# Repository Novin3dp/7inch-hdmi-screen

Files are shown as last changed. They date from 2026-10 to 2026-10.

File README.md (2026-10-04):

# برد راه‌انداز LCD هفت اینچ AT070TN92 با ورودی HDMI و تاچ USB

برد دولایه‌ی کوچک (۸۰×۵۰ میلی‌متر) که پشت LCD چسبانده می‌شود:

* **ورودی HDMI** (از رزبری‌پای) ← **LT8619C** ← RGB موازی ۲۴ بیتی (حالت DE) ← کانکتور FPC پنجاه‌پین **AT070TN92**
* **تاچ خازنی GT915** (روی FPC تاچ‌پنل، رابط I2C) ← **STM32F072** ← **USB HID Multi-Touch** (۵ نقطه) به رزبری‌پای
* **تغذیه‌ی کل برد از همان کابل USB-C** (۵ ولت از پورت USB رزبری‌پای)
* تولید ولتاژهای پنل روی برد: AVDD=10.4V، VGH=+16V، VGL=−6.8V، VCOM قابل تنظیم، درایور بک‌لایت جریان‌ثابت ۱۸۰ mA با PWM

> ⚠️ این طراحی کامل است و همه‌ی بررسی‌های نرم‌افزاری (DRC، تطبیق شماتیک با PCB، کامپایل فرم‌ور، اعتبارسنجی EDID) را پاس کرده، اما **هنوز ساخته و روی سخت‌افزار تست نشده است**. قبل از سفارش انبوه، یک نمونه بسازید و بخش «موارد قابل بررسی» را بخوانید.

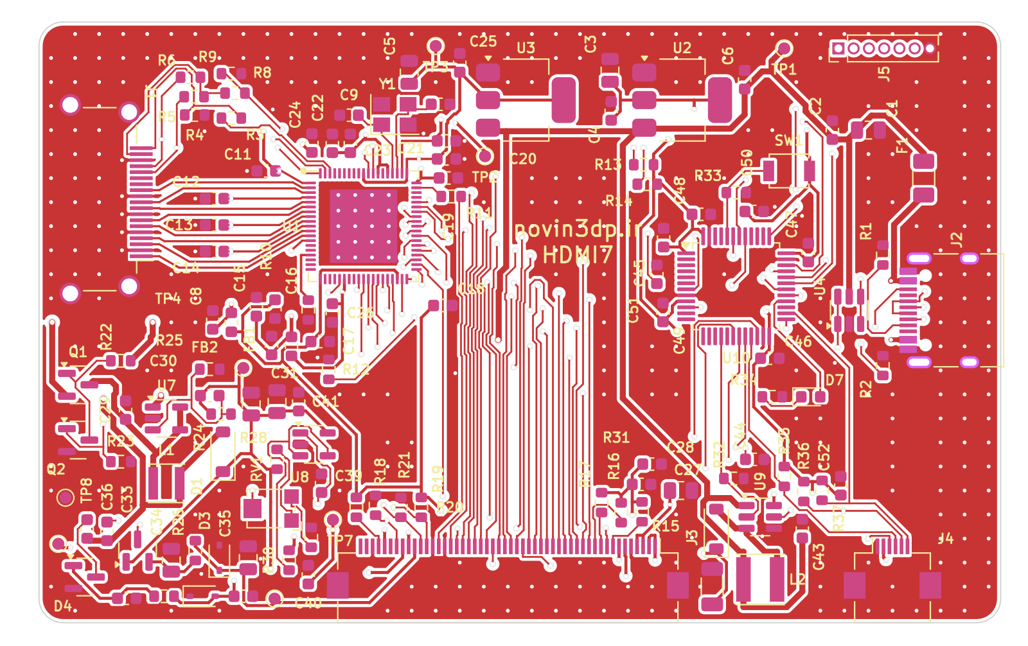
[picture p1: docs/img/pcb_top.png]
top


> **نسخه‌ی DSI:** یک برد جداگانه (۶۸×۴۲ mm) هم هست که همین پنل و تاچ را مستقیم از پورت DSI رزبری‌پای و با پل ICN6211 راه می‌اندازد، بدون HDMI و بدون میکروکنترلر. طراحی در [`hardware_dsi/`](hardware_dsi/README.md) و Overlay و درایور لینوکس در `rpi_dsi/` است.
>
> **نسخه‌ی STM32F042F6P6:** همین برد HDMI با میکروی کوچک‌تر TSSOP-20 در [`hardware_f042/`](hardware_f042/README.md). فرم‌ور با `make BOARD=f042` ساخته می‌شود.

---

## ۱) بلوک دیاگرام

```
 HDMI-A ──TMDS──► LT8619C ──RGB888 + DE + PCLK──► J3 (FPC 50P) ──► AT070TN92
   │ DDC/HPD        ▲ I2C1 (0x32)                       ▲ AVDD/VGH/VGL/VCOM, VLED
   └─(EDID روی تراشه)│                                    │
                    STM32F072 ──── BIAS_EN ──► TPS61040 + پمپ‌های بار + LM321 (VCOM)
 USB-C ◄──USB FS──► │ ──── BL_PWM ───► TPS61165 (بک‌لایت ۱۸۰mA)
   │5V              │ ──── I2C2 ────► J4 (FPC 6P) ──► تاچ‌پنل GT915
   └► PTC ► AMS1117-3.3 / AMS1117-1.8 (+ فیلتر فریت برای تغذیه‌های آنالوگ LT8619C)
```

| بخش | قطعه | توضیح |
|---|---|---|
| گیرنده HDMI | LT8619C (QFN76) | کریستال 25MHz، EDID داخلی 800×480@60 که میکرو بارگذاری می‌کند؛ VTERM/VCCA33 و 1.8V آنالوگ با فریت جدا شده‌اند |
| میکرو | STM32F072CBT6 | USB بدون کریستال (HSI48 + CRS)، بوت‌لودر DFU داخلی |
| بایاس پنل | TPS61040 + 2×BAT54S + زنر | AVDD 10.4V، VGH 16V (دوبرابرکننده)، VGL −6.8V (معکوس‌کننده) |
| VCOM | LM321 + تریمر 10k (RV1) | محدوده 2.55 تا 4.5 ولت، برای کمترین فلیکر تنظیم شود |
| بک‌لایت | TPS61165 | 0.2V / 1.1Ω = 182mA، PWM با فرکانس 20kHz |
| تغذیه | AMS1117-3.3 و AMS1117-1.8 | هر دو از 5V؛ 1.8V با فریت به تغذیه‌های آنالوگ |

---

## ۲) ساختار ریپازیتوری

```
hardware/                 پروژه‌ی KiCad (نسخه 7)
  lcd_board.kicad_pro/.kicad_sch/.kicad_pcb    پروژه، شماتیک سلسله‌مراتبی (۴ صفحه)، PCB
  lcd_board.pretty/       فوت‌پرینت‌های اختصاصی (QFN76 لونتیوم، FPC پنجاه‌پین)
  lcd_board.kicad_sym     سمبل LT8619C
  fab/                    فایل‌های ساخت: gerber.zip، BOM و CPL برای JLCPCB
  gen/                    اسکریپت‌هایی که کل طراحی را می‌سازند (منبع اصلی = design.py)
firmware/                 فرم‌ور STM32F072 (C + TinyUSB)
hardware_f042/            همین برد HDMI با STM32F042F6P6 — پروژه‌ی KiCad جدا با README خودش
hardware_dsi/             نسخه‌ی DSI (ICN6211) — پروژه‌ی KiCad جدا با README خودش
rpi_dsi/                  Device Tree Overlay و اسکریپت ساخت درایور ICN6211 برای نسخه‌ی DSI
docs/                     schematic.pdf، schematic_f042.pdf، schematic_dsi.pdf و تصاویر برد
*.pdf                     دیتاشیت‌ها
```

**منبع اصلی طراحی فایل `hardware/gen/design.py` است** (لیست قطعات و همه‌ی اتصالات). شماتیک، PCB و BOM از روی آن ساخته می‌شوند و `verify_netlist.py` تطابق شماتیک و طراحی را بررسی می‌کند. البته می‌توانید فایل‌های KiCad را مستقیم هم ویرایش کنید.

---

## ۳) مشخصات PCB

| مورد | مقدار |
|---|---|
| ابعاد | 80 × 50 mm، گوشه‌های گرد R2 |
| لایه | ۲ لایه، FR4، ضخامت پیشنهادی 1.0 یا 1.6 mm، مس 1oz |
| حداقل ترک/فاصله | 0.15 / 0.15 mm (تغذیه 0.25 و 0.5 mm) |
| ویا | سوراخ 0.3 / قطر 0.6 mm (ظرفیت استاندارد JLCPCB) |
| قطعات | **فقط روی رو (Top)**؛ پشت برد صاف است برای چسب دوطرفه |
| زمین | GND به‌صورت نت کامل مسیریابی شده + پور GND روی هر دو لایه + ~۳۰۰ ویای دوخت |
| DRC | **۰ خطای الکتریکی/فاصله و ۰ اتصال باز**؛ برچسب‌های سیلک بدون تداخل (هشدار فقط برای خطوط سیلک کانکتورهای لبه‌ی برد که سازنده برش می‌دهد) |
| سیلک‌اسکرین | برچسب‌ها با ارتفاع 0.8mm خودکار کنار هر قطعه گذاشته شده‌اند، روی پد/بدنه‌ی قطعه یا برچسب دیگر نمی‌افتند. ۱۳ برچسب در نواحی خیلی شلوغ جا نشدند و فقط در نقشه‌ی مونتاژ (`docs/img/pcb_assembly.png`) آمده‌اند |

نکات چیدمان:
* زوج‌های TMDS (HDMI) دستی و کوتاه (~۱۲ mm) کشیده شده‌اند و زیرشان لایه‌ی پشت زمین یکپارچه است. سرعت هر کانال برای 800×480 فقط 333Mbps است.
* خازن‌های دکاپلینگ پایه‌های VTERM/VCCA33 بین زوج‌های TMDS قرار گرفته‌اند.
* ترتیب پایه‌های RGB در LT8619C نسبت به FPC پنل وارونه است؛ گذرگاه RGB با ویا روی دو لایه جابه‌جا شده (بدون نیاز به رجیستر نامستند جابه‌جایی بیت).

---

## ۴) نصب مکانیکی و جهت FPC (مهم)

* FPC پنل (۳۰ میلی‌متر) از لبه‌ی پایین LCD به پشت تا می‌شود و از **لبه‌ی پایین برد** وارد J3 می‌شود. کنتاکت‌های FPC در این حالت رو به بالا (دور از برد) هستند، پس J3 باید **کانکتور Top-contact** باشد — همان چیزی که دیتاشیت Innolux پیشنهاد کرده: `Hirose FH12A-50S-0.5SH`.
* شماره‌ی پدهای J3 دقیقاً برابر شماره‌ی پین‌های FPC پنل است؛ **پین ۱ سمت راست** است (برد از رو، FPC از پایین وارد شود). همین جهت برای حالت تا‌نخورده (برد زیر پنل) هم درست است.
* برد را با **چسب دوطرفه‌ی فومی عایق** (۱ میلی‌متر) پشت پنل بچسبانید؛ پشت پنل فلزی است و ویاها با سولدرماسک پوشیده‌اند ولی عایق اضافه لازم است.
* J4 (FPC شش‌پین 0.5mm تاچ) هم روی لبه‌ی پایین است. ترتیب پین‌ها طبق مدار مرجع Goodix: `1 GND, 2 VDD(3.3V), 3 INT, 4 SCL, 5 SDA, 6 RST`. **ترتیب پین FPC تاچ‌پنل خودتان را حتماً چک کنید**؛ اگر فرق دارد، به یک تبدیل FPC یا تغییر ترتیب پین‌های J4 در `design.py` نیاز است.
* HDMI از لبه‌ی چپ و USB-C از لبه‌ی راست خارج می‌شوند.

---

## ۵) تغذیه و مصرف

| مصرف‌کننده | تقریبی |
|---|---|
| بک‌لایت (9.3V × 180mA ÷ راندمان) | ~2.0 W |
| LT8619C (1.8V و 3.3V، از LDO) | ~1.1 W از 5V |
| بایاس پنل + منطق + میکرو + تاچ | ~0.4 W |
| **جمع** | **~3.5 W ≈ 0.7 A از 5V** |

پورت‌های USB رزبری‌پای ۴ و ۵ این جریان را می‌دهند (مجموعاً 1.2A/1.6A). با کم کردن نور بک‌لایت مصرف کم می‌شود. فیوز PTC (1.1A) روی VBUS است.

ترتیب روشن شدن (طبق بخش 3.2 دیتاشیت پنل، توسط فرم‌ور):
`DVDD(3.3V) → آزاد شدن RESET → BIAS_EN (VGL و AVDD، سپس VGH با تأخیر RC) → داده‌ی تصویر → بعد از 200ms بک‌لایت`.
بک‌لایت فقط وقتی تصویر معتبر از HDMI دریافت می‌شود روشن است.

---

## ۶) ساخت برد (JLCPCB)

1. `hardware/fab/lcd_board_gerbers.zip` را برای ساخت PCB آپلود کنید (2 لایه).
2. برای مونتاژ: `hardware/fab/bom_jlcpcb.csv` و `hardware/fab/cpl_jlcpcb.csv`.
   * شماره‌های LCSC فقط برای قطعاتی که مطمئن بودم پر شده‌اند؛ بقیه را با MPN/مقدار جستجو کنید.
   * LT8619C معمولاً در LCSC نیست؛ از فروشنده‌های لونتیوم (مثلاً بازار چین) تهیه و دستی لحیم کنید (QFN76 با پد زیرین: هیتر هوای گرم/استنسیل).
   * چرخش‌ها در CPL را در پیش‌نمایش JLC کنترل کنید.
3. قطعات نصب‌نشده (DNP): J5 (هدر SWD/UART)، نقاط تست TP1..TP8.
4. همه‌ی مقاومت‌ها و خازن‌های کوچک پکیج **0603** هستند (لحیم دستی راحت). فقط چند خازن که به ظرفیت/ولتاژ بالا نیاز دارند 0805/1206 مانده‌اند (22µF، 4.7µF/25V، 1µF/50V، 2.2µF/50V) و مقاومت حسگر جریان بک‌لایت 0805 است.

---

## ۷) فرم‌ور

```sh
cd firmware
./fetch_deps.sh        # TinyUSB 0.17 + هدرهای CMSIS
make                   # نیاز به arm-none-eabi-gcc ؛ خروجی build/lcd_touch.bin
make flash-dfu         # دکمه‌ی BOOT را نگه دارید و USB را وصل کنید (dfu-util لازم است)
```

کارهایی که فرم‌ور انجام می‌دهد:
* ترتیب روشن شدن پنل و کنترل بک‌لایت
* راه‌اندازی LT8619C: ریست، خواندن Chip ID (0x16 0x04)، بارگذاری EDID (800×480@60Hz، 33.26MHz)، HPD، پیکربندی گیرنده و خروجی RGB888 SDR، تبدیل رنگ YCbCr→RGB، کپی تایمینگ ورودی به خروجی
* انتخاب آدرس GT915 (0x5D) با ترتیب INT/RESET دیتاشیت، خواندن رزولوشن تنظیم‌شده‌ی تاچ و مقیاس‌کردن به 800×480
* دستگاه USB HID «Touch Screen» پنج‌نقطه‌ای؛ لینوکس (hid-multitouch) بدون درایور اضافه می‌شناسد
* کنسول UART (پین‌های 5 و 6 هدر J5، 115200): دستورات `status`، `bl 0..100`، `phase 0..9`، `rot 0|1`، `swap`، `invx`، `invy`، `save`
* تنظیمات (نور، چرخش ۱۸۰ درجه، جهت تاچ، فاز PCLK) در فلش ذخیره می‌شوند

---

## ۸) تنظیم رزبری‌پای

با Raspberry Pi OS (KMS) معمولاً هیچ تنظیمی لازم نیست: EDID برد حالت 800×480 را اعلام می‌کند و تاچ به‌صورت خودکار شناخته می‌شود. اگر تصویر نیامد، در `/boot/firmware/cmdline.txt` اضافه کنید:

```
video=HDMI-A-1:800x480M@60
```

و برای Pi های قدیمی (درایور غیر KMS) در `config.txt`:

```
hdmi_group=2
hdmi_mode=87
hdmi_cvt=800 480 60 6 0 0 0
hdmi_drive=1
```

برای چرخاندن ۱۸۰ درجه بهتر است از دستور `rot 1` کنسول برد استفاده کنید (پنل و تاچ هر دو در سخت‌افزار برمی‌گردند).

---

## ۹) موارد قابل بررسی و ریسک‌ها (لطفاً بخوانید)

1. **LT8619C سند رسمی رجیستر ندارد.** توالی رجیسترها از درایورهای متن‌باز (Hardkernel u-boot و درایور V4L2 راک‌چیپ) گرفته شده و برای خروجی RGB888 کار کرده است. اگر رنگ‌ها لرزش/نویز داشتند فاز PCLK را با `phase 0..9` تغییر دهید. برای تولید، از Lontium (support@lontium.com) شماتیک مرجع و Programming Guide بخواهید.
2. در گزارش موجود در ریپازیتوری گفته شده که خطوط TMDS با خازن 100nF کوپل AC شوند؛ **این برای HDMI درست نیست** — TMDS کوپل DC است و ترمینیشن به 3.3V از پایه‌های VTERM می‌آید. در این برد اتصال مستقیم است.
3. جهت FPC پنل و نوع کانکتور Top-contact (بخش ۴) را قبل از لحیم کنترل کنید.
4. ترتیب پین FPC تاچ‌پنل شما ممکن است با ترتیب مرجع Goodix فرق داشته باشد.
5. GT915 برای پنل‌های ۴.۵ تا ۶ اینچ طراحی شده؛ پیکربندی (Config) آن را سازنده‌ی تاچ‌پنل در فلش آی‌سی ذخیره کرده است. اگر محورها برعکس بود با `swap/invx/invy` اصلاح کنید.
6. VCOM هر پنل باید با RV1 برای کمترین فلیکر تنظیم شود (نقطه‌ی تست TP7). مقدار معمول طبق دیتاشیت ~3.6V.
7. محافظ ESD روی خطوط TMDS عمداً حذف شده تا مسیرها کوتاه و تمیز بمانند (سیگنال‌ها مستقیم به LT8619C می‌روند).
8. پین‌اوت آی‌سی‌ها از کتابخانه‌ی رسمی KiCad برداشته شده و پین‌اوت TPS61040 و TPS61165 با دیتاشیت TI چک شد؛ فوت‌پرینت QFN76 از ابعاد صفحه 16 دیتاشیت LT8619C ساخته شده (پد زیرین 5.81×6.31mm).
9. VID/PID USB از `pid.codes` (آزمایشی 1209:0001) است؛ برای محصول تجاری عوض کنید.

---

## ۱۰) ساخت دوباره‌ی طراحی از اسکریپت‌ها

نیازمندی‌ها: KiCad 7 (`kicad-cli` و ماژول پایتون `pcbnew`)، Java و Xvfb برای Freerouting.

```sh
cd hardware/gen
python3 make_libs.py                 # فوت‌پرینت/سمبل اختصاصی
python3 gen_sch.py                   # شماتیک
python3 verify_netlist.py            # تطبیق شماتیک با design.py
python3.12 pcb.py                    # چیدمان + مسیرهای دستی (TMDS، USB، VCOM، I2C و تغذیه آنالوگ LT8619C)
python3.12 route.py export           # فایل DSN برای Freerouting
java -jar freerouting-2.0.1.jar --gui.enabled=false -de ../lcd_board.dsn -do ../lcd_board.ses -mp 100
python3.12 route.py import ../lcd_board.ses   # مسیرها + پورها + ویاهای دوخت
python3.12 check.py --fill           # پر کردن پورها و DRC
python3 fab.py                       # گربر، BOM، CPL، تصاویر و PDF شماتیک
```

فایل `hardware/lcd_board.ses` (خروجی Freerouting که برد فعلی از آن ساخته شده) در ریپازیتوری هست، پس بدون اجرای دوباره‌ی Freerouting هم `route.py import` همین برد را می‌سازد.

## مجوز

سخت‌افزار: CERN-OHL-P v2. فرم‌ور: GPL-2.0-or-later (چون توالی LT8619C از کد GPL گرفته شده).

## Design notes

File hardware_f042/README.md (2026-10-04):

# HDMI7 با میکروکنترلر STM32F042F6P6

این پروژه‌ی جدا همان برد HDMI7 است (HDMI ← LT8619C ← AT070TN92، تاچ GT915 ← USB HID)، فقط میکروی **STM32F072CBT6 (LQFP-48)** با **STM32F042F6P6 (TSSOP-20)** عوض شده. ابعاد (80×50mm)، جای کانکتورها و همه‌ی بخش‌های دیگر مثل نسخه‌ی اصلی در `hardware/` است.

> ⚠️ همه‌ی بررسی‌های نرم‌افزاری پاس شده‌اند (DRC، تطبیق شماتیک با PCB، کامپایل فرم‌ور)، ولی برد **هنوز ساخته و تست نشده است**.

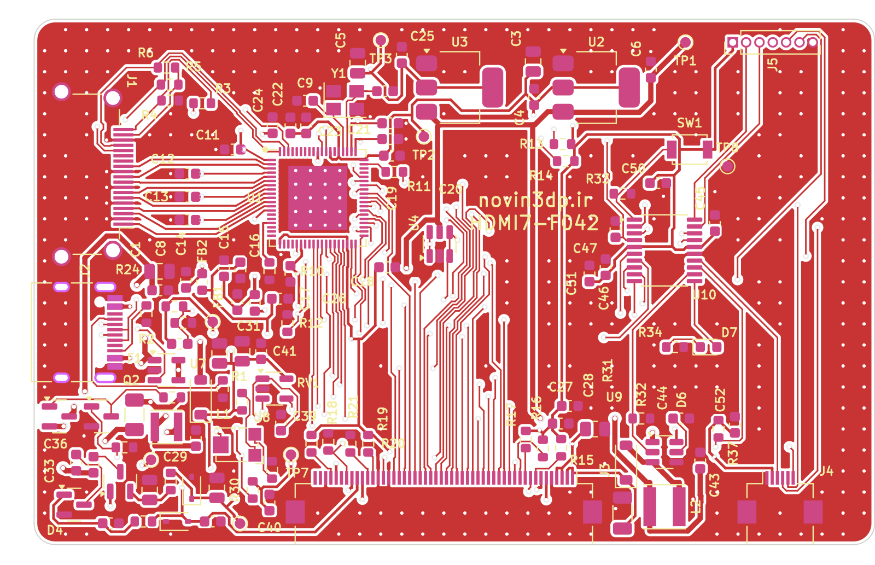
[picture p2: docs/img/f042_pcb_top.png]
top


---

## ۱) چرا F042 جواب می‌دهد

| نیاز | STM32F042F6P6 |
|---|---|
| USB بدون کریستال | دارد (HSI48 + CRS، مثل F072). پایه‌های 17 و 18 با remap می‌شوند PA11/PA12 |
| بوت‌لودر DFU از USB | دارد (دکمه‌ی BOOT روی پایه‌ی ۱ = BOOT0) |
| حافظه | فرم‌ور 20.8KB از 32KB فلش و حدود 3.3KB از 6KB رم (با استک) |
| I2C | فقط **یک** I2C دارد. LT8619C (آدرس 0x32) و GT915 (آدرس 0x5D) روی یک باس با سرعت 400kHz هستند؛ هر دو این سرعت را پشتیبانی می‌کنند |
| PWM بک‌لایت | TIM3_CH1 روی PA6 (مثل قبل) |
| کنسول UART | USART2 روی PA2/PA3 (هدر J5، پایه‌های ۵ و ۶) |

## ۲) فرق با نسخه‌ی F072

**جای USB-C:** در این نسخه کانکتور USB-C در **لبه‌ی چپ، درست زیر سوکت HDMI** است. به این ترتیب هر دو کابل رزبری‌پای (HDMI و USB) از یک طرف برد خارج می‌شوند. آی‌سی محافظ ESD (U4) روی مسیر USB به سمت میکرو قرار گرفته، چون کنار کانکتور جا نبود. بخش سوئیچ تغذیه‌ی بایاس (Q1، Q2 و TPS61040) کمی جابه‌جا شده است.

TSSOP-20 فقط ۱۵ پایه‌ی I/O دارد، پس دو چیز حذف شد:

1. **جهت اسکن پنل (L/R و U/D) با مقاومت تعیین می‌شود، نه با میکرو.** پیش‌فرض: R19 (L/R) به 3.3V و R20 (U/D) به زمین (تصویر عادی). برای چرخش ۱۸۰ درجه، R19 را به زمین و R20 را به 3.3V ببندید و در کنسول `rot 1` را بزنید تا تاچ هم برگردد. راه دیگر چرخاندن تصویر در خود رزبری‌پای است.
2. **ورودی تشخیص 5V کابل HDMI (و مقاومت‌های R8/R9) حذف شد.** فرم‌ور وجود تصویر را مثل قبل از خود LT8619C می‌خواند؛ فقط خط «HDMI +5V» از دستور `status` کنسول حذف شده است.

پایه‌های میکرو:

| پایه | سیگنال | پایه | سیگنال |
|---|---|---|---|
| 1 | BOOT0 (دکمه SW1) | 11 | PA5: LED |
| 2 | PF0: I2C_SDA | 12 | PA6: BL_PWM |
| 3 | PF1: I2C_SCL | 13 | PA7: TP_RST |
| 4 | NRST | 14 | PB1: TP_INT |
| 5 | VDDA | 15 | VSS |
| 6 | PA0: LT_RSTN | 16 | VDD |
| 7 | PA1: BIAS_EN | 17 | PA11: USB D− |
| 8 | PA2: UART TX | 18 | PA12: USB D+ |
| 9 | PA3: UART RX | 19 | PA13: SWDIO |
| 10 | PA4: LCD_RST | 20 | PA14: SWCLK |

مقاومت‌های pull-up باس I2C مشترک: R13/R14 با مقدار 2.2k (R35/R36 حذف شدند).

## ۳) فرم‌ور

فرم‌ور همان کد `firmware/` است با یک هدف ساخت جدا:

```sh
cd firmware
./fetch_deps.sh
make BOARD=f042              # خروجی: build_f042/lcd_touch_f042.bin
make BOARD=f042 flash-dfu    # دکمه‌ی BOOT را نگه دارید و USB را وصل کنید
```

## ۴) مشخصات PCB و ساخت

| مورد | مقدار |
|---|---|
| ابعاد | 80 × 50 mm، ۲ لایه (مثل نسخه‌ی اصلی) |
| قطعات | ۱۲۰ (۶ قطعه کمتر از نسخه‌ی F072) |
| DRC | **۰ خطا و ۰ اتصال باز**. یک هشدار سیلک مربوط به علامت پایه‌ی ۱ فوت‌پرینت استاندارد TSSOP است و ۸ هشدار خطوط سیلک کانکتورها در لبه‌ی برد |
| سیلک | ۹۵ برچسب کنار قطعات است؛ ۲۵ برچسب در ناحیه‌ی شلوغ سمت چپ جا نشدند و فقط در نقشه‌ی مونتاژ `docs/img/f042_pcb_assembly.png` آمده‌اند |
| فایل‌ها | `fab/lcd_f042_gerbers.zip`، `fab/bom_jlcpcb.csv`، `fab/cpl_jlcpcb.csv`؛ شماتیک: `docs/schematic_f042.pdf` |

ساخت دوباره از اسکریپت‌ها مثل نسخه‌ی اصلی است (بخش ۱۰ README اصلی)، فقط در پوشه‌ی `hardware_f042/gen` و با فایل‌های `lcd_f042.*`.

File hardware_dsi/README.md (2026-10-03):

# نسخه‌ی DSI: راه‌اندازی AT070TN92 مستقیم از پورت DSI رزبری‌پای

این برد دولایه (۶۸×۴۲ میلی‌متر) همان پنل ۷ اینچ AT070TN92 و تاچ GT915 را این بار از **پورت DSI رزبری‌پای** راه می‌اندازد. نسخه‌ی HDMI در پوشه‌ی `hardware/` دست‌نخورده باقی مانده است.

* **DSI رزبری‌پای** (۲ لِین) ← **ICN6211** (مبدل MIPI-DSI به RGB888) ← کانکتور FPC پنجاه‌پین پنل
* **تاچ GT915** مستقیم روی **I2C کانکتور DSI**؛ درایور `goodix` لینوکس آن را می‌خواند. میکروکنترلر و USB حذف شده‌اند.
* **۵ ولت و ۴ سیگنال کنترلی** با یک کابل ۸ رشته از هدر ۴۰ پین رزبری‌پای می‌آیند (کابل DSI تغذیه‌ی ۵ ولت ندارد).
* بخش تغذیه‌ی پنل (AVDD، VGH، VGL، VCOM) و درایور بک‌لایت همان مدارهای نسخه‌ی HDMI هستند.

> ⚠️ این طراحی همه‌ی بررسی‌های نرم‌افزاری را پاس کرده: DRC، تطبیق شماتیک با PCB و کامپایل Overlay. ولی **هنوز ساخته و روی سخت‌افزار تست نشده است**. بخش «ریسک‌ها» را حتماً بخوانید.

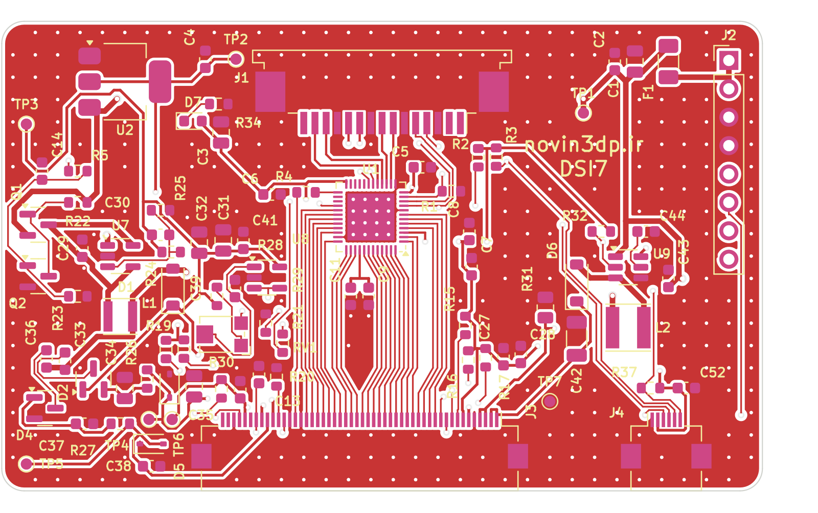
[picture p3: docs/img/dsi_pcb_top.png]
top


---

## ۱) بلوک دیاگرام

```
 Pi DSI (15P 1mm) ──D0,D1,CLK──► ICN6211 ──RGB888 + DE + PCLK──► J3 (FPC 50P) ──► AT070TN92
        │ SDA/SCL (i2c_csi_dsi)                                     ▲ AVDD/VGH/VGL/VCOM, VLED
        └──────────────────────────► J4 (FPC 6P) ──► تاچ GT915      │
 Pi 40-pin ──J2──► 5V ─► PTC ─► AMS1117-3.3 ─► 3.3V (ICN6211، منطق پنل، تاچ)
                  DSI_EN (GPIO22) ─► EN آی‌سی، RESET پنل (۱ms)، BIAS_EN (RC حدود ۵۰ms) ─► TPS61040 + پمپ‌های بار + LM321
                  TP_INT (GPIO27)، TP_RST (GPIO17) ─► تاچ
                  BL_PWM (GPIO18) ─► TPS61165 (بک‌لایت ۱۸۰mA؛ پیش‌فرض روشن)
```

| بخش | قطعه | توضیح |
|---|---|---|
| مبدل DSI | ICN6211 (QFN48 6×6، LCSC C246085) | هر سه تغذیه 3.3V، کلاک مرجع از کلاک DSI (پایه REF_CLK به زمین)، VCORE با 1µF + 10nF |
| بایاس پنل | TPS61040 + 2×BAT54S + زنر | AVDD 10.4V، VGH 16V، VGL −6.8V |
| VCOM | LM321 + تریمر RV1 | 2.55 تا 4.5 ولت |
| بک‌لایت | TPS61165 | 182mA، روشن/خاموش یا PWM از GPIO18 |
| تغذیه | AMS1117-3.3 | از 5V هدر |

**ترتیب روشن شدن کاملاً سخت‌افزاری است.** وقتی لینوکس پایه‌ی EN پل را بالا می‌برد، RESET پنل بعد از حدود ۱ms آزاد می‌شود. بعد از حدود ۵۰ms هم تغذیه‌های AVDD، VGL و VGH روشن می‌شوند. با خاموش شدن نمایشگر (EN پایین) همه‌ی این‌ها با هم خاموش می‌شوند.

---

## ۲) اتصال به رزبری‌پای

### کابل DSI (J1)

* J1 یک کانکتور FPC پانزده‌پین با گام 1mm است، با همان پین‌اوت کانکتور DSI در Pi 3 و Pi 4.
* **Pi 5 و CM4/CM5** کانکتور ۲۲ پین 0.5mm دارند. برای آن‌ها از کابل استاندارد «Raspberry Pi Display Cable 22-pin to 15-pin» استفاده کنید.
* **جهت کابل:** برای J1 یک کانکتور **Dual-contact** (کنتاکت در بالا و پایین) بگذارید. اگر تصویر نیامد، کابل را در سمت برد **برعکس** (رو به پایین) جا بزنید؛ این کار ترتیب پین‌ها را آینه می‌کند.
* پایه‌های ۱، ۱۴ و ۱۵ کانکتور روی برد عمداً **وصل نیستند**: پین ۱ زمین است و ۱۴ و ۱۵ تغذیه‌ی 3.3V رزبری‌پای. برای همین اگر کابل برعکس جا خورد، 3.3V رزبری‌پای به زمین اتصال کوتاه نمی‌شود. زمین از پایه‌های ۴، ۷، ۱۰ و ۱۳ وصل است.

### کابل هدر (J2، هدر ۸ پین 2.54mm)

| J2 | سیگنال | پین هدر رزبری‌پای |
|---|---|---|
| 1 | +5V | 2 |
| 2 | +5V | 4 |
| 3 | GND | 6 |
| 4 | GND | 9 |
| 5 | DSI_EN (EN آی‌سی ICN6211) | 15 (GPIO22) |
| 6 | TP_INT | 13 (GPIO27) |
| 7 | TP_RST | 11 (GPIO17) |
| 8 | BL_PWM (بک‌لایت) | 12 (GPIO18) |

اگر GPIO دیگری لازم دارید، پارامترهای Overlay را عوض کنید (بخش ۳). بدون سیم BL_PWM بک‌لایت همیشه روشن است (مقاومت pull-up 10k).

### تاچ (J4)

ترتیب پین‌ها مثل نسخه‌ی HDMI است: `1 GND, 2 3.3V, 3 INT, 4 SCL, 5 SDA, 6 RST`. خطوط SCL و SDA به I2C کانکتور DSI وصل‌اند. **ترتیب پین FPC تاچ‌پنل خودتان را چک کنید.**

### مصرف

بک‌لایت حدود 2W، پنل و ICN6211 حدود 0.4W: در مجموع **حدود 0.5A از 5V هدر**. منبع تغذیه‌ی رزبری‌پای باید این جریان اضافه را بدهد (منبع رسمی 3A/5A کافی است).

---

## ۳) نرم‌افزار رزبری‌پای

درایور لینوکس ICN6211 (`chipone-icn6211`) در کرنل اصلی لینوکس هست، **ولی در کرنل Raspberry Pi OS فعال نشده**. اسکریپت `rpi_dsi/icn6211/install.sh` سورس همان نسخه‌ی کرنل را از گیت‌هاب Raspberry Pi دانلود می‌کند. بعد ماژول را می‌سازد و نصب می‌کند، Overlay را کامپایل می‌کند و خط لازم را به `config.txt` اضافه می‌کند:

```sh
sudo apt install linux-headers-rpi-v8 device-tree-compiler   # Pi 5: linux-headers-rpi-2712
cd rpi_dsi/icn6211
sudo ./install.sh
sudo reboot
```

بعد از هر به‌روزرسانی کرنل، `install.sh` را دوباره اجرا کنید.

فایل `rpi_dsi/at070tn92-dsi-overlay.dts` این‌ها را تعریف می‌کند:
* پل `chipone,icn6211` روی DSI1 با ۲ لِین و EN روی GPIO22
* پنل `panel-dpi` با تایمینگ دیتاشیت AT070TN92: 33.3MHz، HFP 210، HBP+HS 46، VFP 22، VBP+VS 23. حالت DE فعال است و داده در لبه‌ی بالارونده‌ی کلاک فرستاده می‌شود، چون پنل در لبه‌ی پایین‌رونده نمونه می‌گیرد.
* بک‌لایت `gpio-backlight` روی GPIO18
* تاچ `goodix` با آدرس 0x5D روی `i2c_csi_dsi`، INT روی GPIO27 و RST روی GPIO17

پارامترهای Overlay (در `config.txt`، مثلاً `dtoverlay=at070tn92-dsi,touch_invx,touch_invy`):

| پارامتر | کار |
|---|---|
| `dsi0` | استفاده از پورت DSI0 (روی Pi 5: DISP0؛ روی CM: DSI0) |
| `enable_gpio=N` / `backlight_gpio=N` / `touch_int=N` / `touch_reset=N` | تغییر GPIOها |
| `touch_invx` / `touch_invy` / `touch_swapxy` | اصلاح جهت تاچ |
| `touch_addr=0x14` / `disable_touch` | آدرس دیگر تاچ / غیرفعال کردن تاچ |
| `clock-frequency=N` | فرکانس پیکسل (پیش‌فرض 33300000) |

چرخش ۱۸۰ درجه: در دسکتاپ از Screen Configuration، یا با سخت‌افزار: R19/R20 (پایه‌های L/R و U/D پنل) را برعکس ببندید و تاچ را با `touch_invx,touch_invy` برگردانید.

---

## ۴) مشخصات PCB

| مورد | مقدار |
|---|---|
| ابعاد | 68 × 42 mm، گوشه‌های گرد R2 (نسخه‌ی HDMI: 80×50) |
| لایه | ۲ لایه، FR4، مس 1oz |
| حداقل ترک/فاصله | 0.15 / 0.15 mm؛ ویا 0.3/0.6 mm (ظرفیت استاندارد JLCPCB) |
| قطعات | ۸۵ قطعه، **فقط روی رو (Top)** |
| زوج‌های DSI | دستی کشیده شده‌اند (حدود ۸ میلی‌متر، ترک 0.2mm). ترتیب لِین‌ها در کانکتور رزبری‌پای و ICN6211 یکی نیست، برای همین زوج کلاک برای عبور از زیر لِین ۱ از لایه‌ی پشت می‌رود (۴ ویا). |
| گذرگاه RGB | ۲۶ خط RGB/DE/DCLK دستی و منظم کشیده شده‌اند: هر خط ستون خودش را دارد و با زاویه‌ی ۳۰ درجه به پد FPC می‌رسد. فقط DE از زیر گذرگاه روی لایه‌ی پشت رد می‌شود. بقیه‌ی نت‌ها با Freerouting کشیده شده‌اند. |
| DRC | **۰ خطا و ۰ اتصال باز**؛ ۸۲ برچسب سیلک بدون تداخل، ۳ برچسب (C40، D3، R18) فقط در نقشه‌ی مونتاژ `docs/img/dsi_pcb_assembly.png` آمده‌اند |

---

## ۵) ساخت (JLCPCB)

1. `hardware_dsi/fab/lcd_dsi_gerbers.zip` برای ساخت PCB.
2. `hardware_dsi/fab/bom_jlcpcb.csv` و `cpl_jlcpcb.csv` برای مونتاژ. شماره‌ی LCSC آی‌سی ICN6211: C246085 (موجودی را هنگام سفارش چک کنید).
3. نقاط تست TP1..TP7 نصب نمی‌شوند. J2 (هدر) را خودتان لحیم کنید.

---

## ۶) ریسک‌ها و نکات (لطفاً بخوانید)

1. **ترتیب رنگ‌ها:** درایور لینوکس رجیستر جابه‌جایی RGB را تنظیم نمی‌کند. طبق راهنمای Chipone فرض شده که حالت پیش‌فرض `DATA[7:0]=R`، `DATA[15:8]=G` و `DATA[23:16]=B` است. اگر قرمز و آبی جابه‌جا بودند، ایراد از این فرض است. می‌توان آن را با یک خط در درایور (رجیستر SYS_CTRL) اصلاح کرد.
2. **جهت کابل DSI** (بخش ۲): کانکتور Dual-contact بگذارید و اگر تصویر نیامد کابل را در سمت برد برعکس کنید.
3. امپدانس زوج‌های DSI روی برد ۲ لایه دقیقاً 100Ω نیست. ولی مسیرها کوتاه‌اند (حدود ۸mm) و سرعت هر لِین برای 800×480 فقط حدود 400Mbps است. ضخامت 1.0mm برای برد بهتر است.
4. پل I2C کانکتور DSI به pull-up نیاز دارد؛ R2/R3 (4.7k به 3.3V برد) روی برد هستند. برد را قبل یا هم‌زمان با رزبری‌پای روشن کنید (هر دو از یک 5V تغذیه می‌شوند).
5. درایور goodix شناسه‌ی GT915 را از خود آی‌سی می‌خواند. Config تاچ‌پنل در فلش GT915 است. اگر محورها برعکس بود از پارامترهای `touch_*` استفاده کنید.
6. VCOM هر پنل را با RV1 برای کمترین فلیکر تنظیم کنید (نقطه‌ی تست TP6).
7. جهت FPC پنل و کانکتور Top-contact مثل نسخه‌ی HDMI است (بخش ۴ README اصلی).

---

## ۷) ساخت دوباره از اسکریپت‌ها

اسکریپت‌های عمومی (`sexpr`، `symlib`، `silk`) از `hardware/gen` استفاده می‌شوند؛ بقیه در `hardware_dsi/gen` هستند و منبع اصلی طراحی فایل `design.py` است.

```sh
cd hardware_dsi/gen
python3 make_libs.py && python3 gen_sch.py && python3 verify_netlist.py
python3.12 pcb.py                         # چیدمان + زوج‌های DSI + خروجی‌های کوتاه پایه‌های ICN6211
python3.12 route.py export
java -jar freerouting-2.0.1.jar --gui.enabled=false -de ../lcd_dsi.dsn -do ../lcd_dsi.ses -mp 100 --router.via_costs=30
python3.12 route.py import ../lcd_dsi.ses
python3.12 check.py --fill
python3 fab.py
```

فایل `lcd_dsi.ses` (مسیرهای برد فعلی) در ریپازیتوری هست.

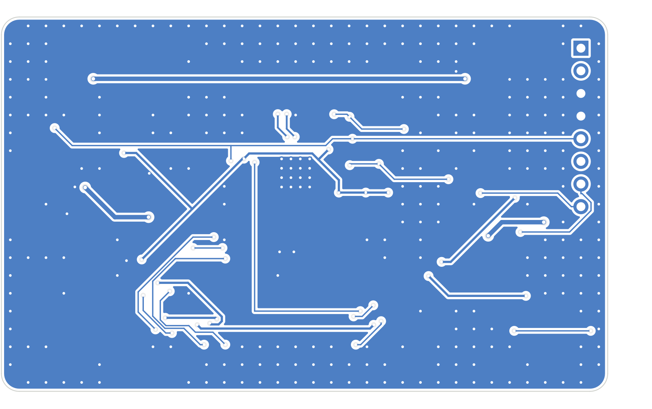
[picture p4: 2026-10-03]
docs/img/dsi_pcb_bottom.png

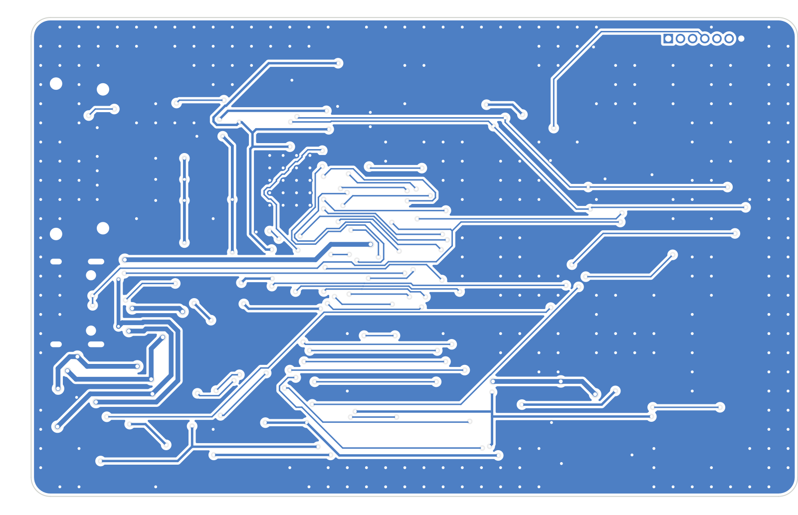
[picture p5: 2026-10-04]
docs/img/f042_pcb_bottom.png

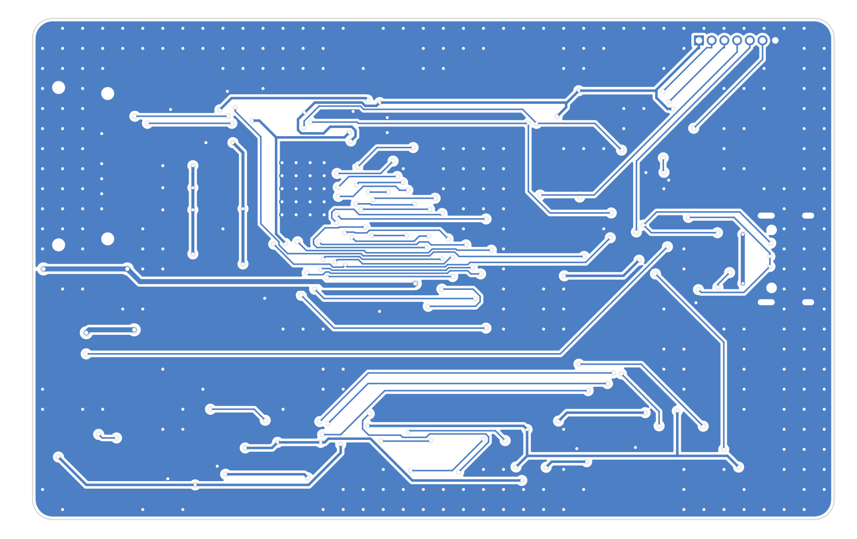
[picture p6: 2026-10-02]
docs/img/pcb_bottom.png

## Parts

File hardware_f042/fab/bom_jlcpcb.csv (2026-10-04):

Comment | Designator | Footprint | MPN | LCSC Part # | Qty
BOOT (DFU) | SW1 | SW_SPST_B3U-1000P | Omron B3U-1000P |  | 1
100nF | C2,C4,C11,C12,C13,C14,C15,C16,C17,C18,C19,C20,C21,C22,C23,C24,C28,C39,C41,C45,C46,C51 | C_0603_1608Metric |  | C14663 | 22
100nF 50V | C33,C36 | C_0603_1608Metric |  | C14663 | 2
10pF | C30 | C_0603_1608Metric |  |  | 1
10uF | C6,C7,C8,C25,C26,C29,C43 | C_0603_1608Metric |  | C19702 | 7
18pF | C9,C10 | C_0603_1608Metric |  |  | 2
1uF | C27,C40,C47,C52 | C_0603_1608Metric |  | C15849 | 4
1uF 25V | C37,C38 | C_0603_1608Metric |  | C15849 | 2
220nF | C44 | C_0603_1608Metric |  |  | 1
4.7uF | C50 | C_0603_1608Metric |  |  | 1
1uF 50V | C34 | C_0805_2012Metric |  |  | 1
22uF | C1,C3,C5 | C_0805_2012Metric |  |  | 3
4.7uF 25V | C31,C32,C35 | C_0805_2012Metric |  |  | 3
2.2uF 50V | C42 | C_1206_3216Metric |  |  | 1
Touch FPC 6P 0.5mm | J4 | Hirose_FH12-6S-0.5SH_1x06-1MP_P0.50mm_Horizontal | Hirose FH12-6S-0.5SH (check contact side of your CTP) |  | 1
HDMI-A receptacle | J1 | HDMI_A_Amphenol_10029449-x01xLF_Horizontal | Amphenol 10029449-001RLF (or equivalent SMT HDMI-A) |  | 1
USB-C (power + touch USB) | J2 | USB_C_Receptacle_HRO_TYPE-C-31-M-12 | HRO TYPE-C-31-M-12 | C165948 | 1
25MHz 12pF | Y1 | Crystal_SMD_3225-4Pin_3.2x2.5mm | X322525MOB4SI (25MHz CL=12pF) |  | 1
MBR0530 | D1 | D_SOD-123 | MBR0530T1G |  | 1
MBR0560 | D6 | D_SOD-123 | MBR0560T1G |  | 1
16V 2% | D3 | D_SOD-323 | BZX384-B16 |  | 1
6.8V 2% | D5 | D_SOD-323 | BZX384-B6V8 |  | 1
PTC 1.1A hold | F1 | Fuse_1206_3216Metric | 1206L110/16 (or BSMD1206-110) |  | 1
600R@100MHz | FB1,FB2 | L_0603_1608Metric | BLM18PG601SN1D |  | 2
10uH 0.6A | L1 | L_Taiyo-Yuden_NR-30xx | NR3015T100M |  | 1
10uH 1.2A | L2 | L_Taiyo-Yuden_NR-40xx | NR4018T100M |  | 1
green | D7 | LED_0603_1608Metric |  |  | 1
STM32F042F6P6 | U10 | TSSOP-20_4.4x6.5mm_P0.65mm | STM32F042F6P6 |  | 1
AMS1117-1.8 | U3 | SOT-223-3_TabPin2 | AMS1117-1.8 |  | 1
AMS1117-3.3 | U2 | SOT-223-3_TabPin2 | AMS1117-3.3 | C6186 | 1
2N7002 | Q2 | SOT-23 | 2N7002 | C8545 | 1
AO3401A | Q1 | SOT-23 | AO3401A | C15127 | 1
BAT54S | D2,D4 | SOT-23 | BAT54S |  | 2
LM321 | U8 | SOT-23-5 | LM321MFX |  | 1
TPS61040 | U7 | SOT-23-5 | TPS61040DBVR |  | 1
TPS61165 | U9 | SOT-23-6 | TPS61165DBVR |  | 1
USBLC6-2SC6 | U4 | SOT-23-6 | USBLC6-2SC6 | C7519 | 1
10k trim (VCOM) | RV1 | Potentiometer_Bourns_TC33X_Vertical | Bourns TC33X-2-103E |  | 1
100k | R4,R22,R23,R32 | R_0603_1608Metric |  | C25803 | 4
100k 1% | R25 | R_0603_1608Metric |  | C25803 | 1
10k | R12,R15,R16,R17,R18,R19,R20,R21,R33,R37 | R_0603_1608Metric |  | C25804 | 10
13k 1% | R29 | R_0603_1608Metric |  |  | 1
1k | R3,R34 | R_0603_1608Metric |  | C21190 | 2
2.2k | R13,R14,R26,R27 | R_0603_1608Metric |  |  | 4
22R | R11 | R_0603_1608Metric |  |  | 1
2k 1% | R10 | R_0603_1608Metric |  |  | 1
30k 1% | R28 | R_0603_1608Metric |  |  | 1
33R | R30 | R_0603_1608Metric |  |  | 1
47k | R5,R6 | R_0603_1608Metric |  |  | 2
5.1k | R1,R2 | R_0603_1608Metric |  | C23186 | 2
750k 1% | R24 | R_0603_1608Metric |  |  | 1
1.1R 1% | R31 | R_0805_2012Metric |  |  | 1
AT070TN92 FPC (0.5mm 50P, top contact) | J3 | FPC_50P_P0.5_TopContact_AT070TN92 | Hirose FH12A-50S-0.5SH(55) (top contact) |  | 1
LT8619C | U1 | Lontium_QFN-76_9x9mm_P0.4mm_EP5.81x6.31mm | LT8619C (Lontium) |  | 1

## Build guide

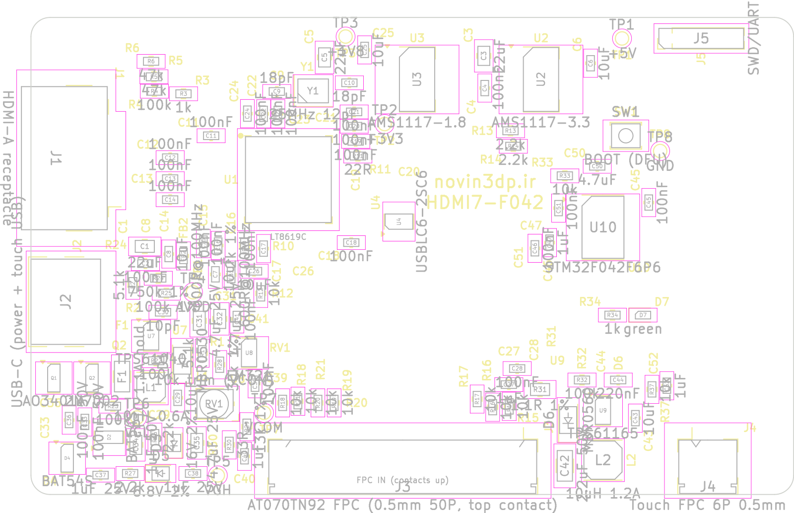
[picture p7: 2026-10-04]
docs/img/f042_pcb_assembly.png

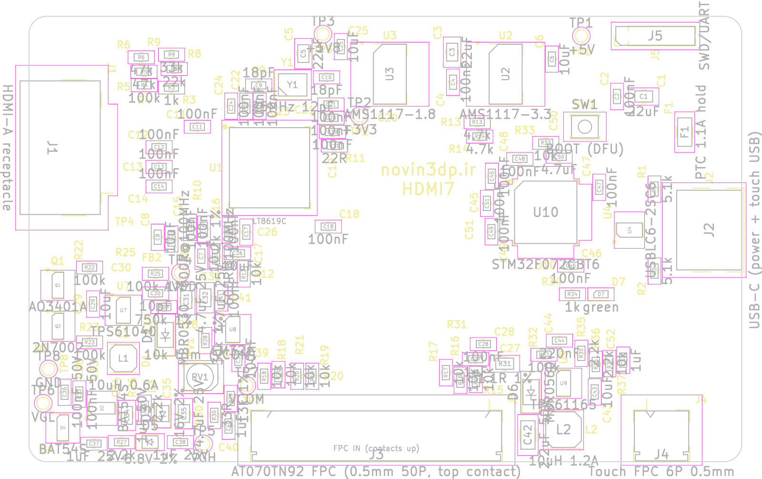
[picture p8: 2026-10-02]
docs/img/pcb_assembly.png

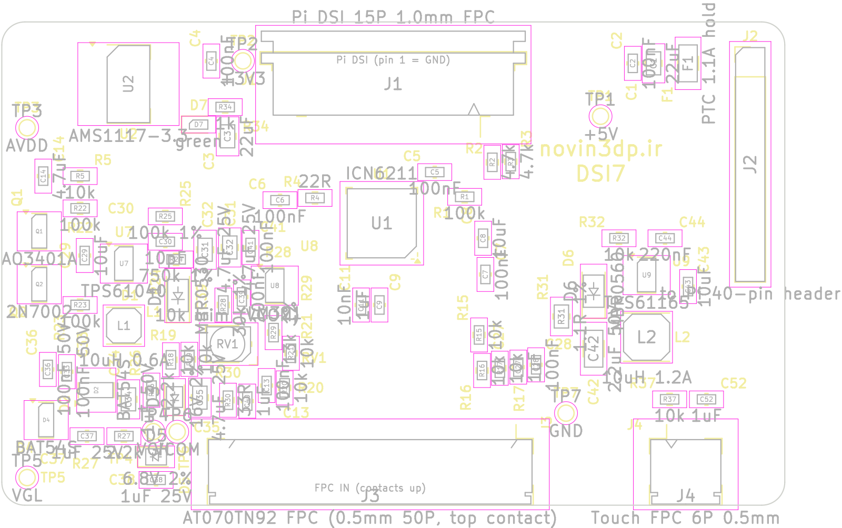
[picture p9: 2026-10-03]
docs/img/dsi_pcb_assembly.png

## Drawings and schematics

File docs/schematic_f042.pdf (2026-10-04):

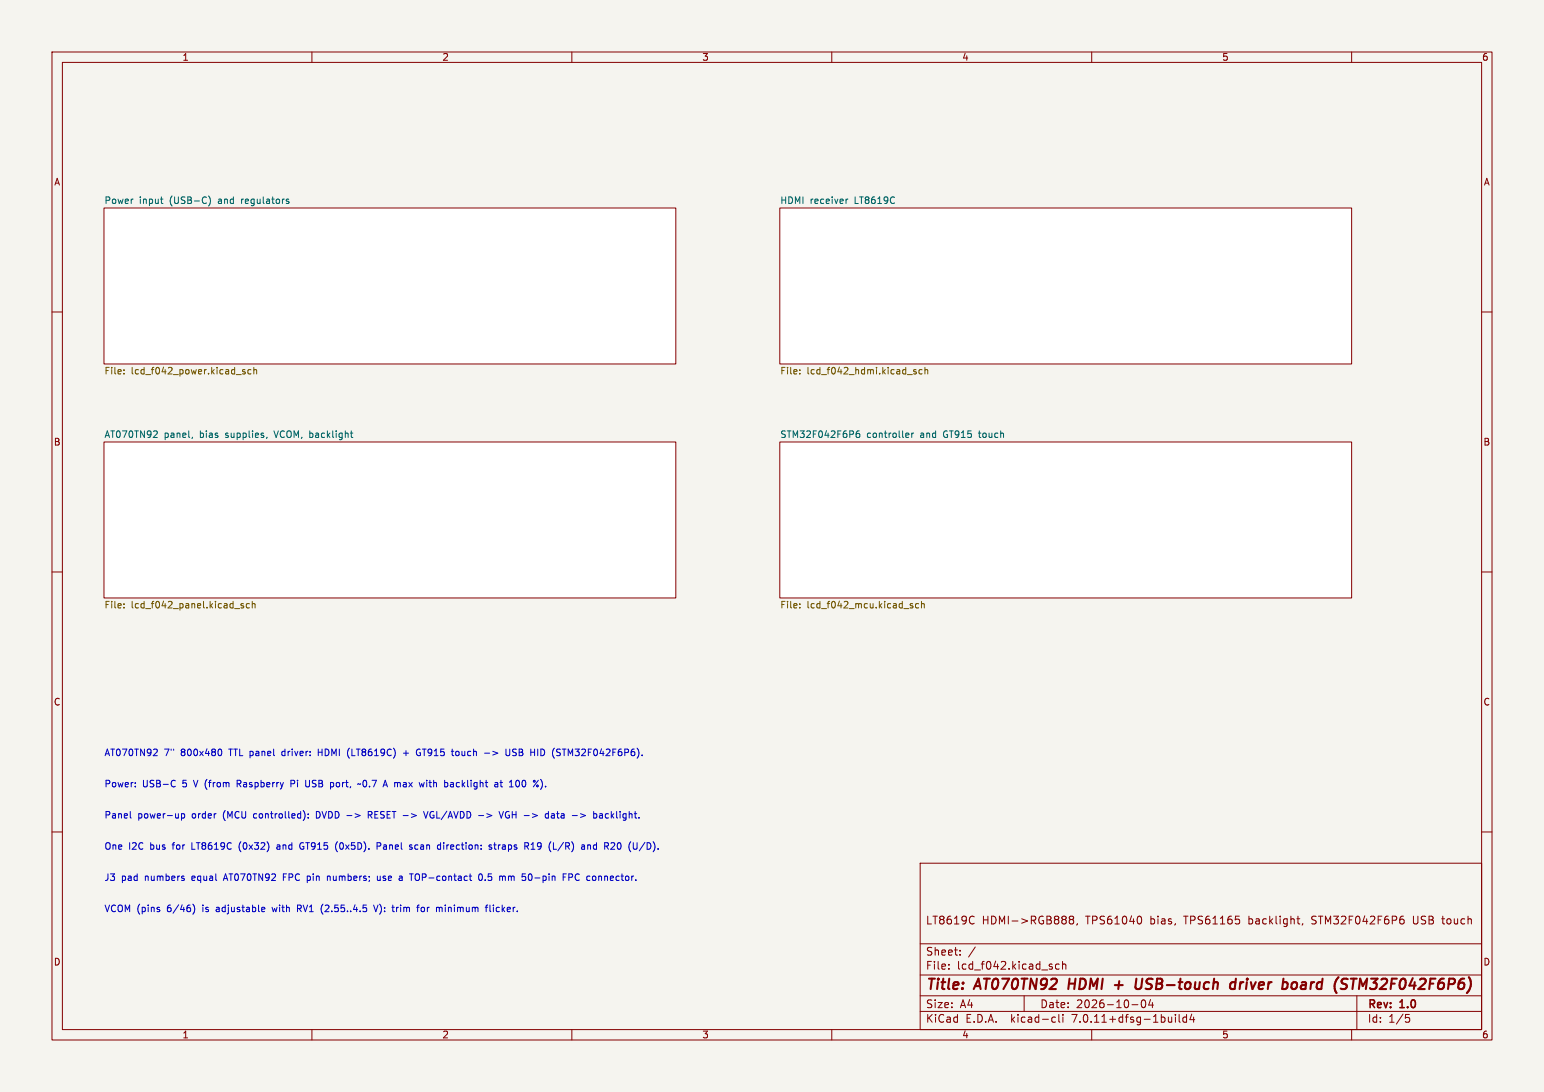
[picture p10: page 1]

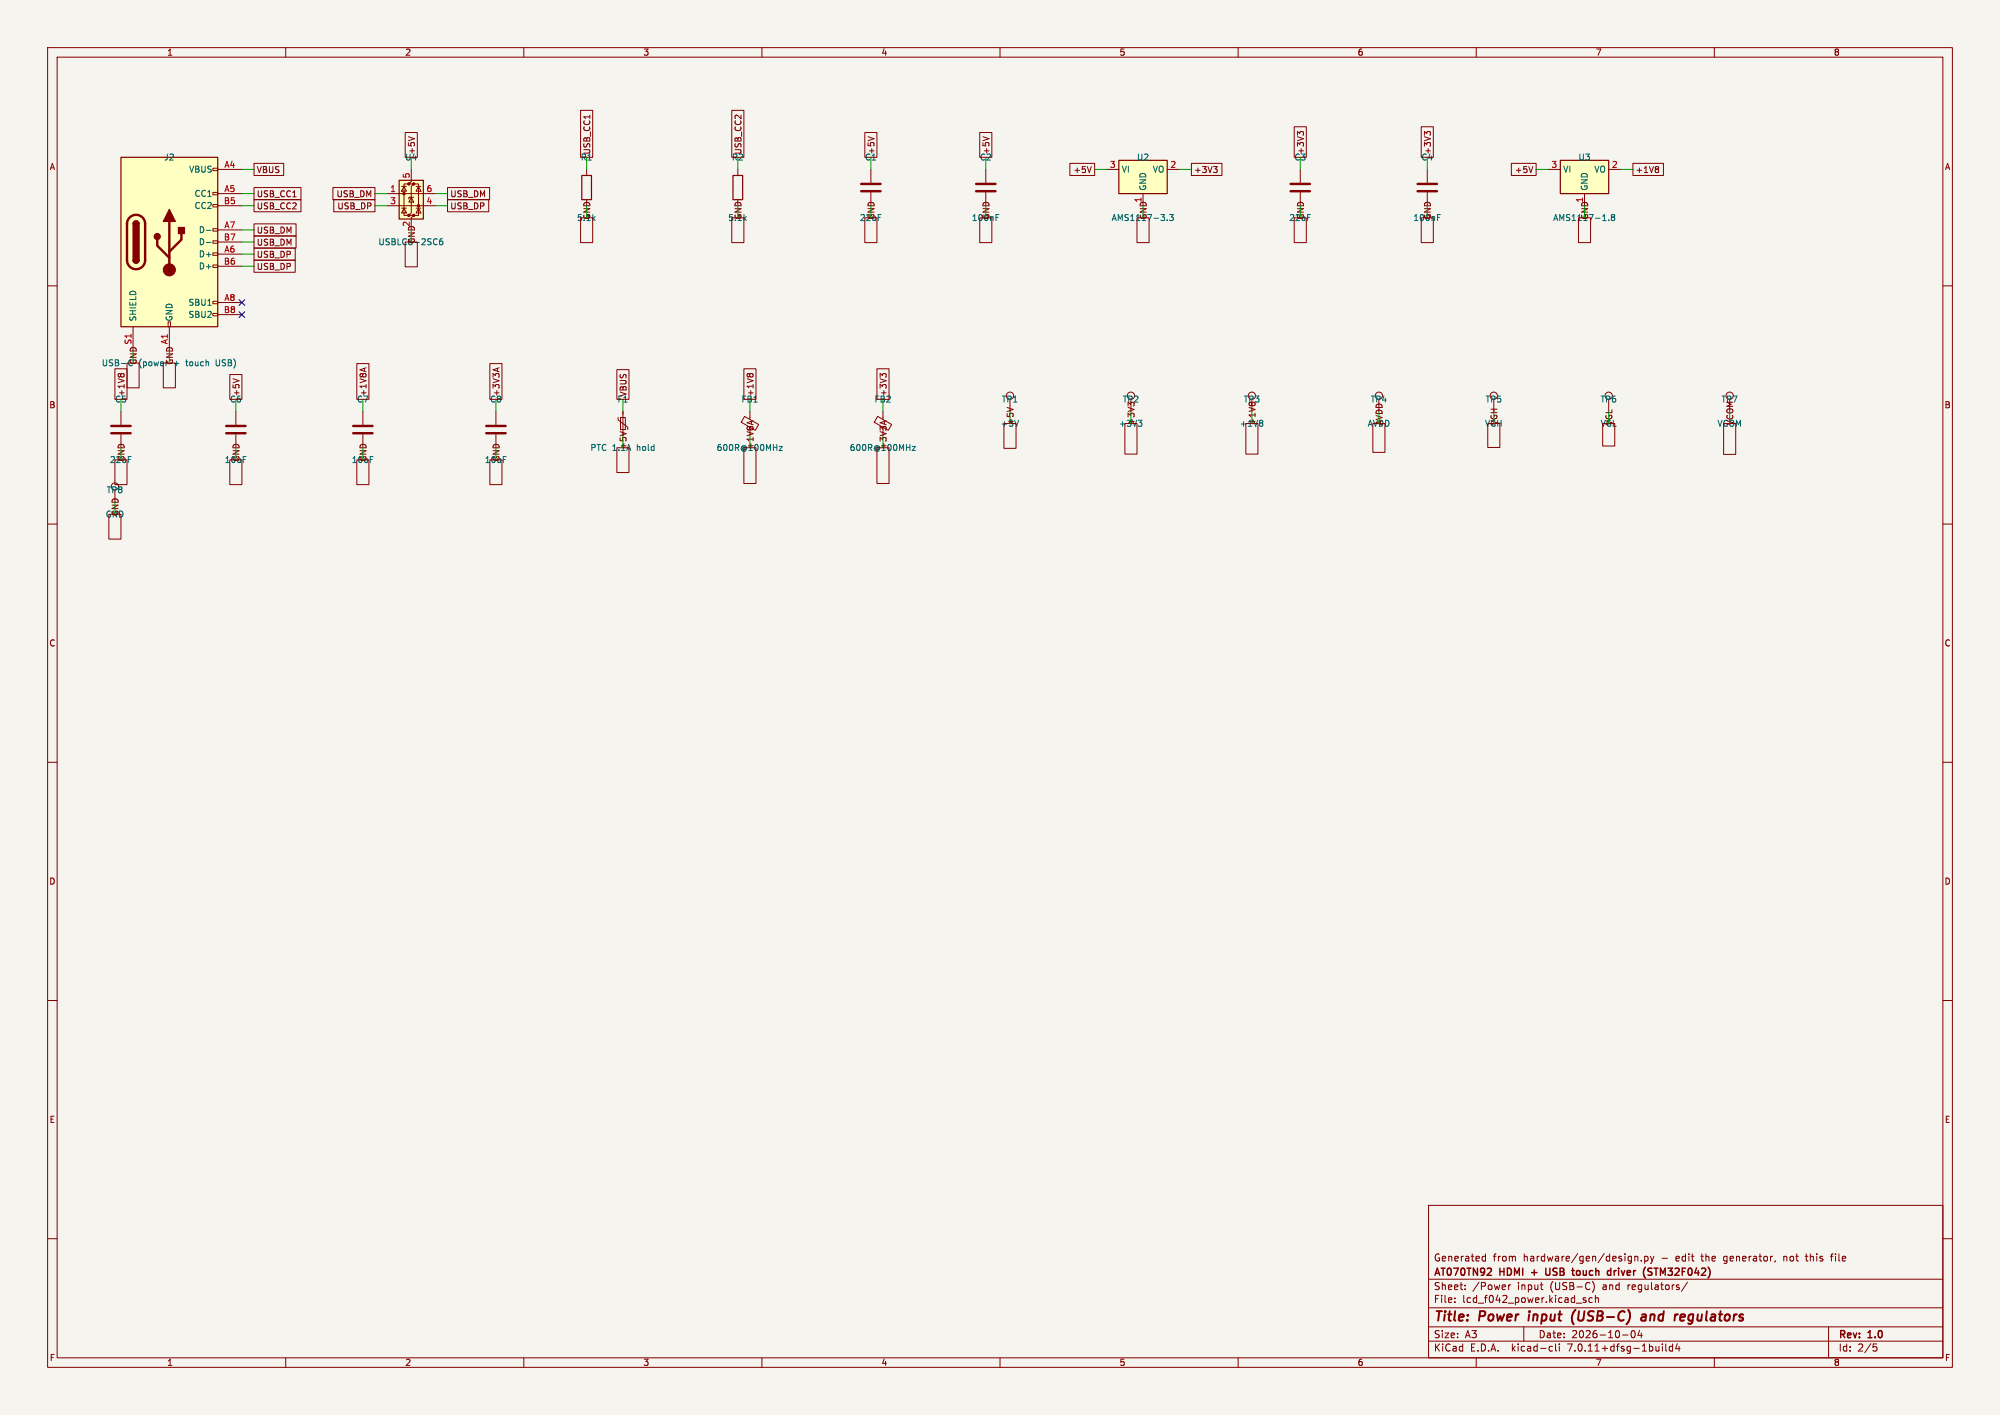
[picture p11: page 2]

1 VO 2 VI 3 U3 GND AMS1117-1.8 +1V8 VCOM GND VGH +3V3 +3V3A +1V8 USB_DM +5V USB_DP VGL +3V3A GND +3V3 +3V3 GND +3V3 +3V3 +5V +1V8 GND +5V +5V +1V8A GND

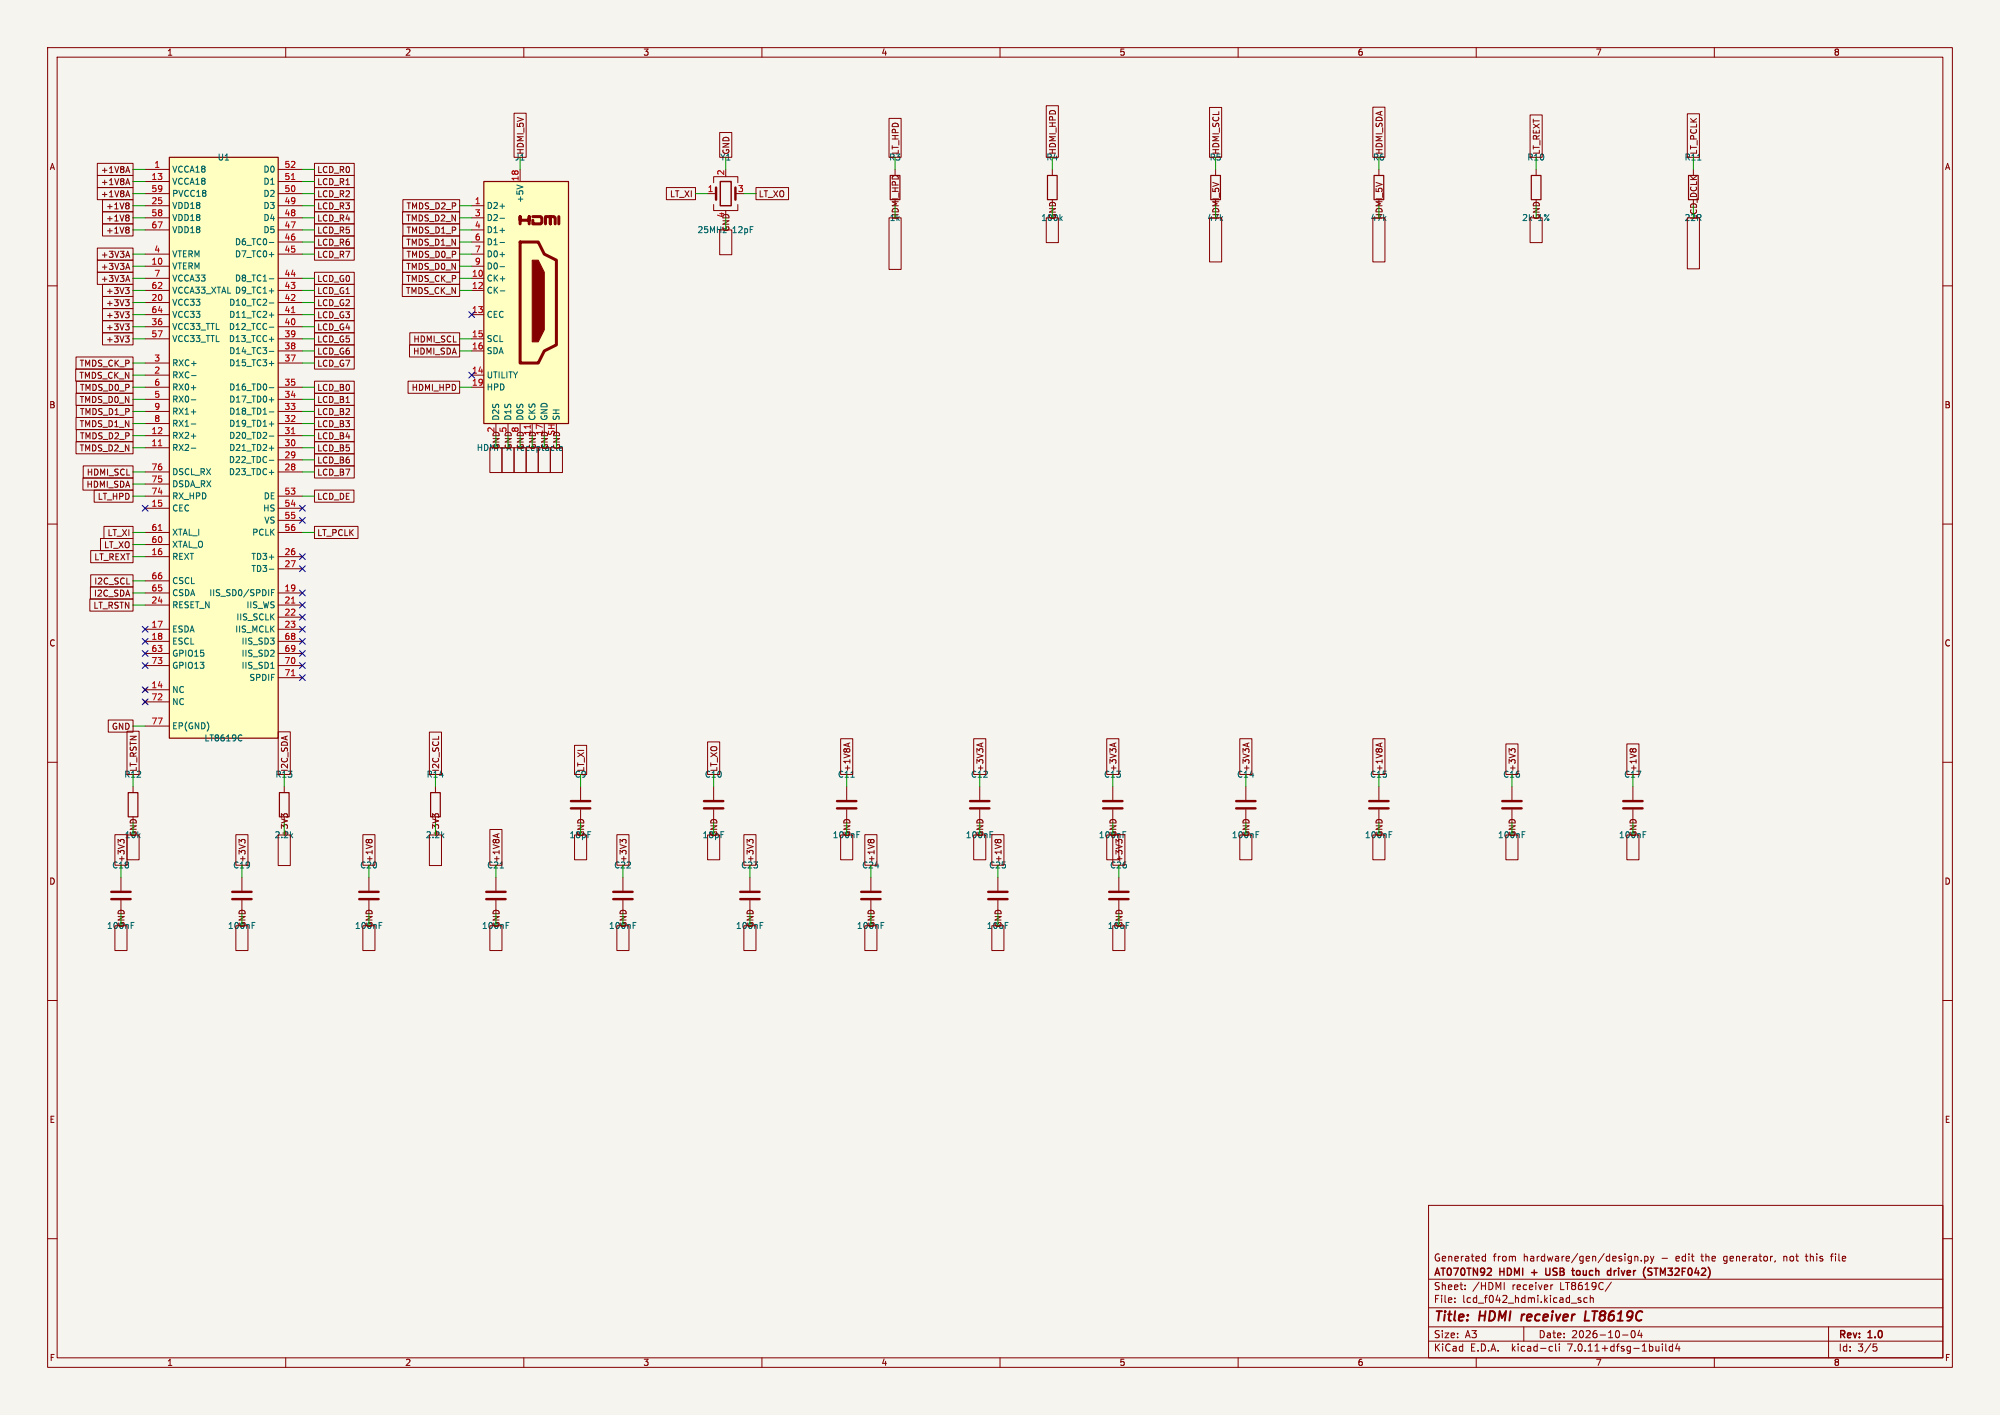
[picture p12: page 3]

Id: 3/5 Title: HDMI receiver LT8619C

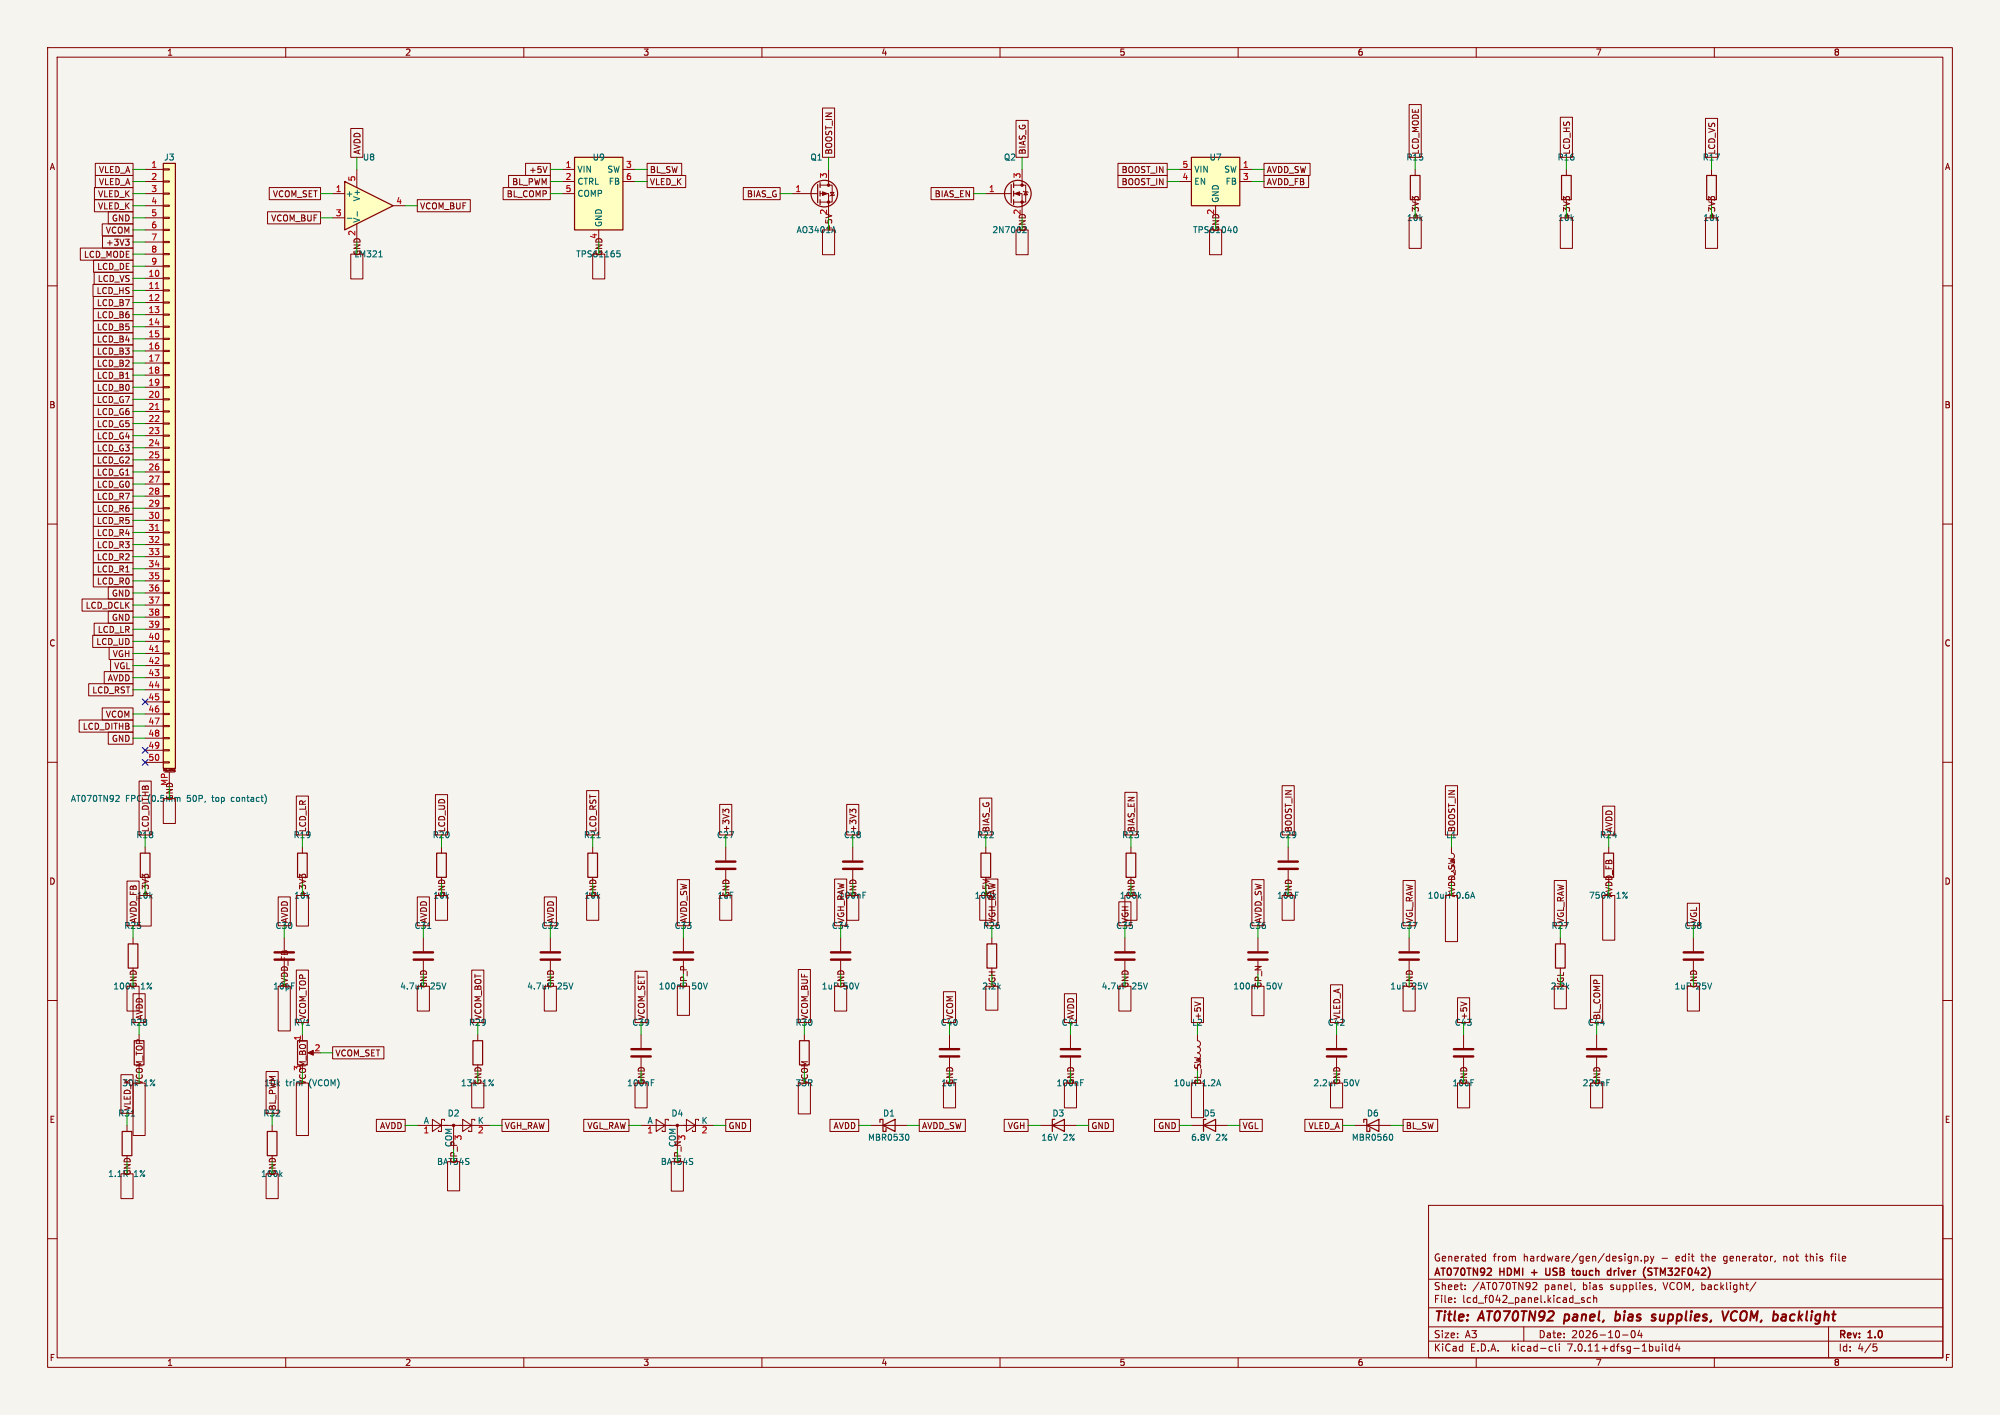
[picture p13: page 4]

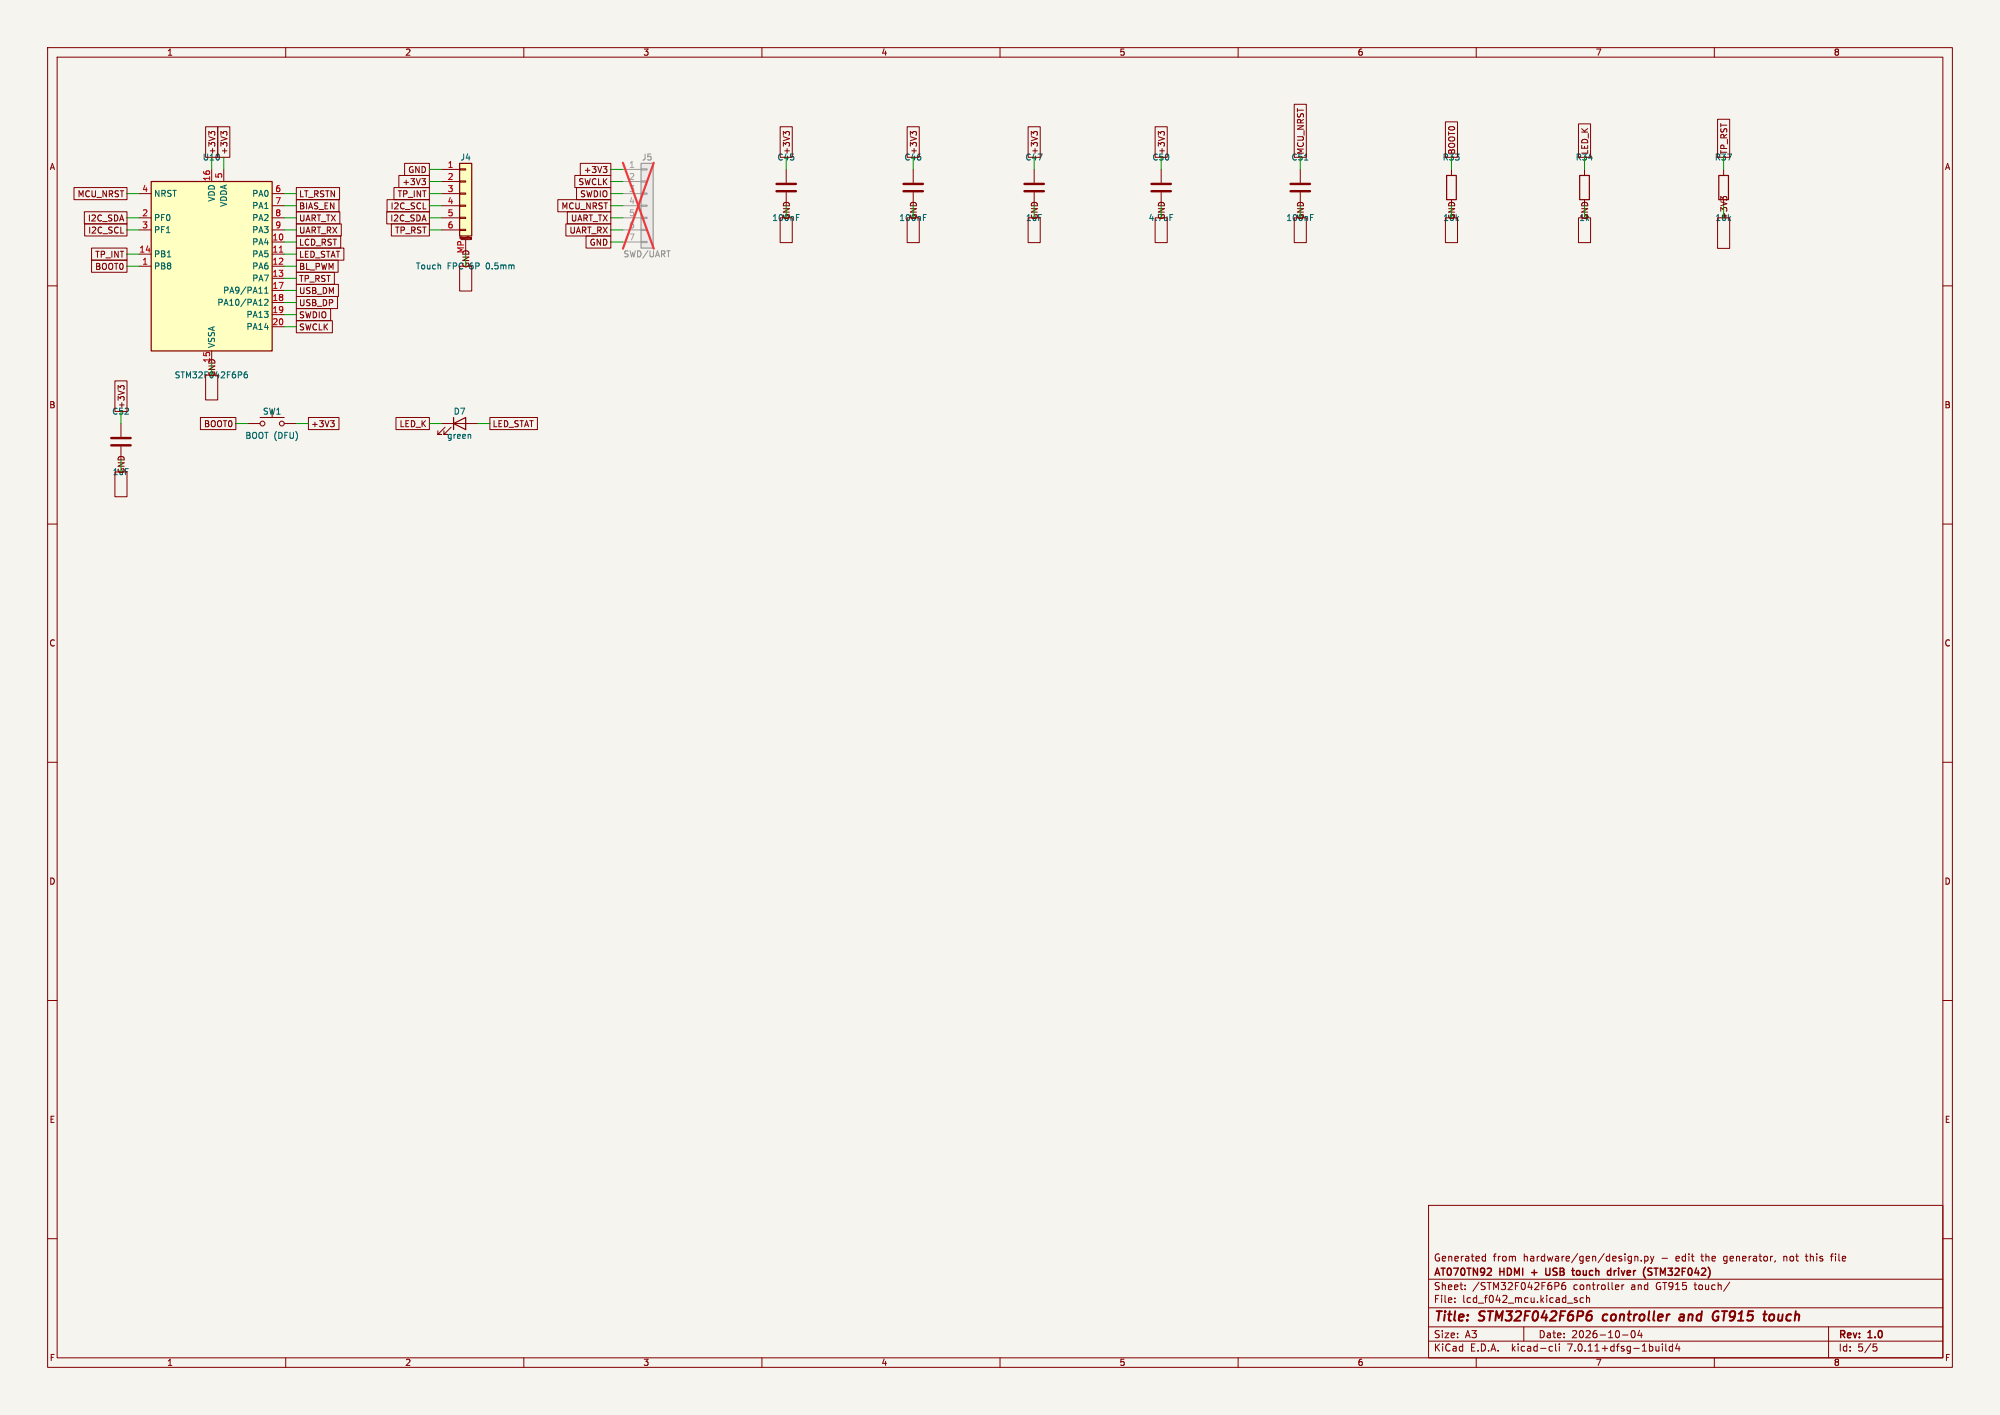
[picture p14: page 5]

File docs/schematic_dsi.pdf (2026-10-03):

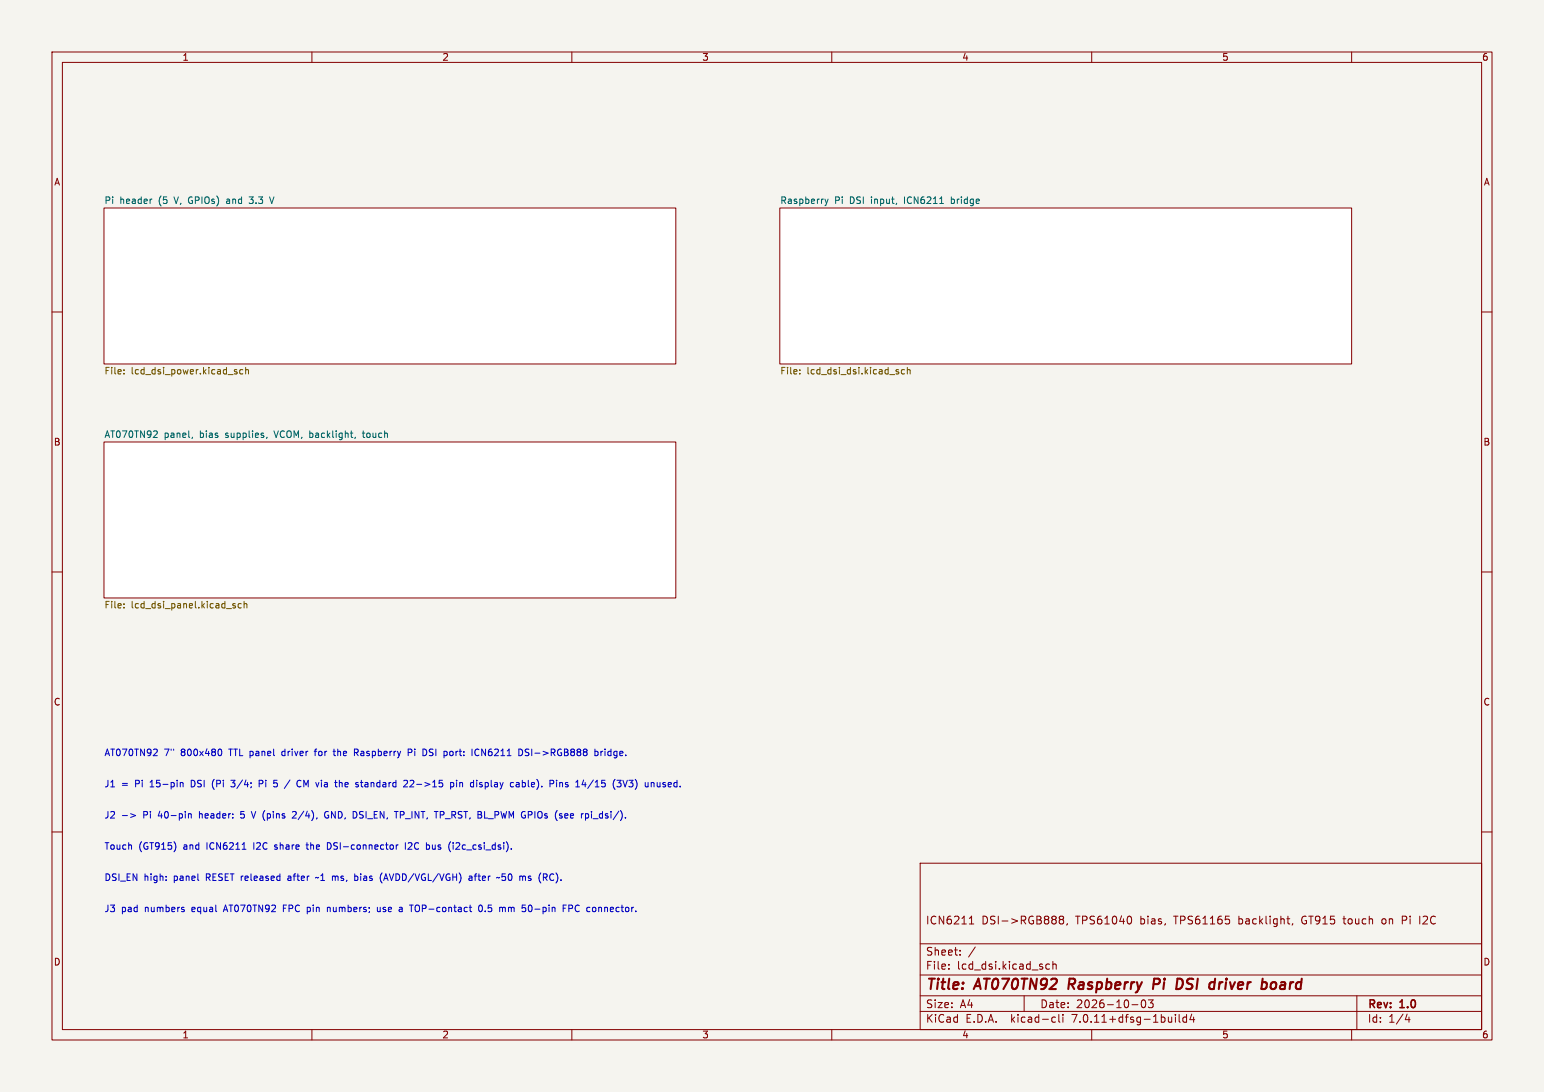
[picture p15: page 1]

Pi header (5 V, GPIOs) and 3.3 V

File: lcd_dsi.kicad_sch Sheet: /
Id: 1/4 Title: AT070TN92 Raspberry Pi DSI driver board

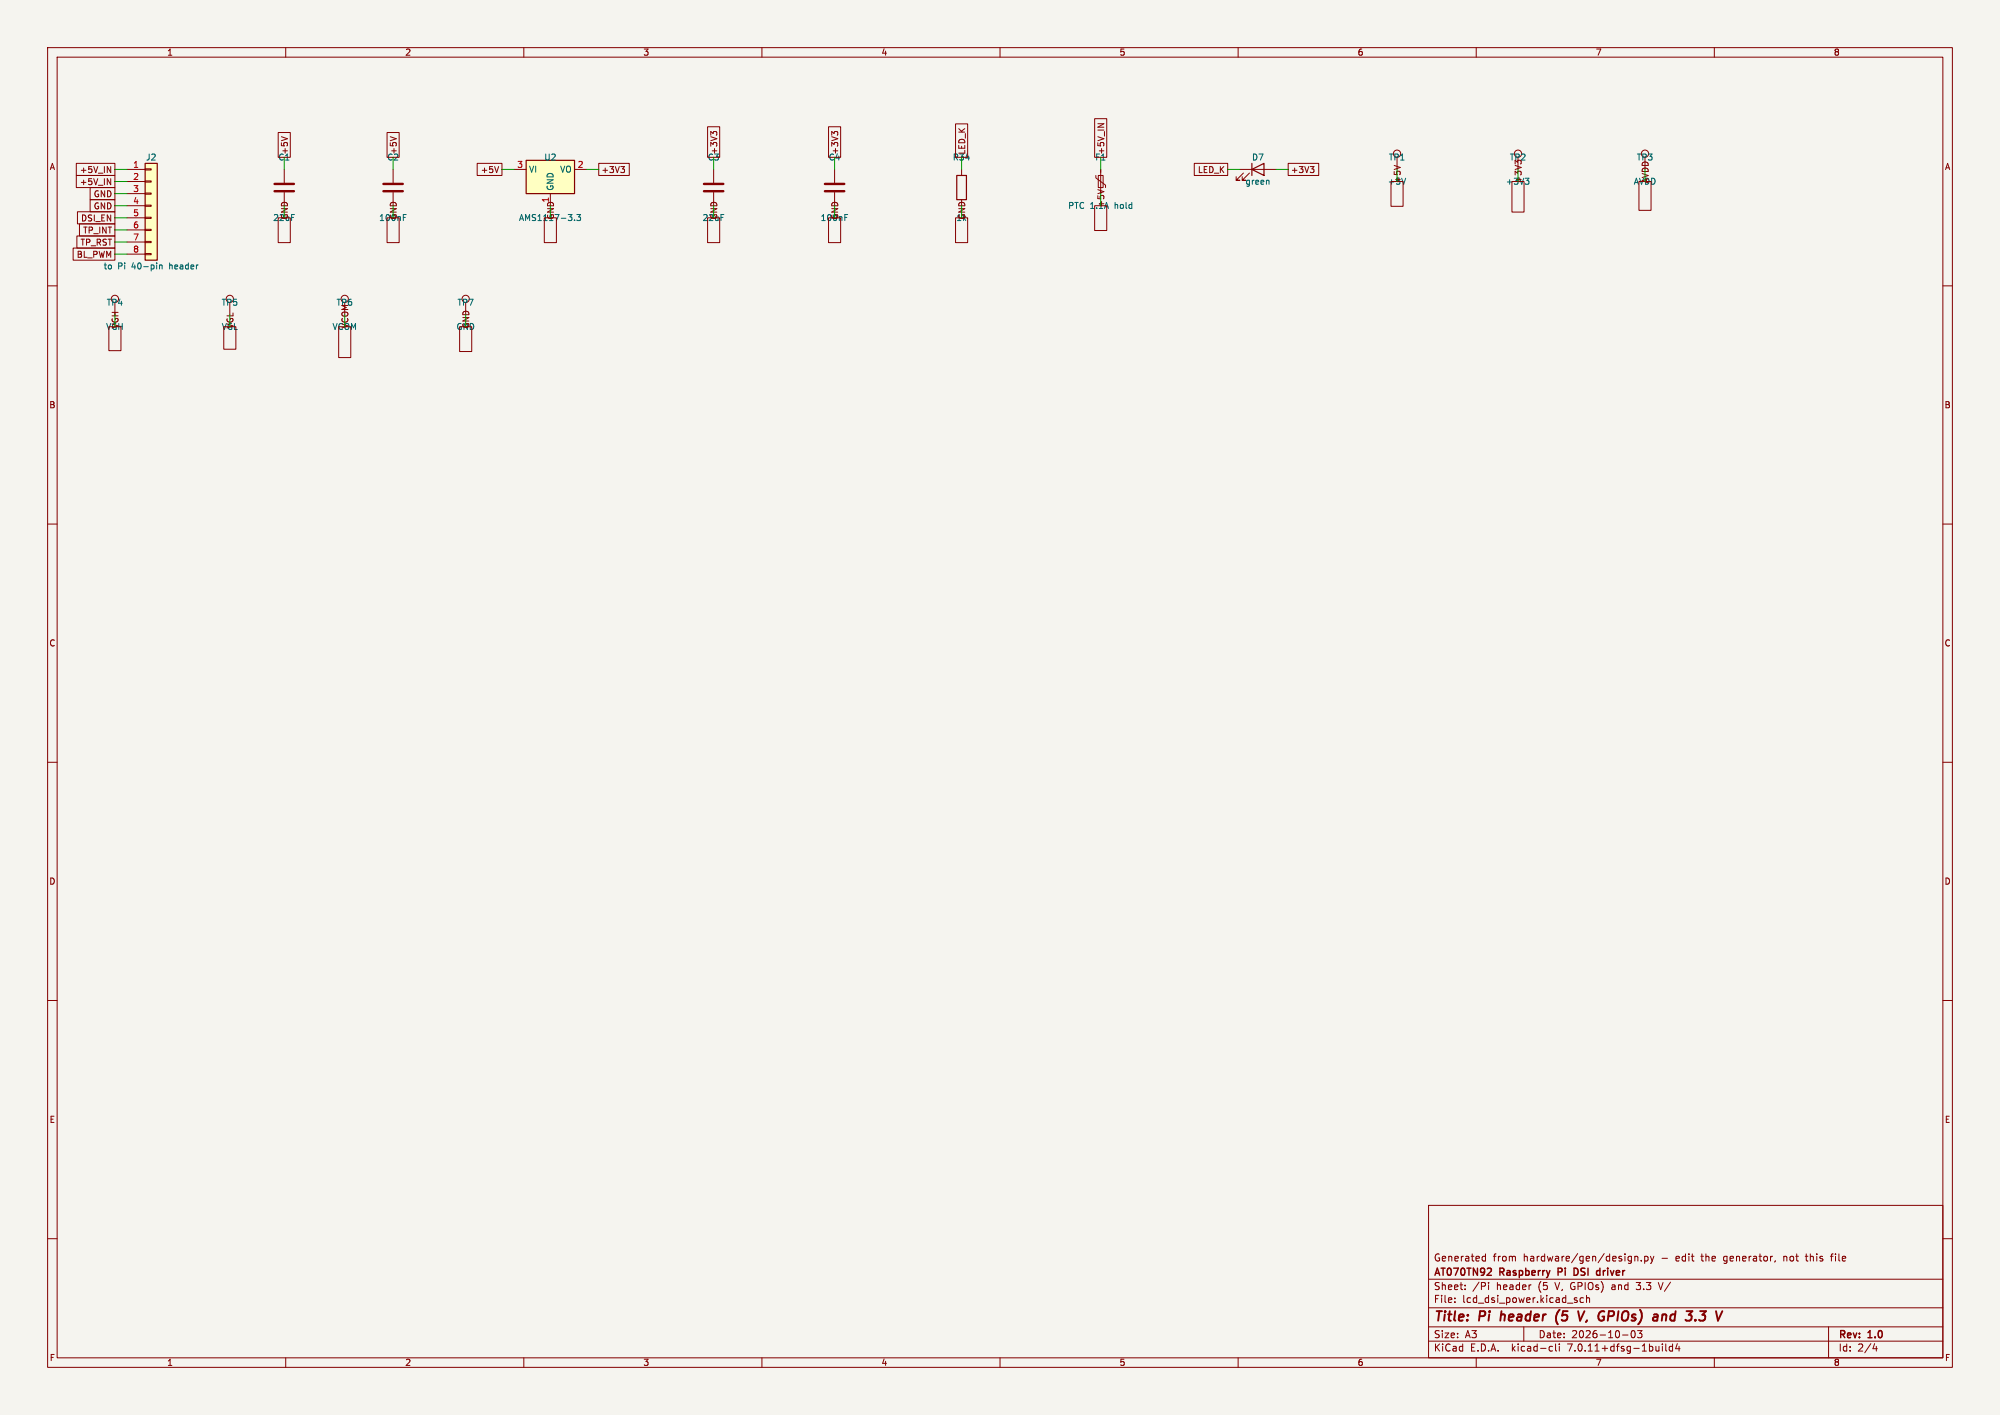
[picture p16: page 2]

Id: 2/4 Title: Pi header (5 V, GPIOs) and 3.3 V

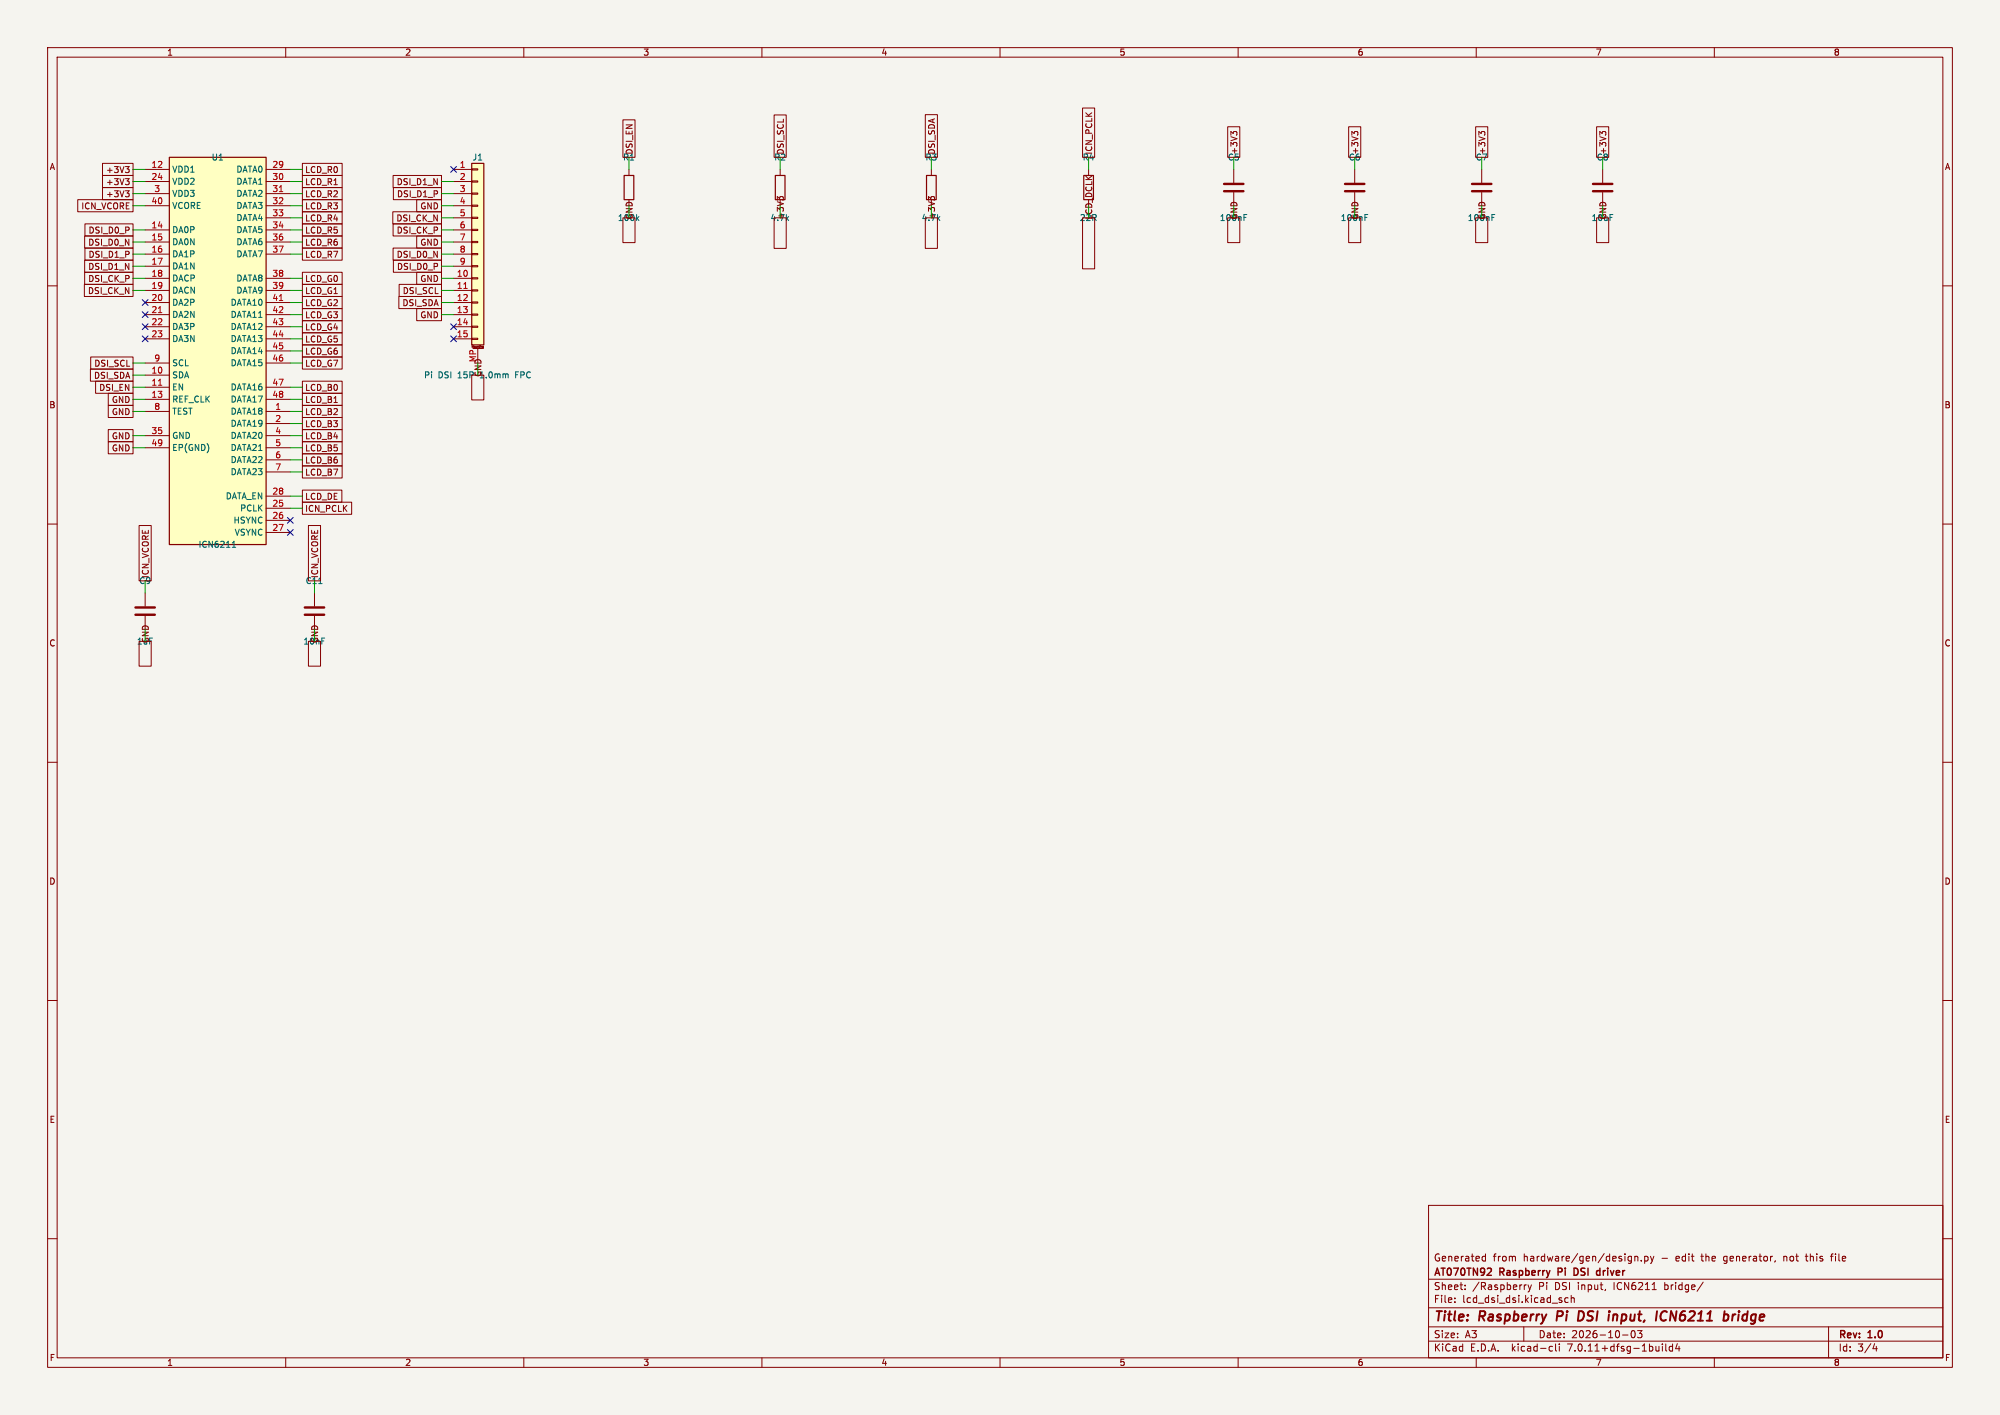
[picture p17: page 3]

+3V3 GND GND GND GND
+3V3 +3V3 DSI_SDA DSI_SCL

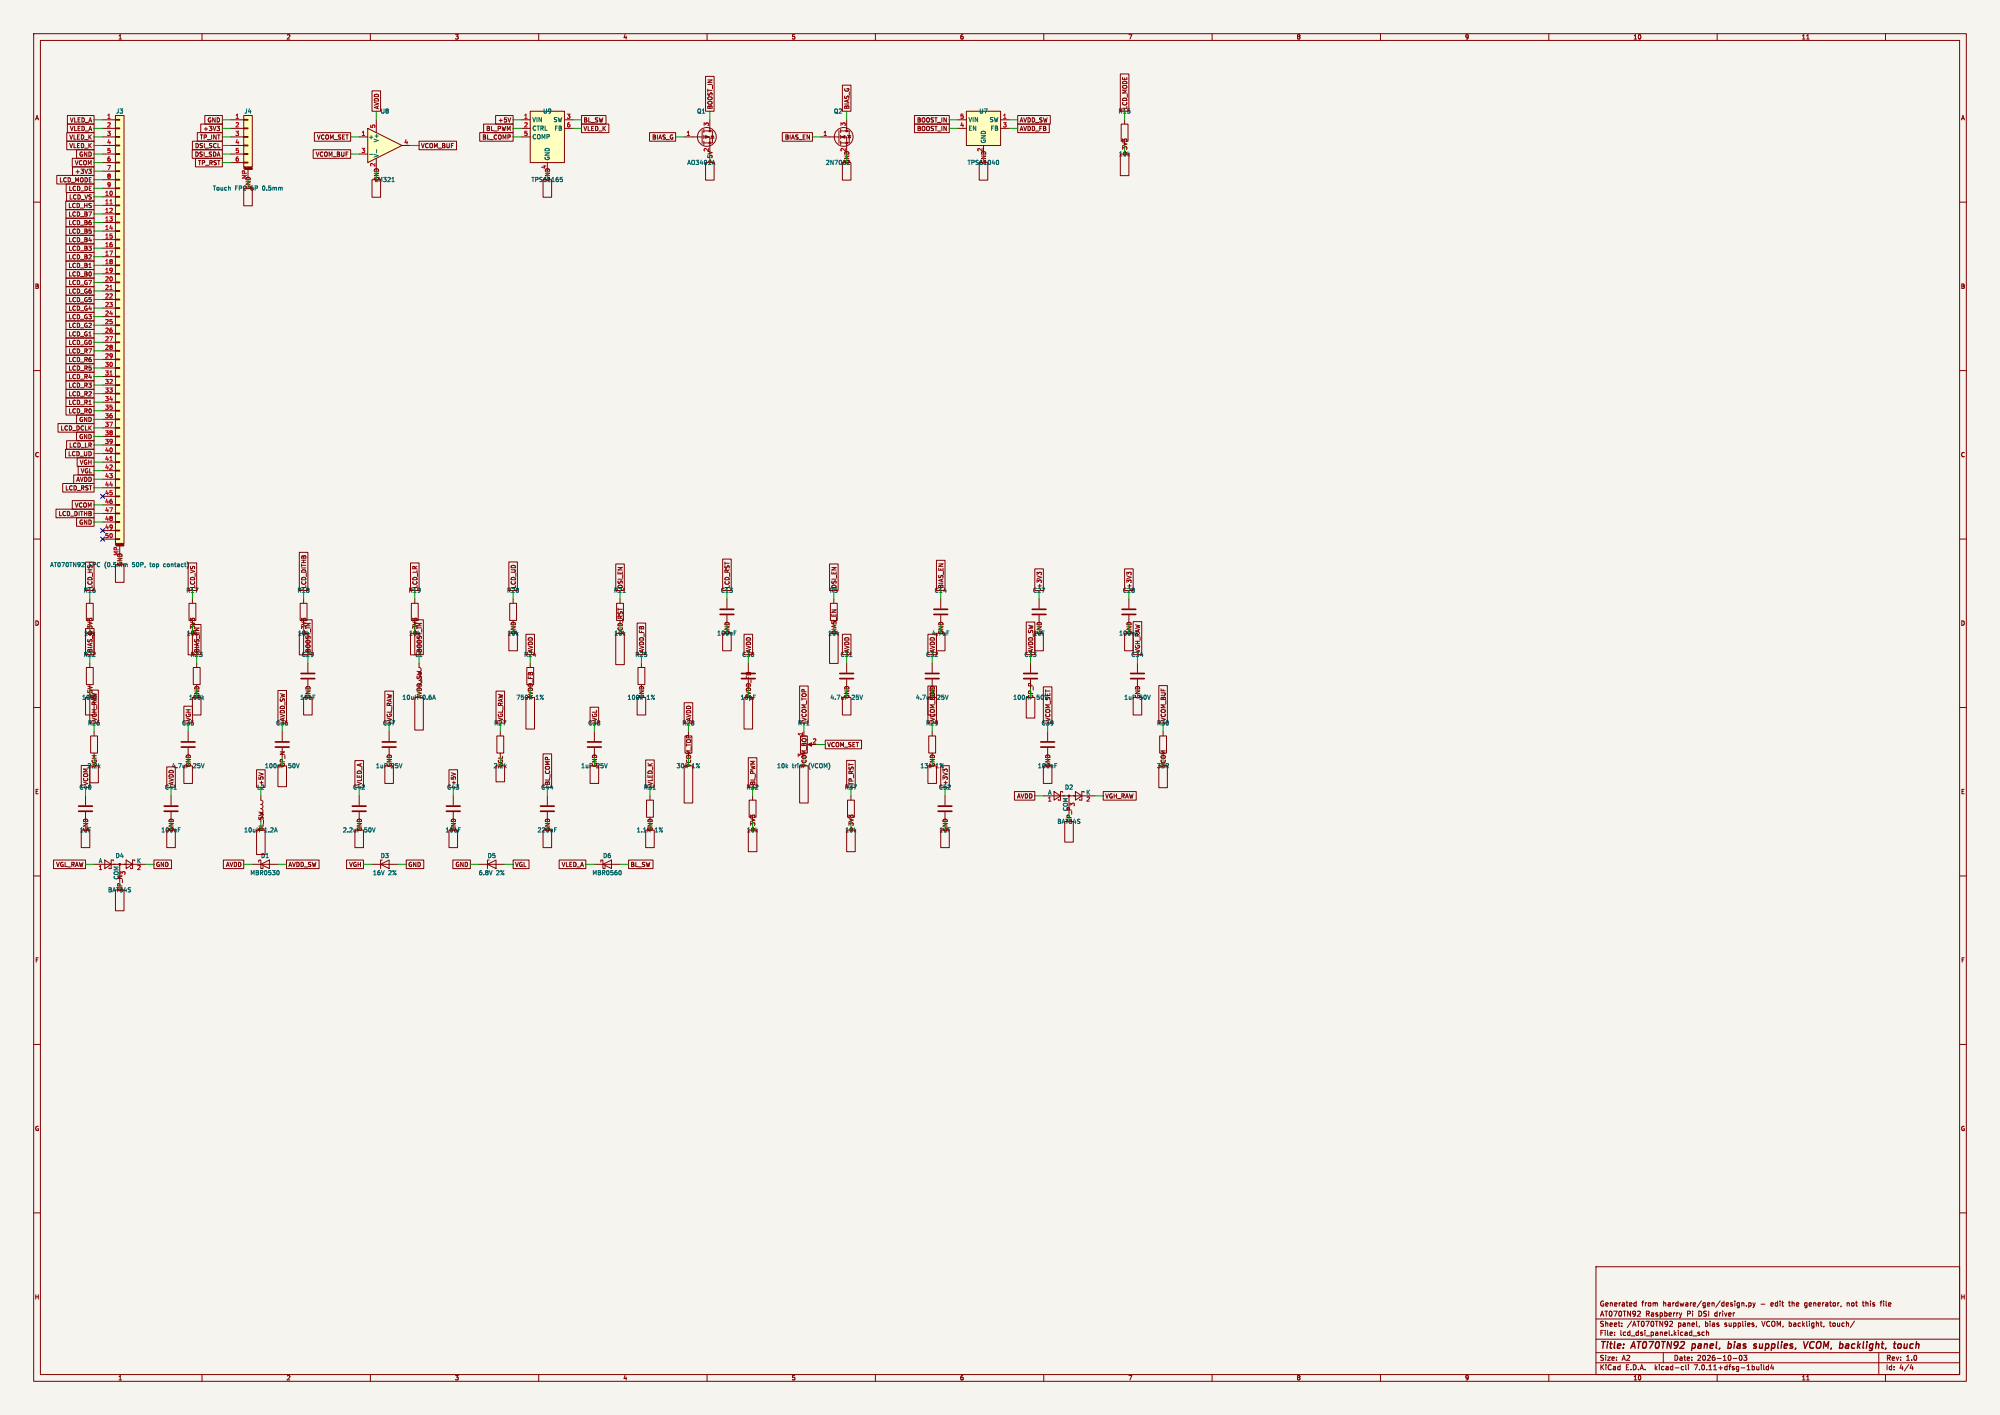
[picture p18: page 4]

4 COMP 5 FB 6 U9 TPS61165 SW 1 GND

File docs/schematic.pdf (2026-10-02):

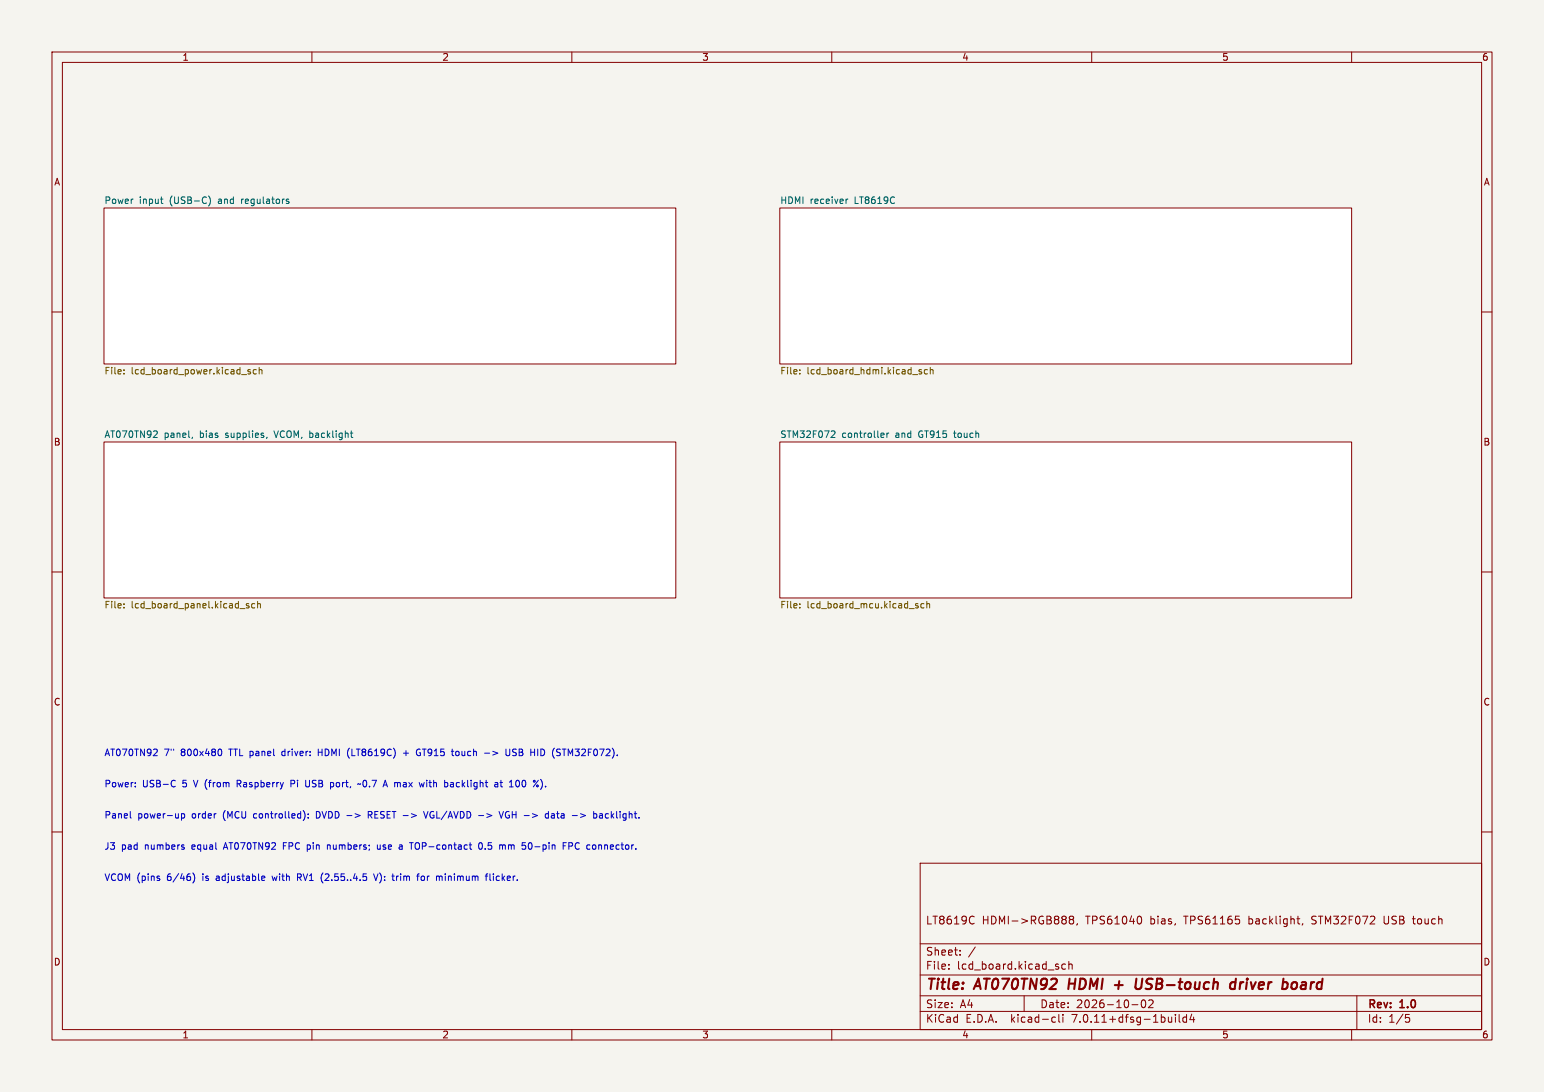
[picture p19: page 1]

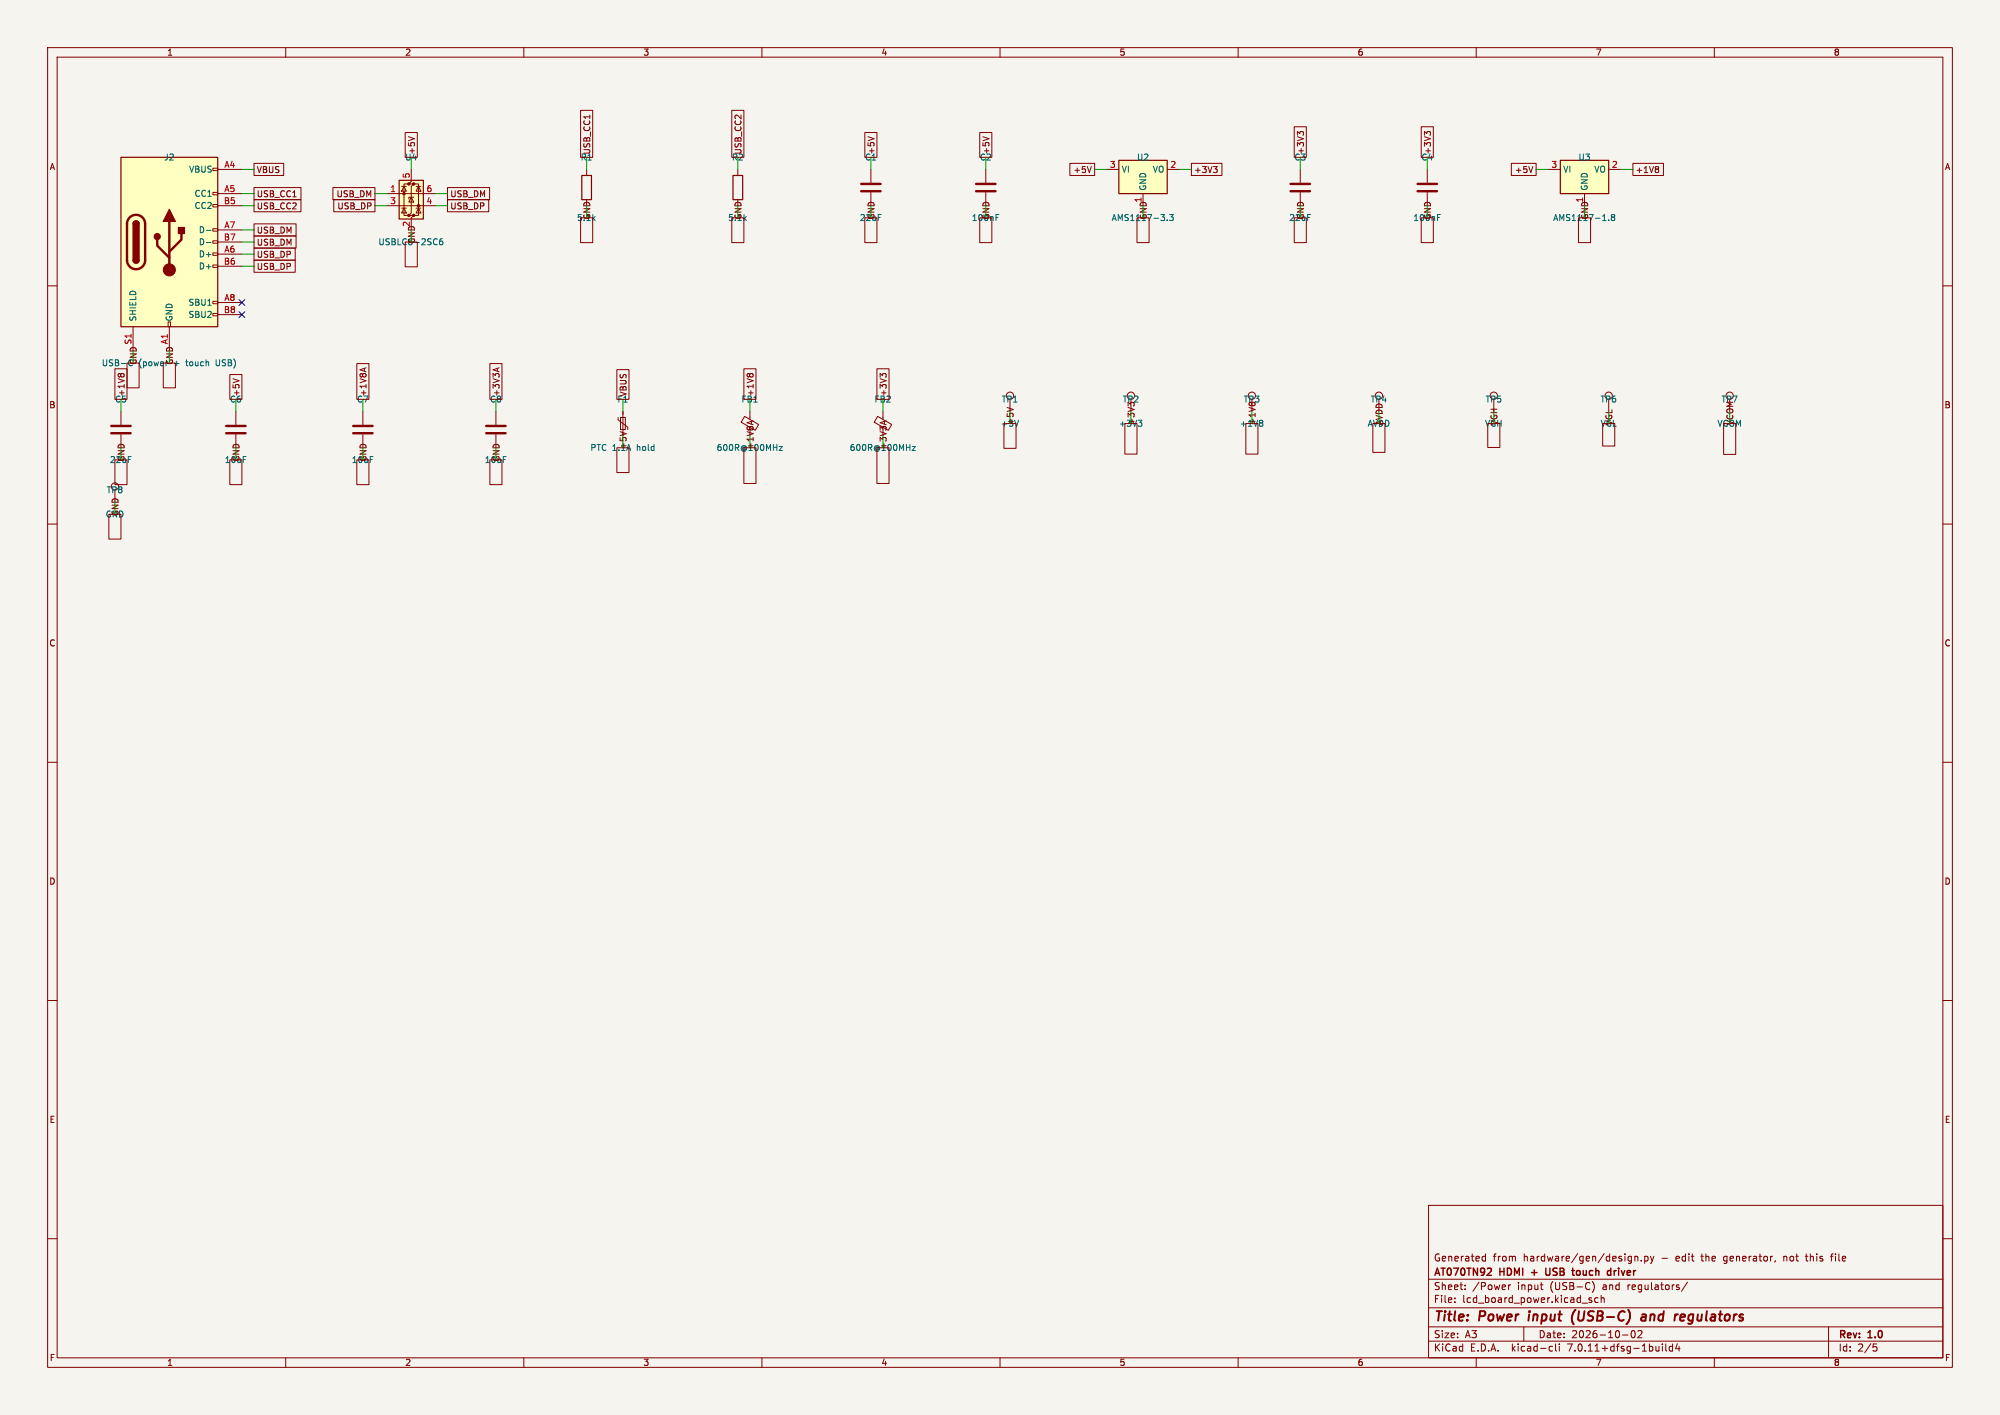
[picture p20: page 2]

1 VO 2 VI 3 U3 GND AMS1117-1.8 +1V8 VCOM GND VGH +3V3 +3V3A +1V8 USB_DM +5V USB_DP VGL +3V3A GND +3V3 +3V3 GND +3V3 +3V3 +5V +1V8 GND +5V +5V +1V8A GND

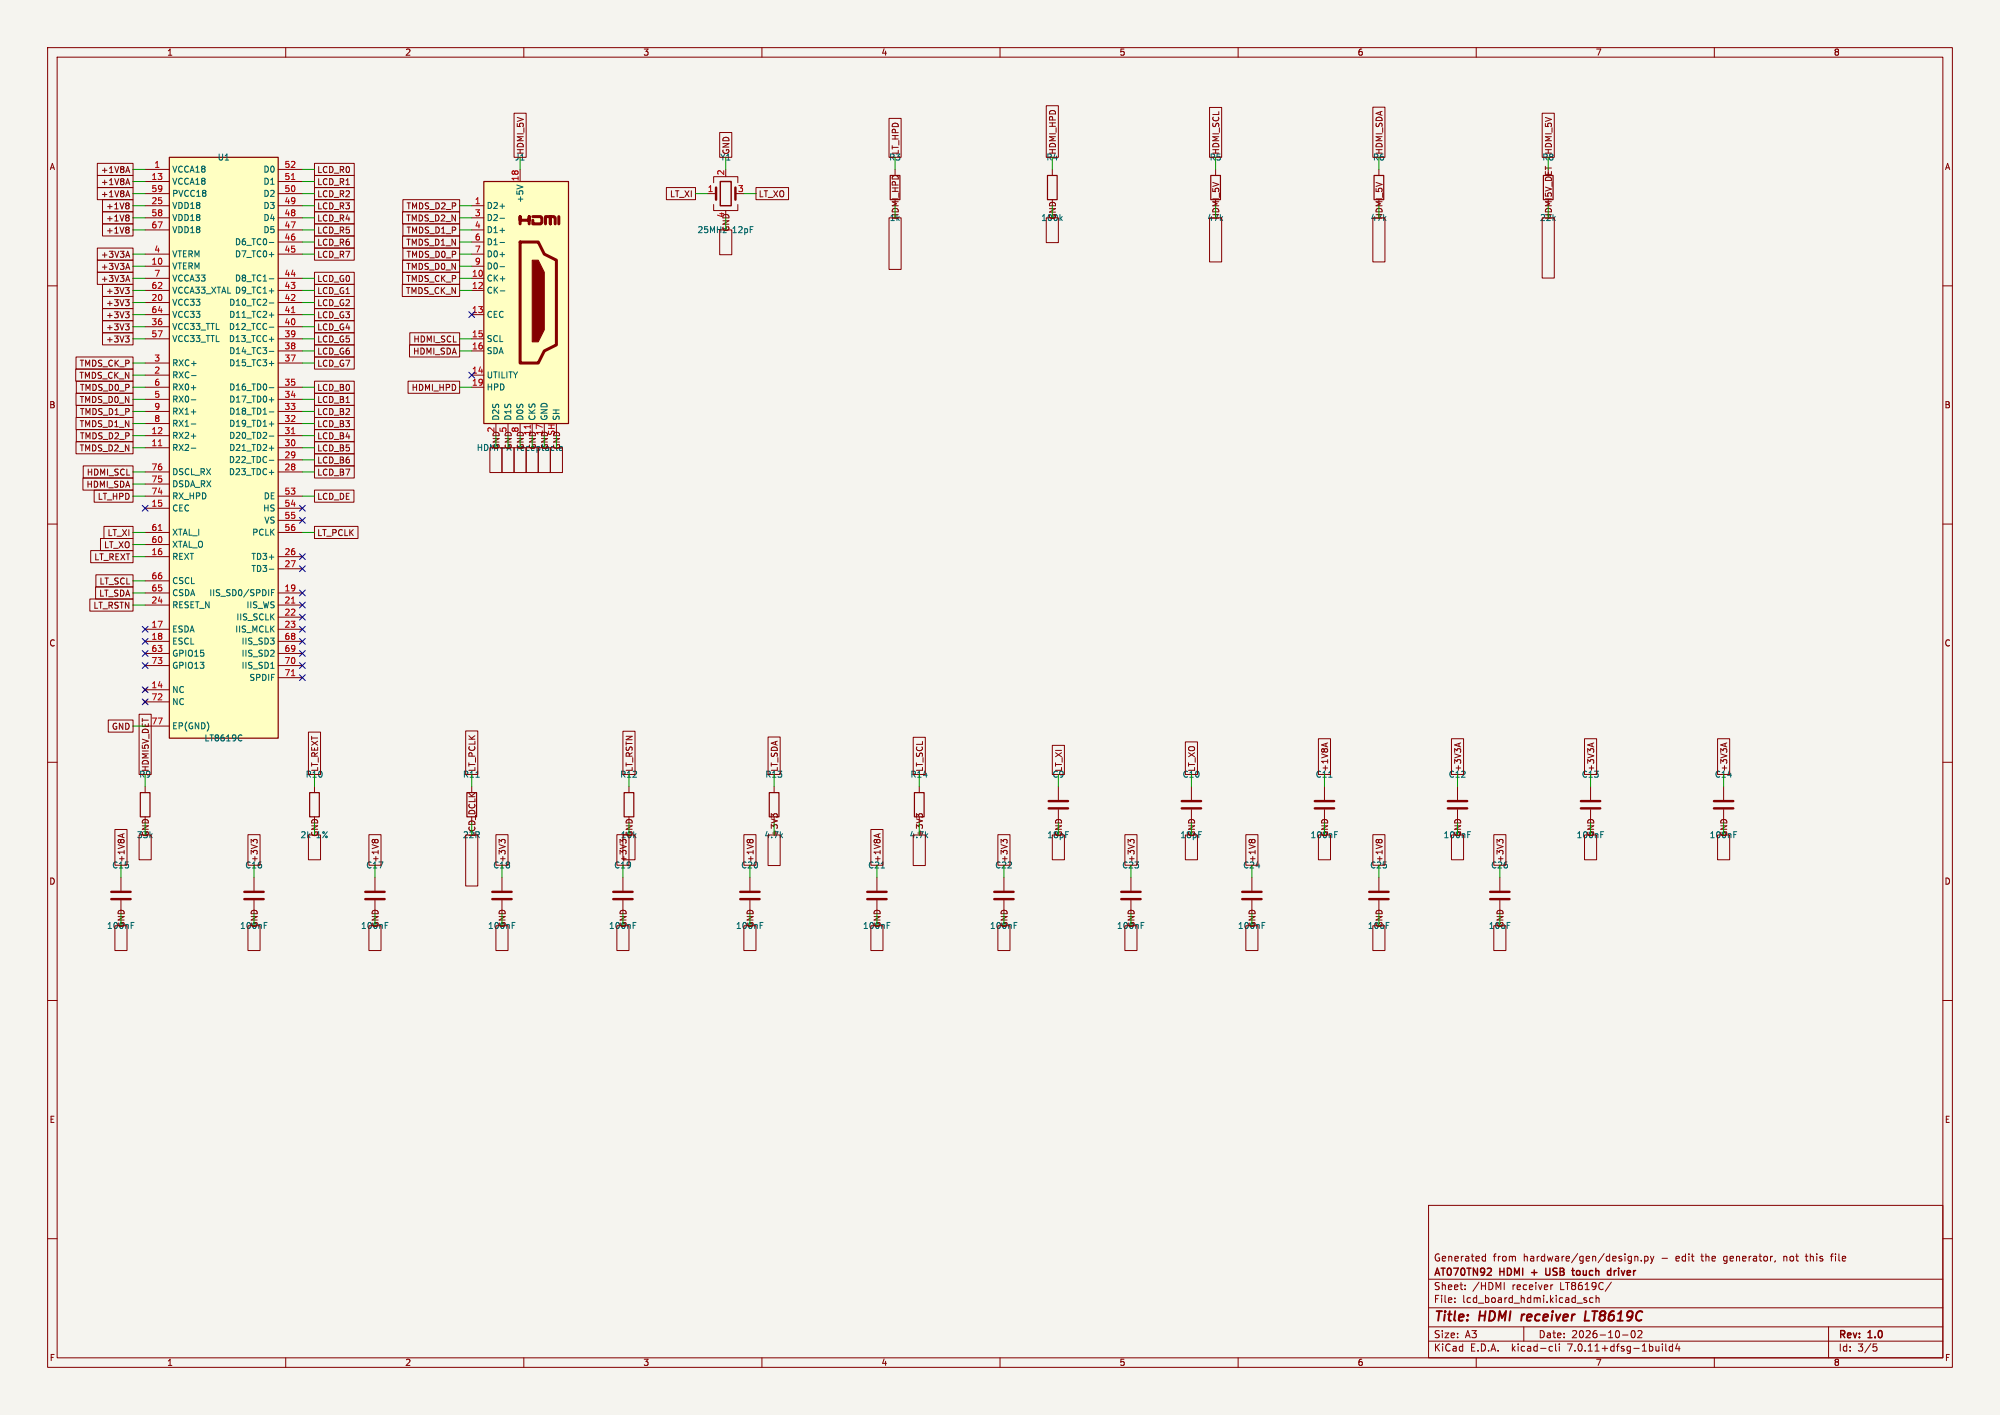
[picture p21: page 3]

Id: 3/5 Title: HDMI receiver LT8619C



1 PA0 10 PA1 11 PA2 12 PA3 13 PA4 14 PA5 15 PA6 16 PA7 17 PB0 18 PB1 19 PC13 2 PB2 20 PB10 21 PB11 22 VSS 23 VDD 24 PB12 25 PB13 26 PB14 27 PB15 28 PA8 29 PC14 3 PA9 30 PA10 31 PA11 32 PA12 33 PA13 34 VDDIO2 36 PA14 37 PA15 38 PB3 39 PC15 4 PB4 40 PB5 41 PB6 42 PB7 43 BOOT0 44 PB8 45 PB9 46 VDD 48 PF0 5 PF1 6 NRST 7 VSSA

Id: 5/5 Title: STM32F072 controller and GT915 touch

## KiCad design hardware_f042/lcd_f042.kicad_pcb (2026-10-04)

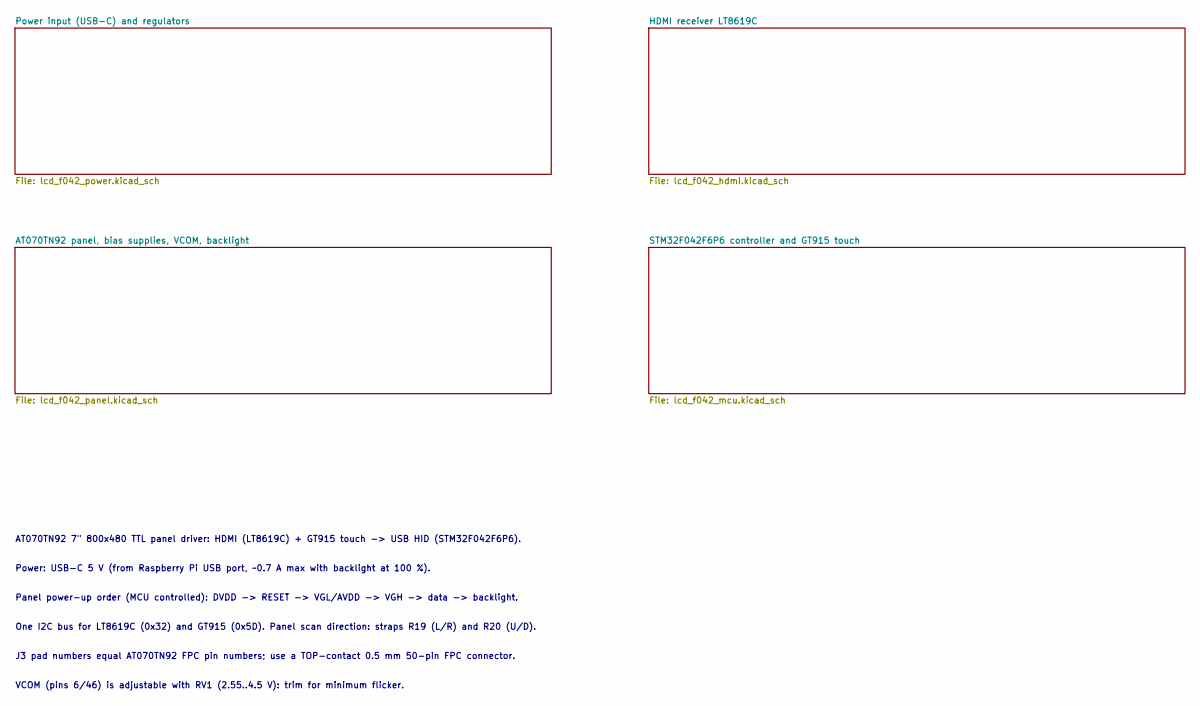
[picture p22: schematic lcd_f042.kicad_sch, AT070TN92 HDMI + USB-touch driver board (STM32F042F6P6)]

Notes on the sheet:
AT070TN92 7" 800x480 TTL panel driver: HDMI (LT8619C) + GT915 touch -> USB HID (STM32F042F6P6).
Power: USB-C 5 V (from Raspberry Pi USB port, ~0.7 A max with backlight at 100 %).
Panel power-up order (MCU controlled): DVDD -> RESET -> VGL/AVDD -> VGH -> data -> backlight.
One I2C bus for LT8619C (0x32) and GT915 (0x5D). Panel scan direction: straps R19 (L/R) and R20 (U/D).
J3 pad numbers equal AT070TN92 FPC pin numbers; use a TOP-contact 0.5 mm 50-pin FPC connector.
VCOM (pins 6/46) is adjustable with RV1 (2.55..4.5 V): trim for minimum flicker.

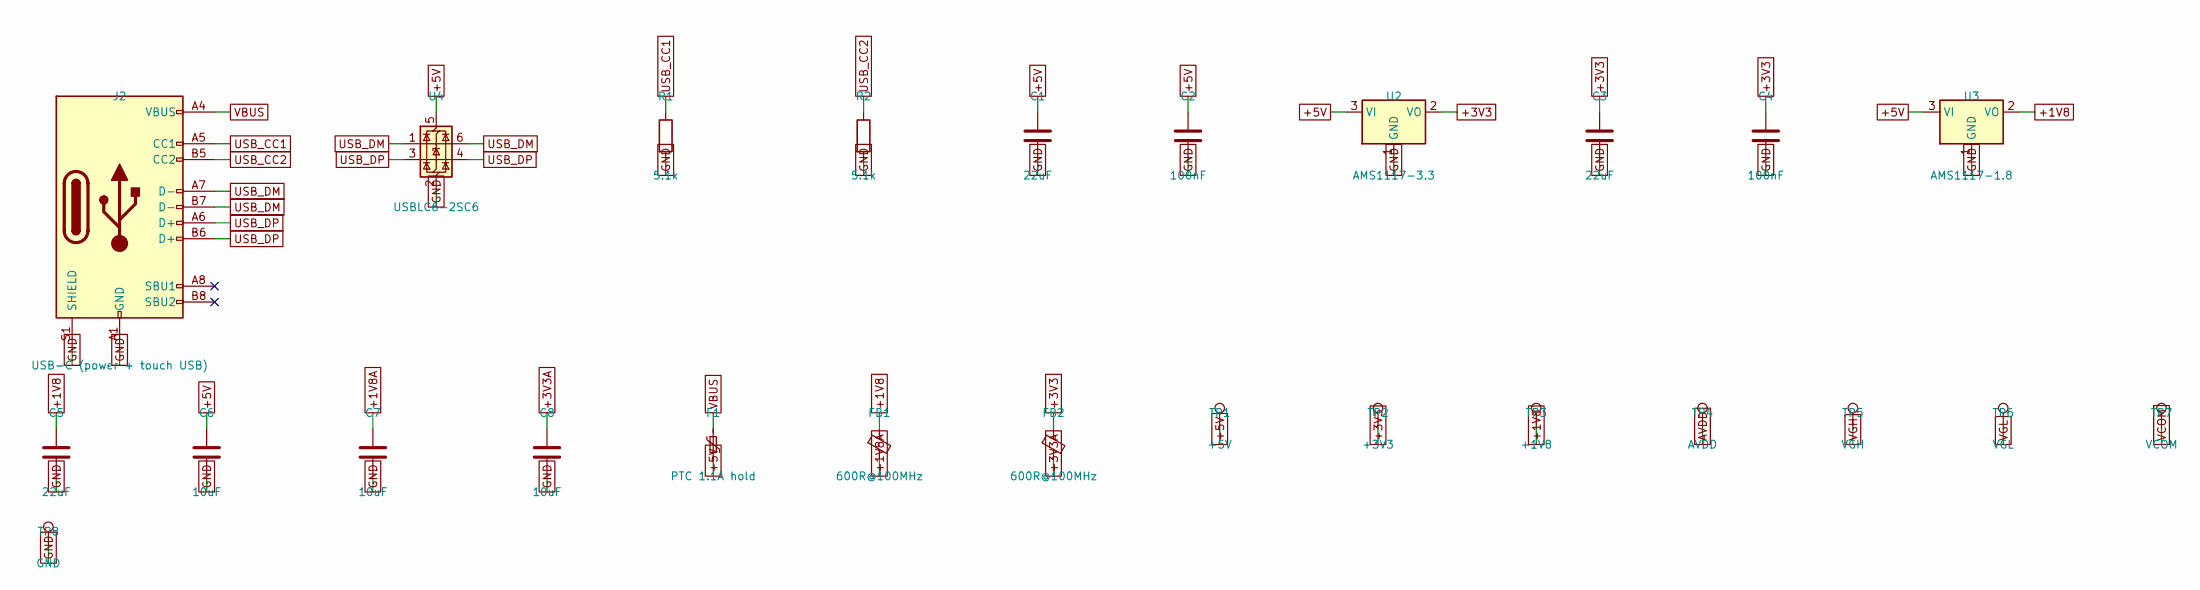
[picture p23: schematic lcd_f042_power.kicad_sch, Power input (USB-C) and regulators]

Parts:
C1, C3, C5: 22uF; C_0805_2012Metric
C2, C4: 100nF; C_0603_1608Metric; LCSC C14663
C6, C7, C8: 10uF; C_0603_1608Metric; LCSC C19702
F1: PTC 1.1A hold; Fuse_1206_3216Metric; MPN 1206L110/16 (or BSMD1206-110)
FB1, FB2: 600R@100MHz; L_0603_1608Metric; MPN BLM18PG601SN1D
J2: USB-C (power + touch USB); USB_C_Receptacle_HRO_TYPE-C-31-M-12; MPN HRO TYPE-C-31-M-12; LCSC C165948
R1, R2: 5.1k; R_0603_1608Metric; LCSC C23186
TP1: +5V; TestPoint_Pad_D1.0mm
TP2: +3V3; TestPoint_Pad_D1.0mm
TP3: +1V8; TestPoint_Pad_D1.0mm
TP4: AVDD; TestPoint_Pad_D1.0mm
TP5: VGH; TestPoint_Pad_D1.0mm
TP6: VGL; TestPoint_Pad_D1.0mm
TP7: VCOM; TestPoint_Pad_D1.0mm
TP8: GND; TestPoint_Pad_D1.0mm
U2: AMS1117-3.3; SOT-223-3_TabPin2; MPN AMS1117-3.3; LCSC C6186
U3: AMS1117-1.8; SOT-223-3_TabPin2; MPN AMS1117-1.8
U4: USBLC6-2SC6; SOT-23-6; MPN USBLC6-2SC6; LCSC C7519

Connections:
+1V8: C5.1, FB1.1, TP3.1, U3.2 (VO); also elsewhere on the board
+1V8A: C7.1, FB1.2; also elsewhere on the board
+3V3: C3.1, C4.1, FB2.1, TP2.1, U2.2 (VO); also elsewhere on the board
+3V3A: C8.1, FB2.2; also elsewhere on the board
+5V: C1.1, C2.1, C6.1, F1.2, TP1.1, U2.3 (VI), U3.3 (VI), U4.5 (VBUS); also elsewhere on the board
AVDD: TP4.1; also elsewhere on the board
GND: C1.2, C2.2, C3.2, C4.2, C5.2, C6.2, C7.2, C8.2, J2.A1 (GND), J2.A12 (GND), J2.B1 (GND), J2.B12 (GND), J2.S1 (SHIELD), R1.2, R2.2, TP8.1, U2.1 (GND), U3.1 (GND), U4.2 (GND); also elsewhere on the board
USB_CC1: J2.A5 (CC1), R1.1
USB_CC2: J2.B5 (CC2), R2.1
USB_DM: J2.A7 (D-), J2.B7 (D-), U4.1 (I/O1), U4.6 (I/O1); also elsewhere on the board
USB_DP: J2.A6 (D+), J2.B6 (D+), U4.3 (I/O2), U4.4 (I/O2); also elsewhere on the board
VBUS: F1.1, J2.A4 (VBUS), J2.A9 (VBUS), J2.B4 (VBUS), J2.B9 (VBUS)
VCOM: TP7.1; also elsewhere on the board
VGH: TP5.1; also elsewhere on the board
VGL: TP6.1; also elsewhere on the board

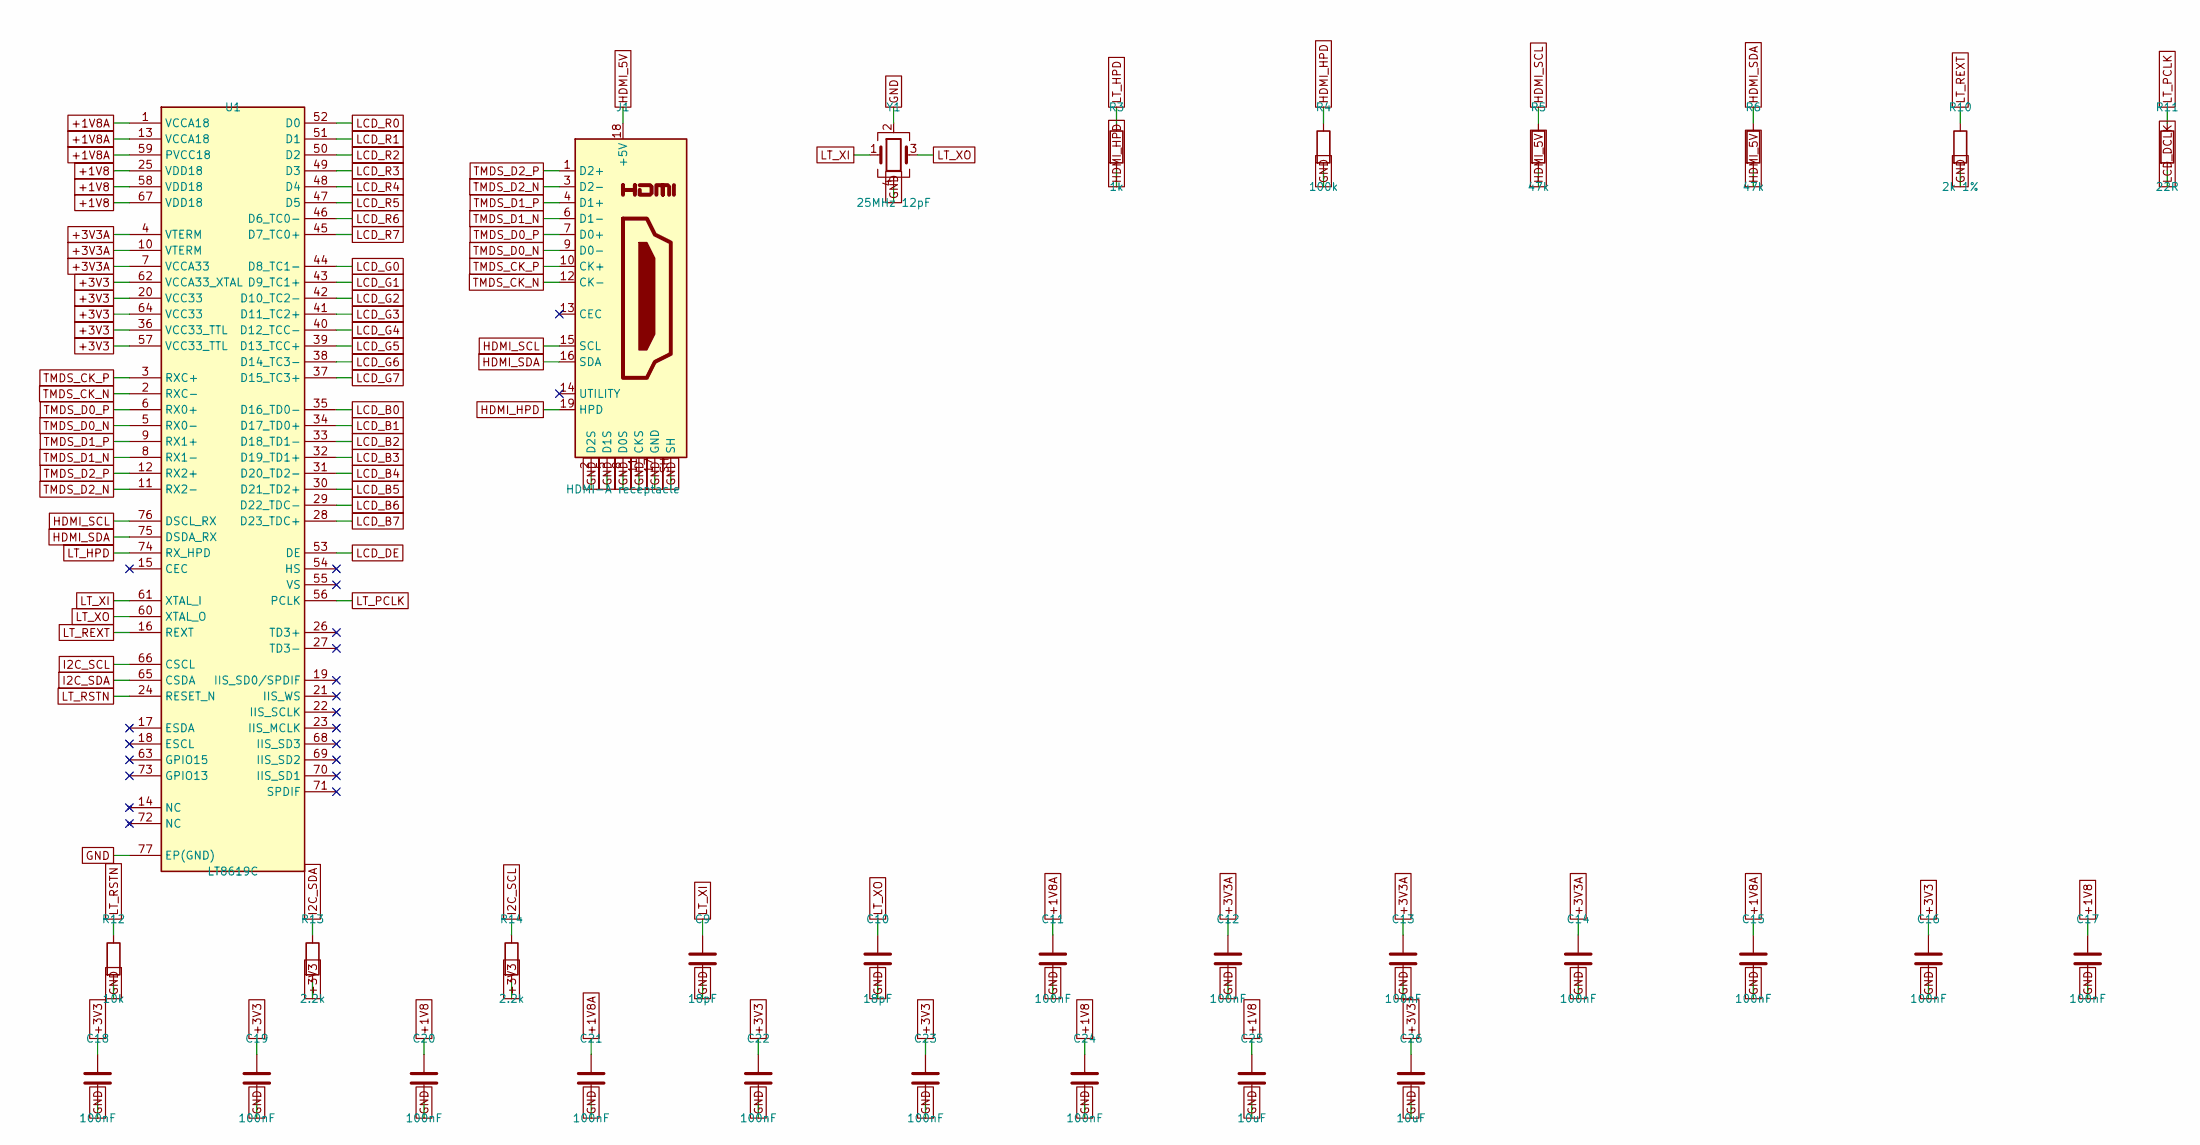
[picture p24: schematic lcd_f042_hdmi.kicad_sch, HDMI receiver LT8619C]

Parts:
C9, C10: 18pF; C_0603_1608Metric
C11, C12, C13, C14, C15, C16, C17, C18, C19, C20, C21, C22, C23, C24: 100nF; C_0603_1608Metric; LCSC C14663
C25, C26: 10uF; C_0603_1608Metric; LCSC C19702
J1: HDMI-A receptacle; HDMI_A_Amphenol_10029449-x01xLF_Horizontal; MPN Amphenol 10029449-001RLF (or equivalent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
R3: 1k; R_0603_1608Metric; LCSC C21190
R4: 100k; R_0603_1608Metric; LCSC C25803
R5, R6: 47k; R_0603_1608Metric
R10: 2k 1%; R_0603_1608Metric
R11: 22R; R_0603_1608Metric
R12: 10k; R_0603_1608Metric; LCSC C25804
R13, R14: 2.2k; R_0603_1608Metric
U1: LT8619C; Lontium_QFN-76_9x9mm_P0.4mm_EP5.81x6.31mm; MPN LT8619C (Lontium)
Y1: 25MHz 12pF; Crystal_SMD_3225-4Pin_3.2x2.5mm; MPN X322525MOB4SI (25MHz CL=12pF)

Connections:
+1V8: C17.1, C20.1, C24.1, C25.1, U1.25 (VDD18), U1.58 (VDD18), U1.67 (VDD18); also elsewhere on the board
+1V8A: C11.1, C15.1, C21.1, U1.1 (VCCA18), U1.13 (VCCA18), U1.59 (PVCC18); also elsewhere on the board
+3V3: C16.1, C18.1, C19.1, C22.1, C23.1, C26.1, R13.2, R14.2, U1.20 (VCC33), U1.36 (VCC33_TTL), U1.57 (VCC33_TTL), U1.62 (VCCA33_XTAL), U1.64 (VCC33); also elsewhere on the board
+3V3A: C12.1, C13.1, C14.1, U1.4 (VTERM), U1.7 (VCCA33), U1.10 (VTERM); also elsewhere on the board
GND: C9.2, C10.2, C11.2, C12.2, C13.2, C14.2, C15.2, C16.2, C17.2, C18.2, C19.2, C20.2, C21.2, C22.2, C23.2, C24.2, C25.2, C26.2, J1.2 (D2S), J1.5 (D1S), J1.8 (D0S), J1.11 (CKS), J1.17 (GND), J1.SH, R4.2, R10.2, R12.2, U1.77 (EP(GND)), Y1.2, Y1.4; also elsewhere on the board
HDMI_5V: J1.18 (+5V), R5.2, R6.2
HDMI_HPD: J1.19 (HPD), R3.2, R4.1
HDMI_SCL: J1.15 (SCL), R5.1, U1.76 (DSCL_RX)
HDMI_SDA: J1.16 (SDA), R6.1, U1.75 (DSDA_RX)
I2C_SCL: R14.1, U1.66 (CSCL); also elsewhere on the board
I2C_SDA: R13.1, U1.65 (CSDA); also elsewhere on the board
LCD_B0: U1.35 (D16_TD0-); also elsewhere on the board
LCD_B1: U1.34 (D17_TD0+); also elsewhere on the board
LCD_B2: U1.33 (D18_TD1-); also elsewhere on the board
LCD_B3: U1.32 (D19_TD1+); also elsewhere on the board
LCD_B4: U1.31 (D20_TD2-); also elsewhere on the board
LCD_B5: U1.30 (D21_TD2+); also elsewhere on the board
LCD_B6: U1.29 (D22_TDC-); also elsewhere on the board
LCD_B7: U1.28 (D23_TDC+); also elsewhere on the board
LCD_DCLK: R11.2; also elsewhere on the board
LCD_DE: U1.53 (DE); also elsewhere on the board
LCD_G0: U1.44 (D8_TC1-); also elsewhere on the board
LCD_G1: U1.43 (D9_TC1+); also elsewhere on the board
LCD_G2: U1.42 (D10_TC2-); also elsewhere on the board
LCD_G3: U1.41 (D11_TC2+); also elsewhere on the board
LCD_G4: U1.40 (D12_TCC-); also elsewhere on the board
LCD_G5: U1.39 (D13_TCC+); also elsewhere on the board
LCD_G6: U1.38 (D14_TC3-); also elsewhere on the board
LCD_G7: U1.37 (D15_TC3+); also elsewhere on the board
LCD_R0: U1.52 (D0); also elsewhere on the board
LCD_R1: U1.51 (D1); also elsewhere on the board
LCD_R2: U1.50 (D2); also elsewhere on the board
LCD_R3: U1.49 (D3); also elsewhere on the board
LCD_R4: U1.48 (D4); also elsewhere on the board
LCD_R5: U1.47 (D5); also elsewhere on the board
LCD_R6: U1.46 (D6_TC0-); also elsewhere on the board
LCD_R7: U1.45 (D7_TC0+); also elsewhere on the board
LT_HPD: R3.1, U1.74 (RX_HPD)
LT_PCLK: R11.1, U1.56 (PCLK)
LT_REXT: R10.1, U1.16 (REXT)
LT_RSTN: R12.1, U1.24 (RESET_N); also elsewhere on the board
LT_XI: C9.1, U1.61 (XTAL_I), Y1.1
LT_XO: C10.1, U1.60 (XTAL_O), Y1.3
TMDS_CK_N: J1.12 (CK-), U1.2 (RXC-)
TMDS_CK_P: J1.10 (CK+), U1.3 (RXC+)
TMDS_D0_N: J1.9 (D0-), U1.5 (RX0-)
TMDS_D0_P: J1.7 (D0+), U1.6 (RX0+)
TMDS_D1_N: J1.6 (D1-), U1.8 (RX1-)
TMDS_D1_P: J1.4 (D1+), U1.9 (RX1+)
TMDS_D2_N: J1.3 (D2-), U1.11 (RX2-)
TMDS_D2_P: J1.1 (D2+), U1.12 (RX2+)

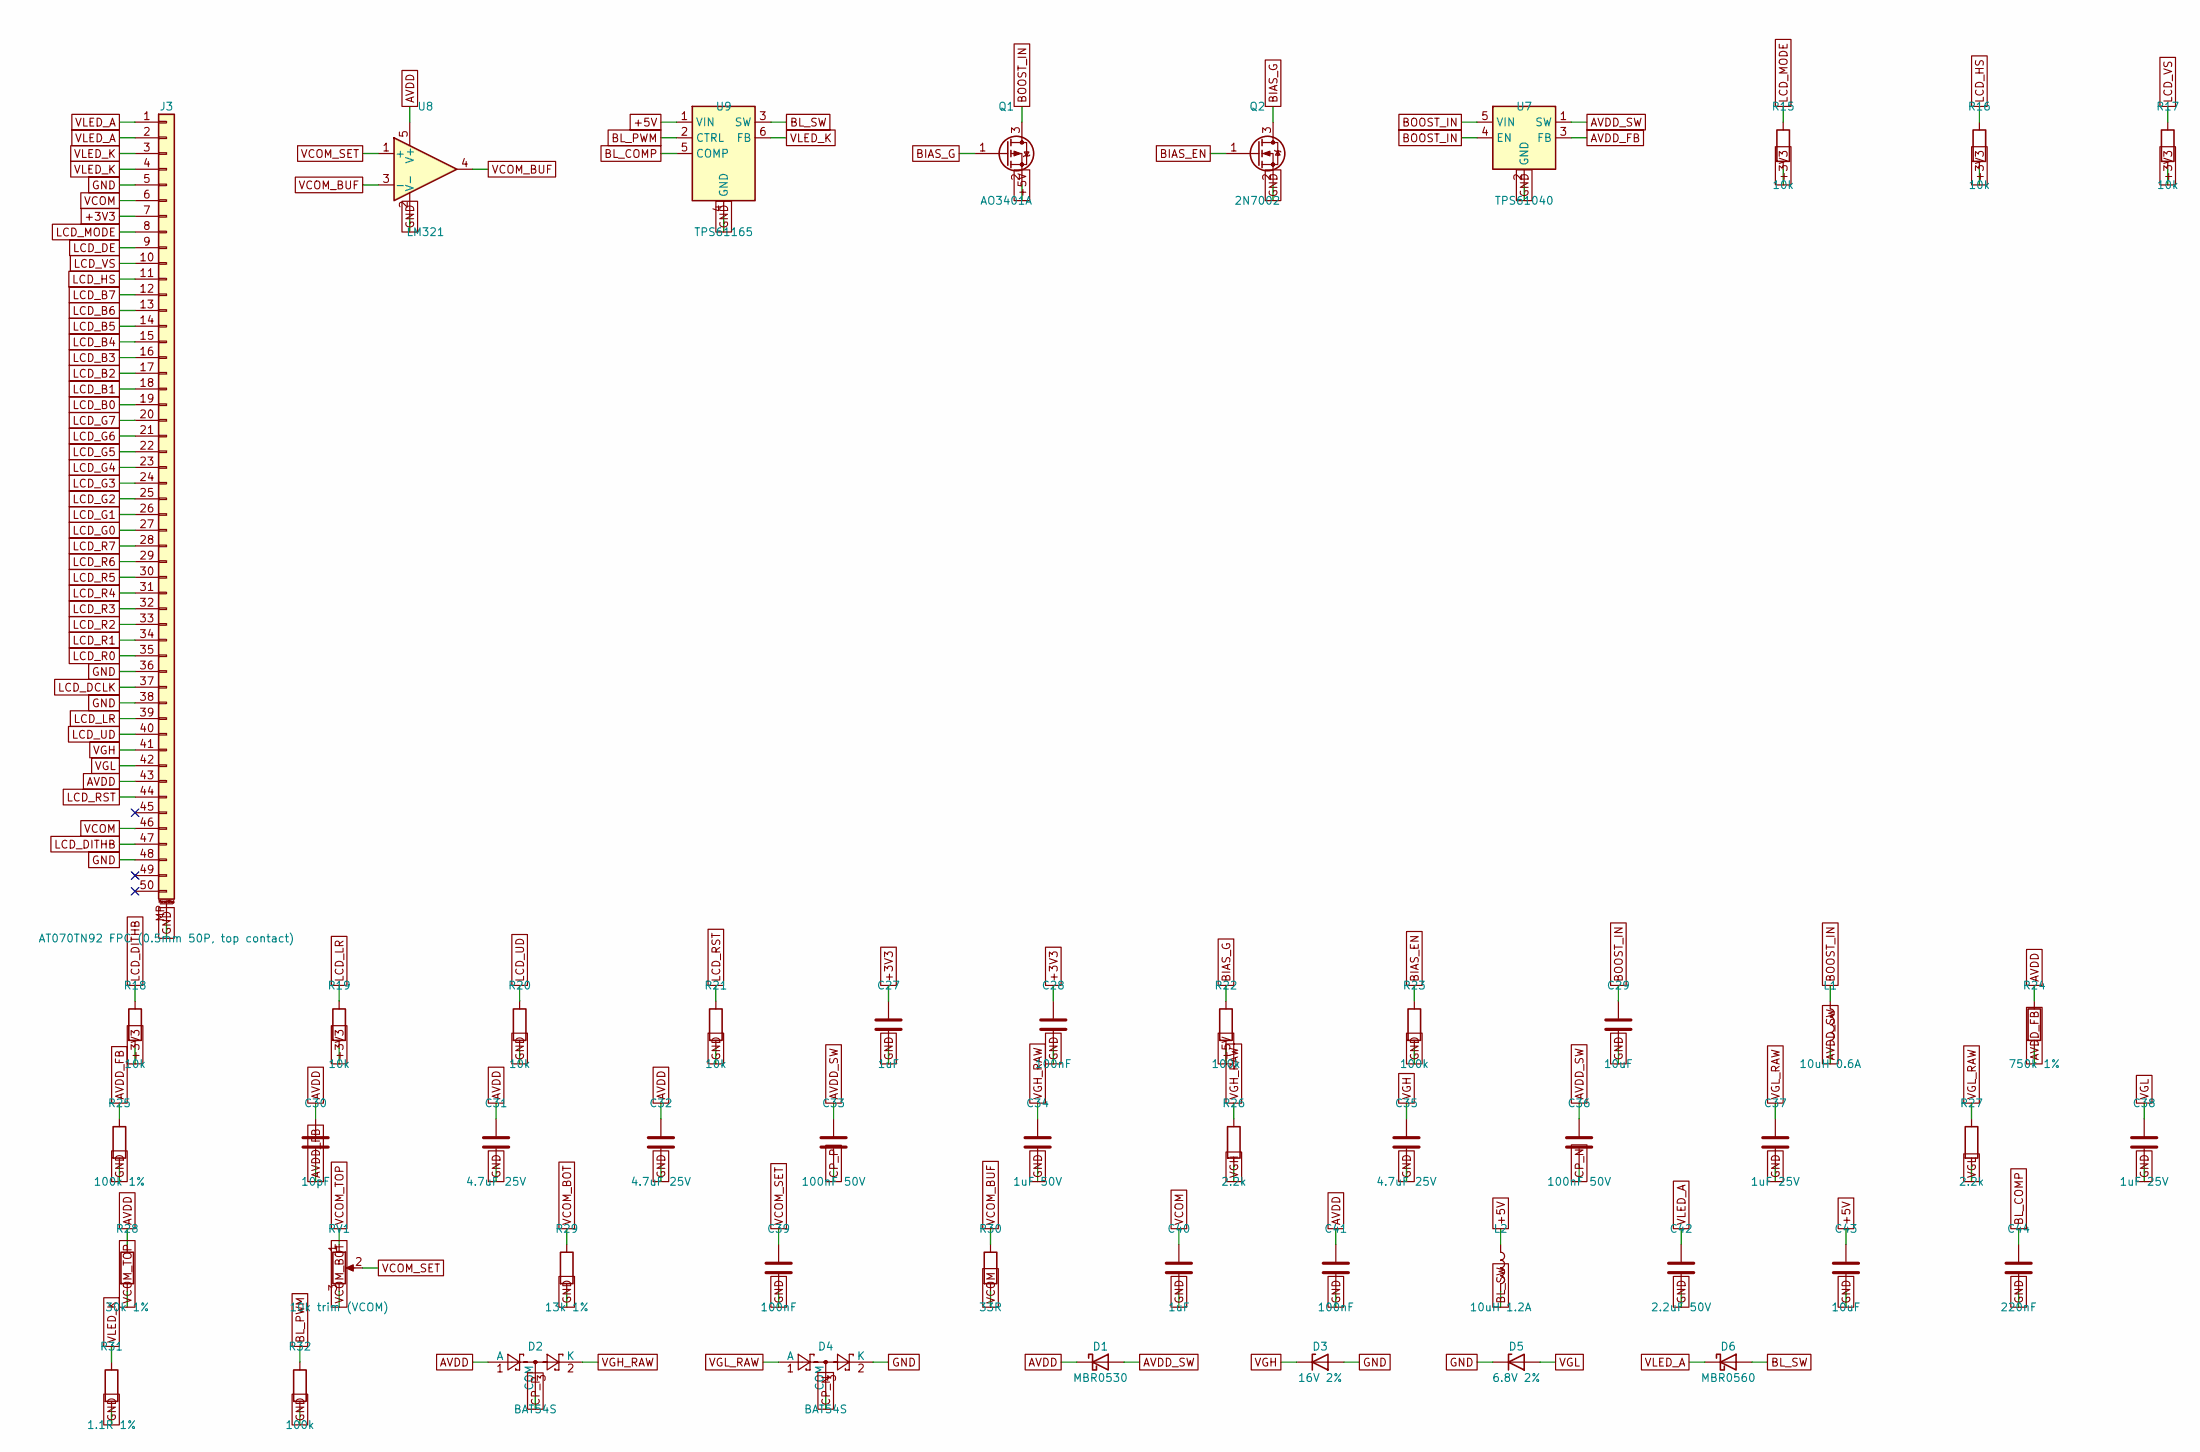
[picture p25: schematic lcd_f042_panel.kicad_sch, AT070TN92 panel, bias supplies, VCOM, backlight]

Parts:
C27, C40: 1uF; C_0603_1608Metric; LCSC C15849
C28, C39, C41: 100nF; C_0603_1608Metric; LCSC C14663
C29, C43: 10uF; C_0603_1608Metric; LCSC C19702
C30: 10pF; C_0603_1608Metric
C31, C32, C35: 4.7uF 25V; C_0805_2012Metric
C33, C36: 100nF 50V; C_0603_1608Metric; LCSC C14663
C34: 1uF 50V; C_0805_2012Metric
C37, C38: 1uF 25V; C_0603_1608Metric; LCSC C15849
C42: 2.2uF 50V; C_1206_3216Metric
C44: 220nF; C_0603_1608Metric
D1: MBR0530; D_SOD-123; MPN MBR0530T1G
D2, D4: BAT54S; SOT-23; MPN BAT54S
D3: 16V 2%; D_SOD-323; MPN BZX384-B16
D5: 6.8V 2%; D_SOD-323; MPN BZX384-B6V8
D6: MBR0560; D_SOD-123; MPN MBR0560T1G
J3: AT070TN92 FPC (0.5mm 50P, top contact); FPC_50P_P0.5_TopContact_AT070TN92; MPN Hirose FH12A-50S-0.5SH(55) (top contact)
L1: 10uH 0.6A; L_Taiyo-Yuden_NR-30xx; MPN NR3015T100M
L2: 10uH 1.2A; L_Taiyo-Yuden_NR-40xx; MPN NR4018T100M
Q1: AO3401A; SOT-23; MPN AO3401A; LCSC C15127
Q2: 2N7002; SOT-23; MPN 2N7002; LCSC C8545
R15, R16, R17, R18, R19, R20, R21: 10k; R_0603_1608Metric; LCSC C25804
R22, R23, R32: 100k; R_0603_1608Metric; LCSC C25803
R24: 750k 1%; R_0603_1608Metric
R25: 100k 1%; R_0603_1608Metric; LCSC C25803
R26, R27: 2.2k; R_0603_1608Metric
R28: 30k 1%; R_0603_1608Metric
R29: 13k 1%; R_0603_1608Metric
R30: 33R; R_0603_1608Metric
R31: 1.1R 1%; R_0805_2012Metric
RV1: 10k trim (VCOM); Potentiometer_Bourns_TC33X_Vertical; MPN Bourns TC33X-2-103E
U7: TPS61040; SOT-23-5; MPN TPS61040DBVR
U8: LM321; SOT-23-5; MPN LM321MFX
U9: TPS61165; SOT-23-6; MPN TPS61165DBVR

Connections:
+3V3: C27.1, C28.1, J3.7, R15.2, R16.2, R17.2, R18.2, R19.2; also elsewhere on the board
+5V: C43.1, L2.1, Q1.2 (S), R22.2, U9.1 (VIN); also elsewhere on the board
AVDD: C30.1, C31.1, C32.1, C41.1, D1.1 (K), D2.1 (A), J3.43, R24.1, R28.1, U8.5 (V+); also elsewhere on the board
AVDD_FB: C30.2, R24.2, R25.1, U7.3 (FB)
AVDD_SW: C33.1, C36.1, D1.2 (A), L1.2, U7.1 (SW)
BIAS_EN: Q2.1 (G), R23.1; also elsewhere on the board
BIAS_G: Q1.1 (G), Q2.3 (D), R22.1
BL_COMP: C44.1, U9.5 (COMP)
BL_PWM: R32.1, U9.2 (CTRL); also elsewhere on the board
BL_SW: D6.2 (A), L2.2, U9.3 (SW)
BOOST_IN: C29.1, L1.1, Q1.3 (D), U7.4 (EN), U7.5 (VIN)
CP_N: C36.2, D4.3 (COM)
CP_P: C33.2, D2.3 (COM)
GND: C27.2, C28.2, C29.2, C31.2, C32.2, C34.2, C35.2, C37.2, C38.2, C39.2, C40.2, C41.2, C42.2, C43.2, C44.2, D3.2 (A), D4.2 (K), D5.1 (K), J3.5, J3.36, J3.38, J3.48, J3.MP (MountPin), Q2.2 (S), R20.2, R21.2, R23.2, R25.2, R29.2, R31.2, R32.2, U7.2 (GND), U8.2 (V-), U9.4 (GND); also elsewhere on the board
LCD_B0: J3.19; also elsewhere on the board
LCD_B1: J3.18; also elsewhere on the board
LCD_B2: J3.17; also elsewhere on the board
LCD_B3: J3.16; also elsewhere on the board
LCD_B4: J3.15; also elsewhere on the board
LCD_B5: J3.14; also elsewhere on the board
LCD_B6: J3.13; also elsewhere on the board
LCD_B7: J3.12; also elsewhere on the board
LCD_DCLK: J3.37; also elsewhere on the board
LCD_DE: J3.9; also elsewhere on the board
LCD_DITHB: J3.47, R18.1
LCD_G0: J3.27; also elsewhere on the board
LCD_G1: J3.26; also elsewhere on the board
LCD_G2: J3.25; also elsewhere on the board
LCD_G3: J3.24; also elsewhere on the board
LCD_G4: J3.23; also elsewhere on the board
LCD_G5: J3.22; also elsewhere on the board
LCD_G6: J3.21; also elsewhere on the board
LCD_G7: J3.20; also elsewhere on the board
LCD_HS: J3.11, R16.1
LCD_LR: J3.39, R19.1
LCD_MODE: J3.8, R15.1
LCD_R0: J3.35; also elsewhere on the board
LCD_R1: J3.34; also elsewhere on the board
LCD_R2: J3.33; also elsewhere on the board
LCD_R3: J3.32; also elsewhere on the board
LCD_R4: J3.31; also elsewhere on the board
LCD_R5: J3.30; also elsewhere on the board
LCD_R6: J3.29; also elsewhere on the board
LCD_R7: J3.28; also elsewhere on the board
LCD_RST: J3.44, R21.1; also elsewhere on the board
LCD_UD: J3.40, R20.1
LCD_VS: J3.10, R17.1
VCOM: C40.1, J3.6, J3.46, R30.2; also elsewhere on the board
VCOM_BOT: R29.1, RV1.3
VCOM_BUF: R30.1, U8.3 (-), U8.4
VCOM_SET: C39.1, RV1.2, U8.1 (+)
VCOM_TOP: R28.2, RV1.1
VGH: C35.1, D3.1 (K), J3.41, R26.2; also elsewhere on the board
VGH_RAW: C34.1, D2.2 (K), R26.1
VGL: C38.1, D5.2 (A), J3.42, R27.2; also elsewhere on the board
VGL_RAW: C37.1, D4.1 (A), R27.1
VLED_A: C42.1, D6.1 (K), J3.1, J3.2
VLED_K: J3.3, J3.4, R31.1, U9.6 (FB)

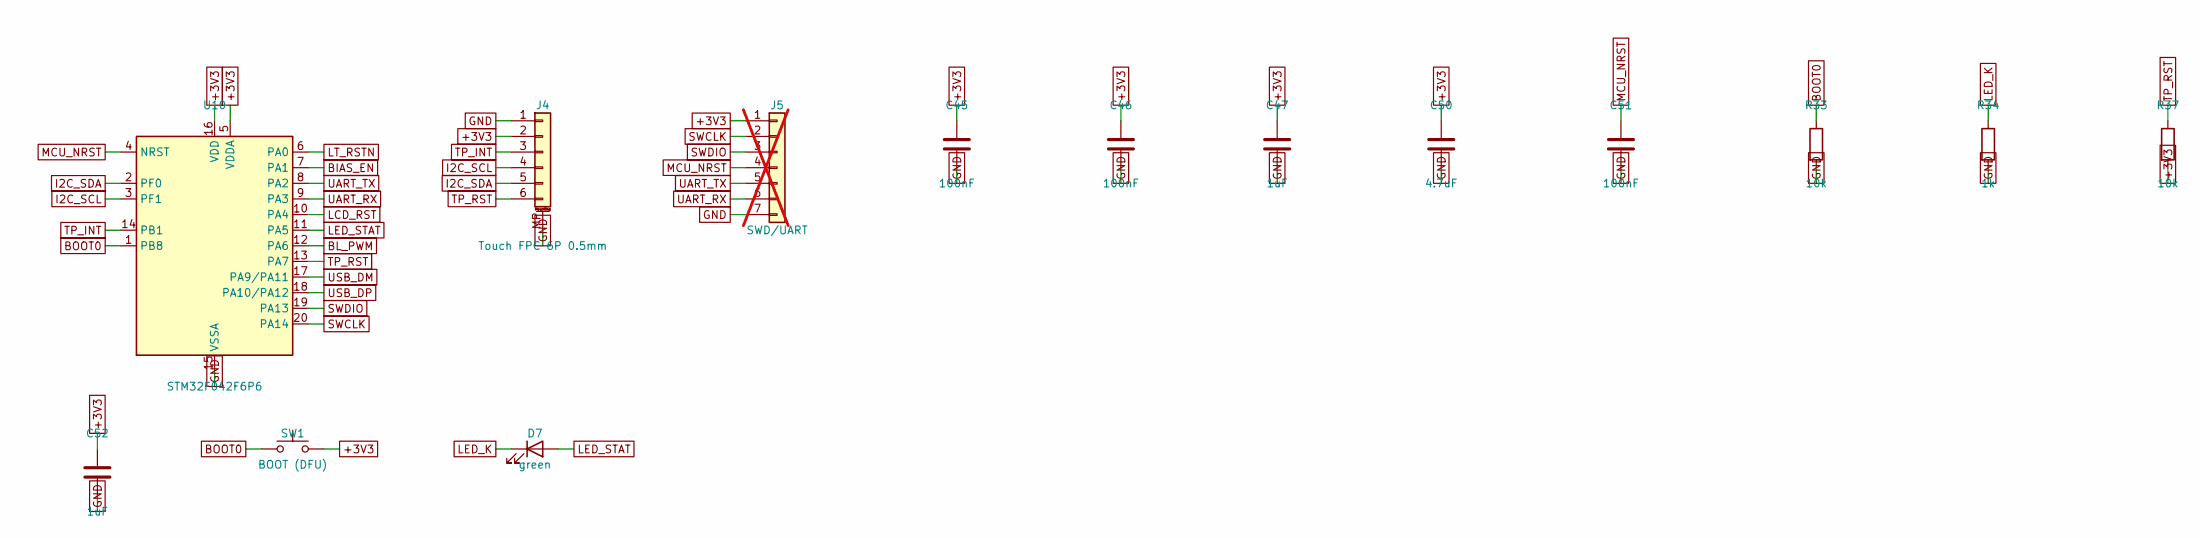
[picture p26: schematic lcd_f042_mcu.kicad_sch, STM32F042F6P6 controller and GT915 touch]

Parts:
C45, C46, C51: 100nF; C_0603_1608Metric; LCSC C14663
C47, C52: 1uF; C_0603_1608Metric; LCSC C15849
C50: 4.7uF; C_0603_1608Metric
D7: green; LED_0603_1608Metric
J4: Touch FPC 6P 0.5mm; Hirose_FH12-6S-0.5SH_1x06-1MP_P0.50mm_Horizontal; MPN Hirose FH12-6S-0.5SH (check contact sid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
J5: SWD/UART; PinHeader_1x07_P1.27mm_Vertical; not fitted
R33, R37: 10k; R_0603_1608Metric; LCSC C25804
R34: 1k; R_0603_1608Metric; LCSC C21190
SW1: BOOT (DFU); SW_SPST_B3U-1000P; MPN Omron B3U-1000P
U10: STM32F042F6P6; TSSOP-20_4.4x6.5mm_P0.65mm; MPN STM32F042F6P6

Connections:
+3V3: C45.1, C46.1, C47.1, C50.1, C52.1, J4.2, J5.1, R37.2, SW1.2, U10.5 (VDDA), U10.16 (VDD); also elsewhere on the board
BIAS_EN: U10.7 (PA1); also elsewhere on the board
BL_PWM: U10.12 (PA6); also elsewhere on the board
BOOT0: R33.1, SW1.1, U10.1 (PB8)
GND: C45.2, C46.2, C47.2, C50.2, C51.2, C52.2, J4.1, J4.MP (MountPin), J5.7, R33.2, R34.2, U10.15 (VSSA); also elsewhere on the board
I2C_SCL: J4.4, U10.3 (PF1); also elsewhere on the board
I2C_SDA: J4.5, U10.2 (PF0); also elsewhere on the board
LCD_RST: U10.10 (PA4); also elsewhere on the board
LED_K: D7.1 (K), R34.1
LED_STAT: D7.2 (A), U10.11 (PA5)
LT_RSTN: U10.6 (PA0); also elsewhere on the board
MCU_NRST: C51.1, J5.4, U10.4 (NRST)
SWCLK: J5.2, U10.20 (PA14)
SWDIO: J5.3, U10.19 (PA13)
TP_INT: J4.3, U10.14 (PB1)
TP_RST: J4.6, R37.1, U10.13 (PA7)
UART_RX: J5.6, U10.9 (PA3)
UART_TX: J5.5, U10.8 (PA2)
USB_DM: U10.17 (PA9/PA11); also elsewhere on the board
USB_DP: U10.18 (PA10/PA12); also elsewhere on the board

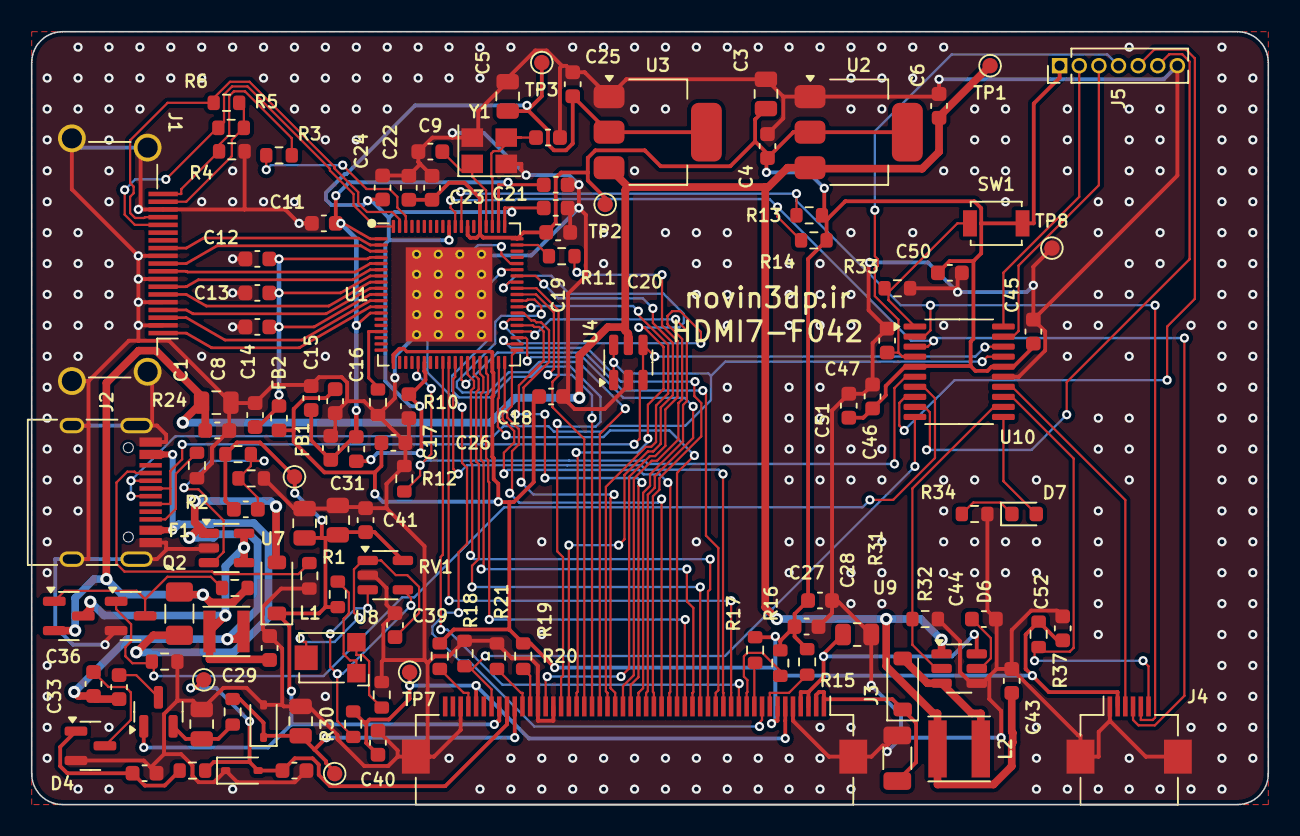
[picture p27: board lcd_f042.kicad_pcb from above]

Board: 2 copper layers, 80.0 x 50.0 mm, 120 parts (0 on the bottom side), 96 nets.

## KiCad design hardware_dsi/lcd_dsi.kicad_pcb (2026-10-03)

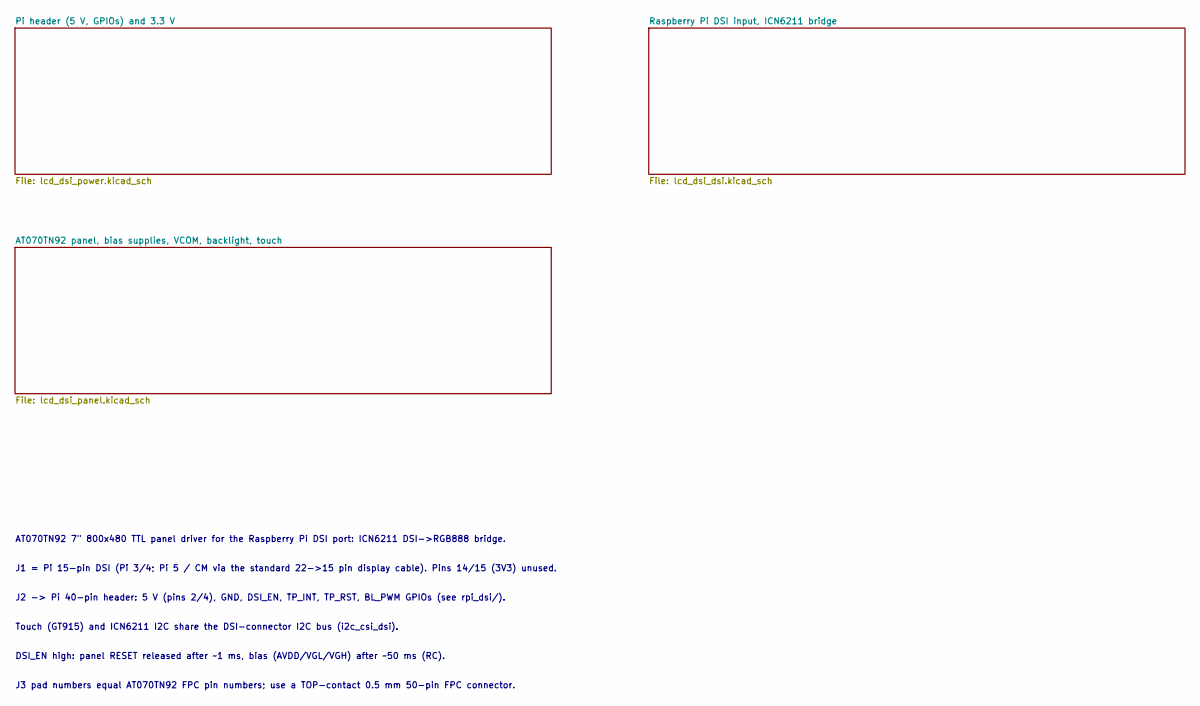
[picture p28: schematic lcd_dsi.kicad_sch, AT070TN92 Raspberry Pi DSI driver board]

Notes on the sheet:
AT070TN92 7" 800x480 TTL panel driver for the Raspberry Pi DSI port: ICN6211 DSI->RGB888 bridge.
J1 = Pi 15-pin DSI (Pi 3/4; Pi 5 / CM via the standard 22->15 pin display cable). Pins 14/15 (3V3) unused.
J2 -> Pi 40-pin header: 5 V (pins 2/4), GND, DSI_EN, TP_INT, TP_RST, BL_PWM GPIOs (see rpi_dsi/).
Touch (GT915) and ICN6211 I2C share the DSI-connector I2C bus (i2c_csi_dsi).
DSI_EN high: panel RESET released after ~1 ms, bias (AVDD/VGL/VGH) after ~50 ms (RC).
J3 pad numbers equal AT070TN92 FPC pin numbers; use a TOP-contact 0.5 mm 50-pin FPC connector.

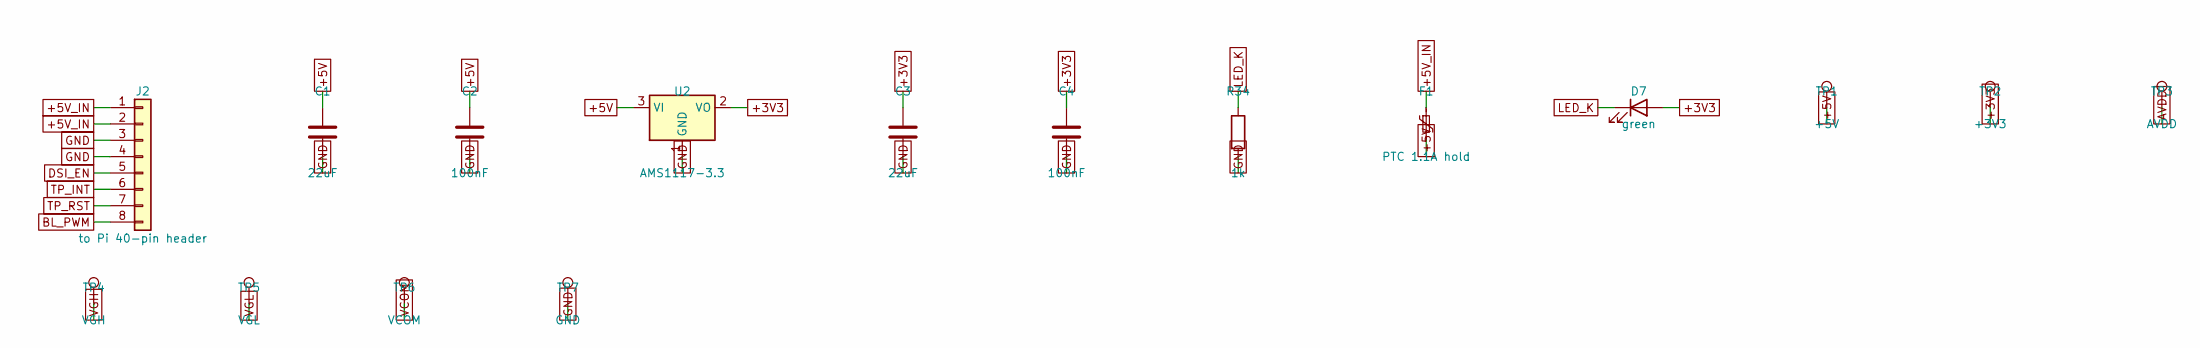
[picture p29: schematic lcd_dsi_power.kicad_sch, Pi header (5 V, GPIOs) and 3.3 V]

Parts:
C1, C3: 22uF; C_0805_2012Metric
C2, C4: 100nF; C_0603_1608Metric; LCSC C14663
D7: green; LED_0603_1608Metric
F1: PTC 1.1A hold; Fuse_1206_3216Metric; MPN 1206L110/16 (or BSMD1206-110)
J2: to Pi 40-pin header; PinHeader_1x08_P2.54mm_Vertical; MPN 1x8 2.54mm pin header
R34: 1k; R_0603_1608Metric; LCSC C21190
TP1: +5V; TestPoint_Pad_D1.0mm
TP2: +3V3; TestPoint_Pad_D1.0mm
TP3: AVDD; TestPoint_Pad_D1.0mm
TP4: VGH; TestPoint_Pad_D1.0mm
TP5: VGL; TestPoint_Pad_D1.0mm
TP6: VCOM; TestPoint_Pad_D1.0mm
TP7: GND; TestPoint_Pad_D1.0mm
U2: AMS1117-3.3; SOT-223-3_TabPin2; MPN AMS1117-3.3; LCSC C6186

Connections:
+3V3: C3.1, C4.1, D7.2 (A), TP2.1, U2.2 (VO); also elsewhere on the board
+5V: C1.1, C2.1, F1.2, TP1.1, U2.3 (VI); also elsewhere on the board
+5V_IN: F1.1, J2.1, J2.2
AVDD: TP3.1; also elsewhere on the board
BL_PWM: J2.8; also elsewhere on the board
DSI_EN: J2.5; also elsewhere on the board
GND: C1.2, C2.2, C3.2, C4.2, J2.3, J2.4, R34.2, TP7.1, U2.1 (GND); also elsewhere on the board
LED_K: D7.1 (K), R34.1
TP_INT: J2.6; also elsewhere on the board
TP_RST: J2.7; also elsewhere on the board
VCOM: TP6.1; also elsewhere on the board
VGH: TP4.1; also elsewhere on the board
VGL: TP5.1; also elsewhere on the board

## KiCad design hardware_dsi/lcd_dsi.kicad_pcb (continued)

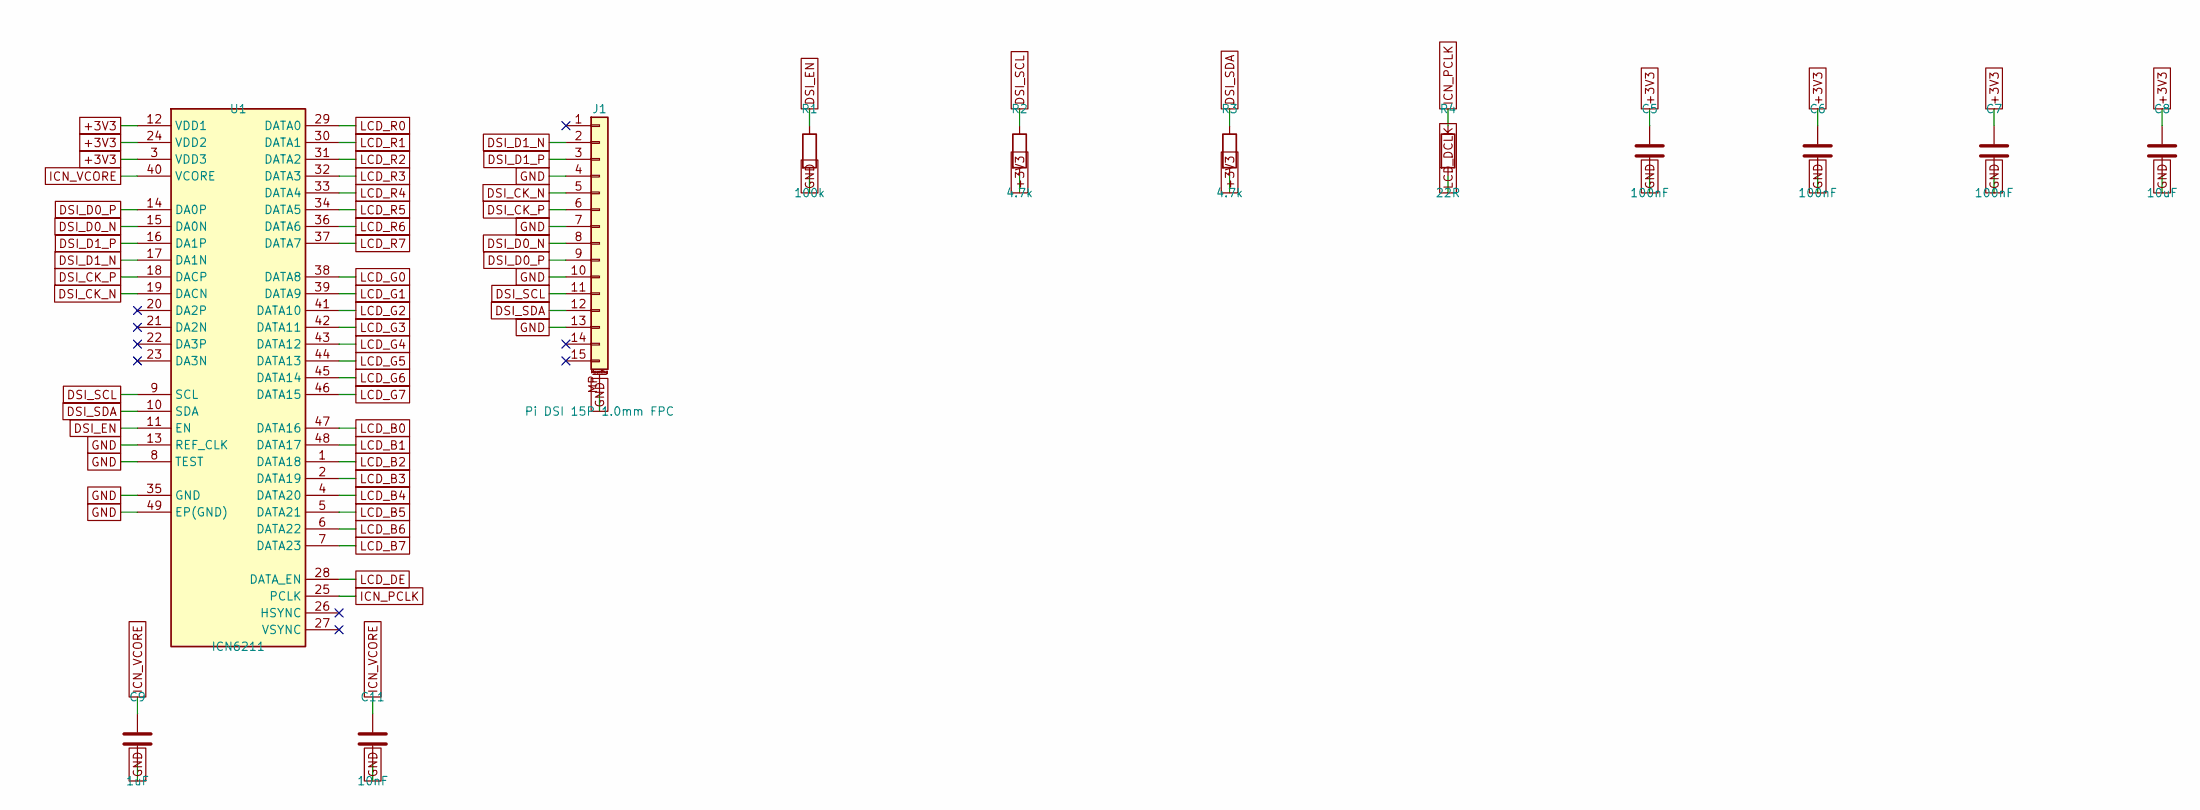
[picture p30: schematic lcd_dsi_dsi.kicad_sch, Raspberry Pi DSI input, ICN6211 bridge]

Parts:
C5, C6, C7: 100nF; C_0603_1608Metric; LCSC C14663
C8: 10uF; C_0603_1608Metric; LCSC C19702
C9: 1uF; C_0603_1608Metric; LCSC C15849
C11: 10nF; C_0603_1608Metric
J1: Pi DSI 15P 1.0mm FPC; FPC_15P_P1.0_PiDSI; MPN 1.0mm 15P FPC, dual contact (TE 1-84953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
R1: 100k; R_0603_1608Metric; LCSC C25803
R2, R3: 4.7k; R_0603_1608Metric; LCSC C23162
R4: 22R; R_0603_1608Metric
U1: ICN6211; QFN-48-1EP_6x6mm_P0.4mm_EP4.2x4.2mm_Vias0.3; MPN ICN6211 (Chipone); LCSC C246085

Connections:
+3V3: C5.1, C6.1, C7.1, C8.1, R2.2, R3.2, U1.3 (VDD3), U1.12 (VDD1), U1.24 (VDD2); also elsewhere on the board
DSI_CK_N: J1.5, U1.19 (DACN)
DSI_CK_P: J1.6, U1.18 (DACP)
DSI_D0_N: J1.8, U1.15 (DA0N)
DSI_D0_P: J1.9, U1.14 (DA0P)
DSI_D1_N: J1.2, U1.17 (DA1N)
DSI_D1_P: J1.3, U1.16 (DA1P)
DSI_EN: R1.1, U1.11 (EN); also elsewhere on the board
DSI_SCL: J1.11, R2.1, U1.9 (SCL); also elsewhere on the board
DSI_SDA: J1.12, R3.1, U1.10 (SDA); also elsewhere on the board
GND: C5.2, C6.2, C7.2, C8.2, C9.2, C11.2, J1.4, J1.7, J1.10, J1.13, J1.MP (MountPin), R1.2, U1.8 (TEST), U1.13 (REF_CLK), U1.35 (GND), U1.49 (EP(GND)); also elsewhere on the board
ICN_PCLK: R4.1, U1.25 (PCLK)
ICN_VCORE: C9.1, C11.1, U1.40 (VCORE)
LCD_B0: U1.47 (DATA16); also elsewhere on the board
LCD_B1: U1.48 (DATA17); also elsewhere on the board
LCD_B2: U1.1 (DATA18); also elsewhere on the board
LCD_B3: U1.2 (DATA19); also elsewhere on the board
LCD_B4: U1.4 (DATA20); also elsewhere on the board
LCD_B5: U1.5 (DATA21); also elsewhere on the board
LCD_B6: U1.6 (DATA22); also elsewhere on the board
LCD_B7: U1.7 (DATA23); also elsewhere on the board
LCD_DCLK: R4.2; also elsewhere on the board
LCD_DE: U1.28 (DATA_EN); also elsewhere on the board
LCD_G0: U1.38 (DATA8); also elsewhere on the board
LCD_G1: U1.39 (DATA9); also elsewhere on the board
LCD_G2: U1.41 (DATA10); also elsewhere on the board
LCD_G3: U1.42 (DATA11); also elsewhere on the board
LCD_G4: U1.43 (DATA12); also elsewhere on the board
LCD_G5: U1.44 (DATA13); also elsewhere on the board
LCD_G6: U1.45 (DATA14); also elsewhere on the board
LCD_G7: U1.46 (DATA15); also elsewhere on the board
LCD_R0: U1.29 (DATA0); also elsewhere on the board
LCD_R1: U1.30 (DATA1); also elsewhere on the board
LCD_R2: U1.31 (DATA2); also elsewhere on the board
LCD_R3: U1.32 (DATA3); also elsewhere on the board
LCD_R4: U1.33 (DATA4); also elsewhere on the board
LCD_R5: U1.34 (DATA5); also elsewhere on the board
LCD_R6: U1.36 (DATA6); also elsewhere on the board
LCD_R7: U1.37 (DATA7); also elsewhere on the board

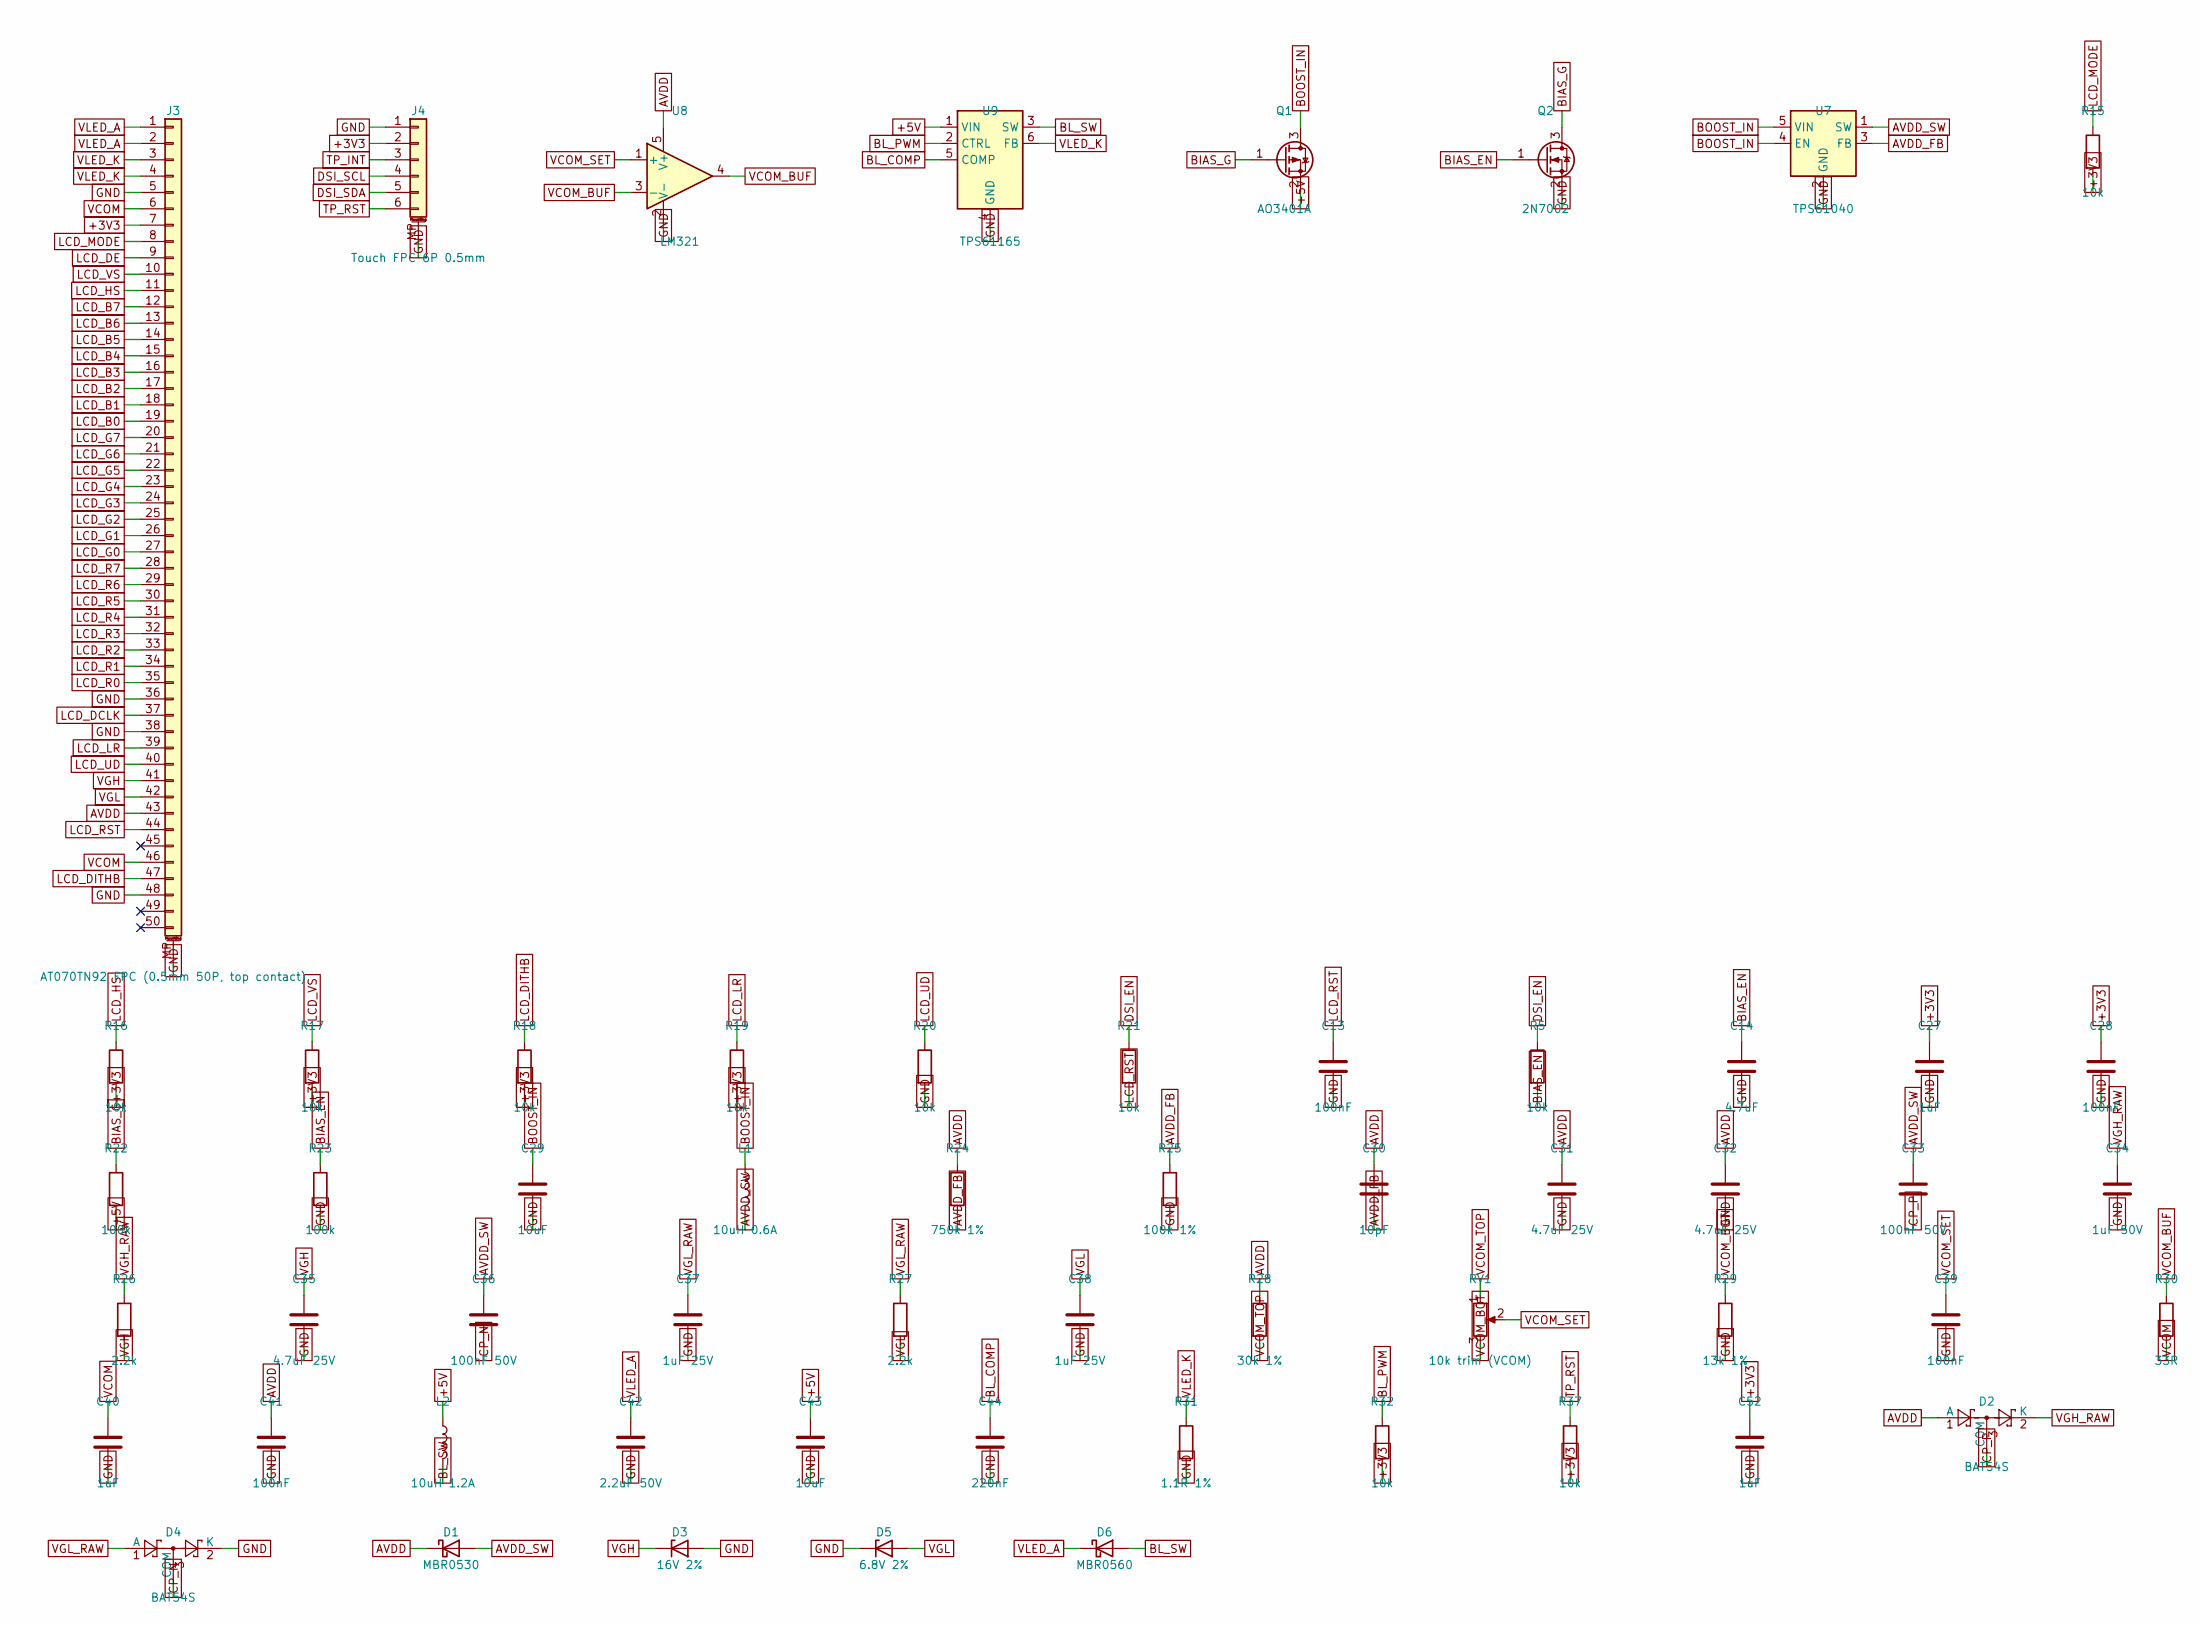
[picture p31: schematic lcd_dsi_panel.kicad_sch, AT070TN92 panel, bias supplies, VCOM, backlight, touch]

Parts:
C13, C28, C39, C41: 100nF; C_0603_1608Metric; LCSC C14663
C14: 4.7uF; C_0603_1608Metric
C27, C40, C52: 1uF; C_0603_1608Metric; LCSC C15849
C29, C43: 10uF; C_0603_1608Metric; LCSC C19702
C30: 10pF; C_0603_1608Metric
C31, C32, C35: 4.7uF 25V; C_0805_2012Metric
C33, C36: 100nF 50V; C_0603_1608Metric; LCSC C14663
C34: 1uF 50V; C_0805_2012Metric
C37, C38: 1uF 25V; C_0603_1608Metric; LCSC C15849
C42: 2.2uF 50V; C_1206_3216Metric
C44: 220nF; C_0603_1608Metric
D1: MBR0530; D_SOD-123; MPN MBR0530T1G
D2, D4: BAT54S; SOT-23; MPN BAT54S
D3: 16V 2%; D_SOD-323; MPN BZX384-B16
D5: 6.8V 2%; D_SOD-323; MPN BZX384-B6V8
D6: MBR0560; D_SOD-123; MPN MBR0560T1G
J3: AT070TN92 FPC (0.5mm 50P, top contact); FPC_50P_P0.5_TopContact_AT070TN92; MPN Hirose FH12A-50S-0.5SH(55) (top contact)
J4: Touch FPC 6P 0.5mm; Hirose_FH12-6S-0.5SH_1x06-1MP_P0.50mm_Horizontal; MPN Hirose FH12-6S-0.5SH (check contact sid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
L1: 10uH 0.6A; L_Taiyo-Yuden_NR-30xx; MPN NR3015T100M
L2: 10uH 1.2A; L_Taiyo-Yuden_NR-40xx; MPN NR4018T100M
Q1: AO3401A; SOT-23; MPN AO3401A; LCSC C15127
Q2: 2N7002; SOT-23; MPN 2N7002; LCSC C8545
R5, R15, R16, R17, R18, R19, R20, R21, R32, R37: 10k; R_0603_1608Metric; LCSC C25804
R22, R23: 100k; R_0603_1608Metric; LCSC C25803
R24: 750k 1%; R_0603_1608Metric
R25: 100k 1%; R_0603_1608Metric; LCSC C25803
R26, R27: 2.2k; R_0603_1608Metric
R28: 30k 1%; R_0603_1608Metric
R29: 13k 1%; R_0603_1608Metric
R30: 33R; R_0603_1608Metric
R31: 1.1R 1%; R_0805_2012Metric
RV1: 10k trim (VCOM); Potentiometer_Bourns_TC33X_Vertical; MPN Bourns TC33X-2-103E
U7: TPS61040; SOT-23-5; MPN TPS61040DBVR
U8: LM321; SOT-23-5; MPN LM321MFX
U9: TPS61165; SOT-23-6; MPN TPS61165DBVR

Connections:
+3V3: C27.1, C28.1, C52.1, J3.7, J4.2, R15.2, R16.2, R17.2, R18.2, R19.2, R32.2, R37.2; also elsewhere on the board
+5V: C43.1, L2.1, Q1.2 (S), R22.2, U9.1 (VIN); also elsewhere on the board
AVDD: C30.1, C31.1, C32.1, C41.1, D1.1 (K), D2.1 (A), J3.43, R24.1, R28.1, U8.5 (V+); also elsewhere on the board
AVDD_FB: C30.2, R24.2, R25.1, U7.3 (FB)
AVDD_SW: C33.1, C36.1, D1.2 (A), L1.2, U7.1 (SW)
BIAS_EN: C14.1, Q2.1 (G), R5.2, R23.1
BIAS_G: Q1.1 (G), Q2.3 (D), R22.1
BL_COMP: C44.1, U9.5 (COMP)
BL_PWM: R32.1, U9.2 (CTRL); also elsewhere on the board
BL_SW: D6.2 (A), L2.2, U9.3 (SW)
BOOST_IN: C29.1, L1.1, Q1.3 (D), U7.4 (EN), U7.5 (VIN)
CP_N: C36.2, D4.3 (COM)
CP_P: C33.2, D2.3 (COM)
DSI_EN: R5.1, R21.1; also elsewhere on the board
DSI_SCL: J4.4; also elsewhere on the board
DSI_SDA: J4.5; also elsewhere on the board
GND: C13.2, C14.2, C27.2, C28.2, C29.2, C31.2, C32.2, C34.2, C35.2, C37.2, C38.2, C39.2, C40.2, C41.2, C42.2, C43.2, C44.2, C52.2, D3.2 (A), D4.2 (K), D5.1 (K), J3.5, J3.36, J3.38, J3.48, J3.MP (MountPin), J4.1, J4.MP (MountPin), Q2.2 (S), R20.2, R23.2, R25.2, R29.2, R31.2, U7.2 (GND), U8.2 (V-), U9.4 (GND); also elsewhere on the board
LCD_B0: J3.19; also elsewhere on the board
LCD_B1: J3.18; also elsewhere on the board
LCD_B2: J3.17; also elsewhere on the board
LCD_B3: J3.16; also elsewhere on the board
LCD_B4: J3.15; also elsewhere on the board
LCD_B5: J3.14; also elsewhere on the board
LCD_B6: J3.13; also elsewhere on the board
LCD_B7: J3.12; also elsewhere on the board
LCD_DCLK: J3.37; also elsewhere on the board
LCD_DE: J3.9; also elsewhere on the board
LCD_DITHB: J3.47, R18.1
LCD_G0: J3.27; also elsewhere on the board
LCD_G1: J3.26; also elsewhere on the board
LCD_G2: J3.25; also elsewhere on the board
LCD_G3: J3.24; also elsewhere on the board
LCD_G4: J3.23; also elsewhere on the board
LCD_G5: J3.22; also elsewhere on the board
LCD_G6: J3.21; also elsewhere on the board
LCD_G7: J3.20; also elsewhere on the board
LCD_HS: J3.11, R16.1
LCD_LR: J3.39, R19.1
LCD_MODE: J3.8, R15.1
LCD_R0: J3.35; also elsewhere on the board
LCD_R1: J3.34; also elsewhere on the board
LCD_R2: J3.33; also elsewhere on the board
LCD_R3: J3.32; also elsewhere on the board
LCD_R4: J3.31; also elsewhere on the board
LCD_R5: J3.30; also elsewhere on the board
LCD_R6: J3.29; also elsewhere on the board
LCD_R7: J3.28; also elsewhere on the board
LCD_RST: C13.1, J3.44, R21.2
LCD_UD: J3.40, R20.1
LCD_VS: J3.10, R17.1
TP_INT: J4.3; also elsewhere on the board
TP_RST: J4.6, R37.1; also elsewhere on the board
VCOM: C40.1, J3.6, J3.46, R30.2; also elsewhere on the board
VCOM_BOT: R29.1, RV1.3
VCOM_BUF: R30.1, U8.3 (-), U8.4
VCOM_SET: C39.1, RV1.2, U8.1 (+)
VCOM_TOP: R28.2, RV1.1
VGH: C35.1, D3.1 (K), J3.41, R26.2; also elsewhere on the board
VGH_RAW: C34.1, D2.2 (K), R26.1
VGL: C38.1, D5.2 (A), J3.42, R27.2; also elsewhere on the board
VGL_RAW: C37.1, D4.1 (A), R27.1
VLED_A: C42.1, D6.1 (K), J3.1, J3.2
VLED_K: J3.3, J3.4, R31.1, U9.6 (FB)

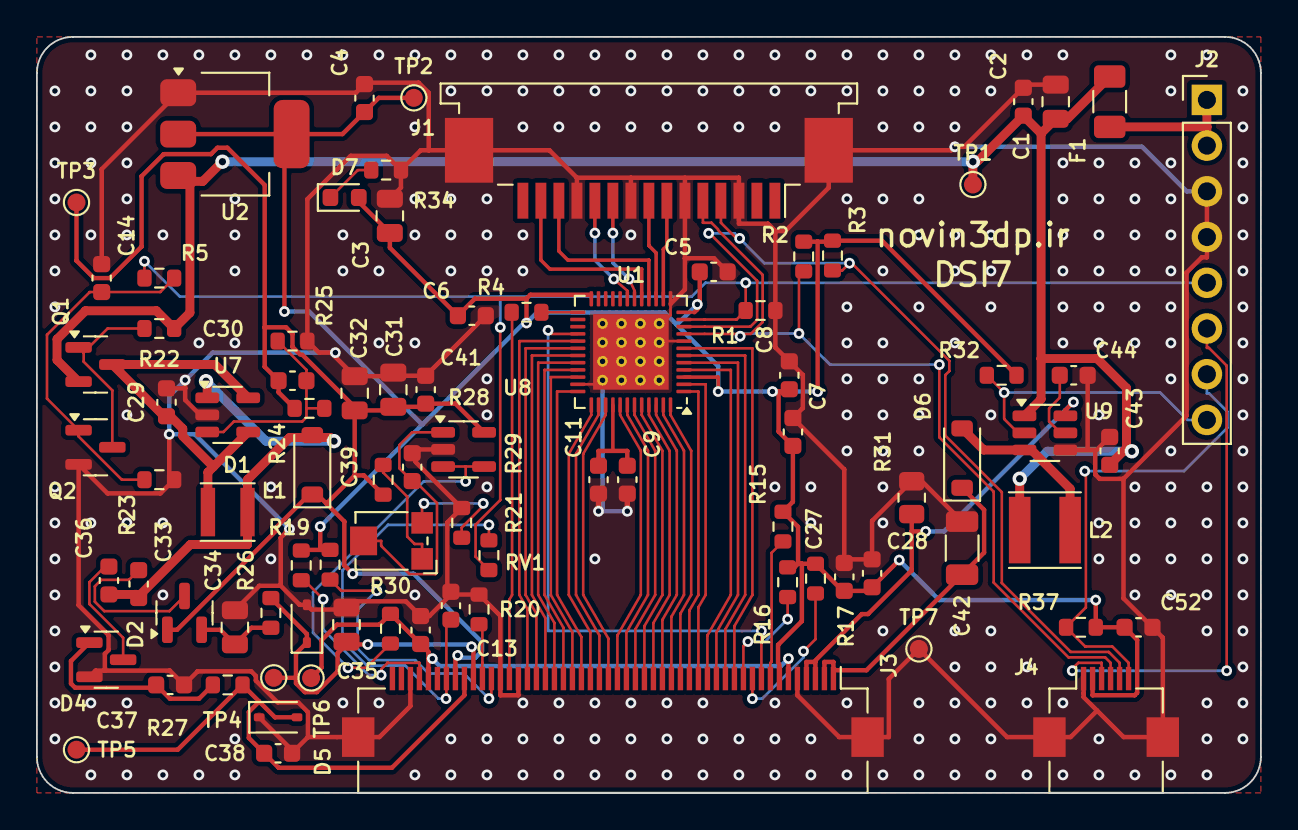
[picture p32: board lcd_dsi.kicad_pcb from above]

Board: 2 copper layers, 68.0 x 42.0 mm, 85 parts (0 on the bottom side), 73 nets.

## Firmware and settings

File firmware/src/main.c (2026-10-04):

/*
 * AT070TN92 HDMI + USB touch driver board firmware (STM32F072CBT6)
 *
 *  - powers the panel in the order required by the AT070TN92 datasheet
 *  - configures the LT8619C HDMI receiver (EDID 800x480@60, RGB888, DE mode)
 *  - backlight only while a valid picture is received
 *  - reads the GT915 touch controller and reports a 5-point USB HID touch screen
 *
 * SPDX-License-Identifier: GPL-2.0-or-later  (lt8619c.c follows GPL Lontium/Hardkernel code)
 */
#include "board.h"
#include "console.h"
#include "gt915.h"
#include "i2c.h"
#include "lt8619c.h"
#include "panel.h"
#include "settings.h"
#include "tusb.h"
#include "usb_touch.h"

void USB_IRQHandler(void)
{
  tud_int_handler(0);
}

static struct touch_report report;
static bool touch_dirty;

static void map_point(const struct gt915_point *p, struct touch_contact *c)
{
  const struct gt915_info *t = gt915_info();
  uint32_t px = p->x, py = p->y, xm = t->x_max, ym = t->y_max;
  if (settings.touch_swap_xy) {
    uint32_t tmp = px;
    px = py;
    py = tmp;
    tmp = xm;
    xm = ym;
    ym = tmp;
  }
  px = px * 800u / (xm ? xm : 800u);
  py = py * 480u / (ym ? ym : 480u);
  if (px > 799) px = 799;
  if (py > 479) py = 479;
  bool ix = settings.touch_invert_x ^ settings.rotate180;
  bool iy = settings.touch_invert_y ^ settings.rotate180;
  c->x = (uint16_t)(ix ? 799 - px : px);
  c->y = (uint16_t)(iy ? 479 - py : py);
}

static void touch_task(void)
{
  static uint32_t last;
  static uint8_t prev_ids[TOUCH_MAX_CONTACTS], prev_n;
  if ((uint32_t)(millis() - last) < 8) {
    return;
  }
  last = millis();
  struct gt915_point pts[GT915_MAX_POINTS];
  int n = gt915_read(pts);
  if (n < 0) {
    return;
  }
  /* report current contacts, plus a final "lifted" entry for contacts that disappeared */
  struct touch_report r = {0};
  int k = 0;
  for (int i = 0; i < n && k < TOUCH_MAX_CONTACTS; i++, k++) {
    r.c[k].flags = 0x03;
    r.c[k].id = pts[i].id & 0x7F;
    map_point(&pts[i], &r.c[k]);
  }
  for (int j = 0; j < prev_n && k < TOUCH_MAX_CONTACTS; j++) {
    bool still = false;
    for (int i = 0; i < n; i++) {
      still |= (pts[i].id & 0x7F) == prev_ids[j];
    }
    if (!still) {
      for (int q = 0; q < TOUCH_MAX_CONTACTS; q++) {
        if (report.c[q].id == prev_ids[j]) {
          r.c[k] = report.c[q];
        }
      }
      r.c[k].flags = 0x00;   /* tip switch released */
      r.c[k].id = prev_ids[j];
      k++;
    }
  }
  r.count = (uint8_t)k;
  prev_n = (uint8_t)n;
  for (int i = 0; i < n; i++) {
    prev_ids[i] = pts[i].id & 0x7F;
  }
  if (k || touch_dirty) {
    report = r;
    touch_dirty = true;
  }
}

static void usb_task(void)
{
  if (touch_dirty && tud_hid_ready()) {
    tud_hid_report(REPORT_ID_TOUCH, &report, sizeof(report));
    touch_dirty = false;
  }
}

static void video_task(void)
{
  static uint32_t last, video_since;
  static bool video;
  if ((uint32_t)(millis() - last) < 100) {
    return;
  }
  last = millis();
  bool ok = lt8619c_poll();
  if (ok && !video) {
    video_since = millis();
    console_printf("video: %ux%u\n", lt8619c_status()->h_active, lt8619c_status()->v_active);
  }
  if (!ok && video) {
    console_printf("video lost\n");
    panel_backlight(false);
  }
  video = ok;
  /* backlight 200 ms (datasheet t10) after the picture became stable */
  if (video && !panel_backlight_is_on() && (uint32_t)(millis() - video_since) > 200) {
    panel_set_brightness(settings.brightness);
    panel_backlight(true);
  }
  gpio_write(PIN_LED, video ? 1 : ((millis() / 500) & 1));
}

int main(void)
{
  board_init();
  console_init();
  settings_load();
  console_printf("\nAT070TN92 HDMI touch board\n");

#ifdef BOARD_F042
  i2c_init(I2C1, I2C_TIMING_400K_48M);   /* one bus: LT8619C and GT915 both support 400 kHz */
#else
  i2c_init(I2C1, I2C_TIMING_100K_48M);
  i2c_init(I2C2, I2C_TIMING_400K_48M);
#endif

  panel_set_orientation(settings.rotate180);
  panel_power_on();

  lt8619c_set_pclk_phase(settings.pclk_phase);
  if (!lt8619c_init()) {
    console_printf("LT8619C not responding\n");
  }
  if (!gt915_init()) {
    console_printf("GT915 not responding\n");
  }

  tusb_init();
  NVIC_EnableIRQ(USB_IRQn);

  for (;;) {
    tud_task();
    video_task();
    touch_task();
    usb_task();
    console_poll();
    if (!lt8619c_status()->present) {
      static uint32_t retry;
      if ((uint32_t)(millis() - retry) > 2000) {
        retry = millis();
        lt8619c_init();
      }
    }
  }
}

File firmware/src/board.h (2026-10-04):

/*
 * AT070TN92 HDMI + USB touch driver board - pin map and low level helpers.
 *   default:      STM32F072CBT6 board, pins must match hardware/gen/design.py (U10)
 *   BOARD_F042:   STM32F042F6P6 board, pins must match hardware_f042/gen/design.py (U10)
 */
#ifndef BOARD_H
#define BOARD_H

#include <stdbool.h>
#include <stdint.h>
#include "stm32f0xx.h"

/* ---- GPIO map ------------------------------------------------------------------ */
#ifdef BOARD_F042
/* TSSOP-20: one I2C bus shared by LT8619C (0x32) and GT915 (0x5D); panel scan direction is set by
 * resistors (R19/R20), there is no HDMI +5V sense input; USB on PA11/PA12 remapped to pins 17/18. */
#define PIN_LT_RSTN      GPIOA, 0    /* LT8619C RESET_N (10k pull-down)                     */
#define PIN_BIAS_EN      GPIOA, 1    /* high = AVDD/VGH/VGL bias supply on                   */
#define PIN_UART_TX      GPIOA, 2    /* USART2 (AF1) debug console, 115200 8N1               */
#define PIN_UART_RX      GPIOA, 3
#define PIN_LCD_RST      GPIOA, 4    /* panel RESET (active low, 10k pull-down)             */
#define PIN_LED          GPIOA, 5
#define PIN_BL_PWM       GPIOA, 6    /* TIM3_CH1 (AF1) -> TPS61165 CTRL                     */
#define PIN_TP_RST       GPIOA, 7
#define PIN_TP_INT       GPIOB, 1
#define PIN_I2C_SDA      GPIOF, 0    /* I2C1 (AF1), shared bus                              */
#define PIN_I2C_SCL      GPIOF, 1
#define LT_I2C           I2C1
#define TP_I2C           I2C1
#define CONSOLE_USART    USART2
#define HAS_SCAN_PINS    0
#define HAS_HDMI5V_DET   0
#else
#define PIN_HDMI5V_DET   GPIOA, 0    /* HDMI +5V divided 22k/33k (3.0 V when cable present) */
#define PIN_BL_PWM       GPIOA, 6    /* TIM3_CH1 (AF1) -> TPS61165 CTRL                     */
#define PIN_BIAS_EN      GPIOA, 8    /* high = AVDD/VGH/VGL bias supply on                   */
#define PIN_UART_TX      GPIOA, 9    /* USART1 (AF1) debug console, 115200 8N1               */
#define PIN_UART_RX      GPIOA, 10
#define PIN_LCD_RST      GPIOB, 0    /* panel RESET (active low, 10k pull-down)             */
#define PIN_LCD_LR       GPIOB, 1    /* panel L/R scan direction                            */
#define PIN_LCD_UD       GPIOB, 2    /* panel U/D scan direction                            */
#define PIN_LT_RSTN      GPIOB, 5    /* LT8619C RESET_N (10k pull-down)                     */
#define PIN_LT_SCL       GPIOB, 6    /* I2C1 (AF1) -> LT8619C (private bus)                 */
#define PIN_LT_SDA       GPIOB, 7
#define PIN_TP_SCL       GPIOB, 10   /* I2C2 (AF1) -> GT915 touch controller                */
#define PIN_TP_SDA       GPIOB, 11
#define PIN_TP_INT       GPIOB, 12
#define PIN_TP_RST       GPIOB, 13
#define PIN_LED          GPIOB, 15
#define LT_I2C           I2C1
#define TP_I2C           I2C2
#define CONSOLE_USART    USART1
#define HAS_SCAN_PINS    1
#define HAS_HDMI5V_DET   1
#endif

/* ---- helpers --------------------------------------------------------------------- */
enum { MODE_IN = 0, MODE_OUT = 1, MODE_AF = 2, MODE_AN = 3 };
enum { PULL_NONE = 0, PULL_UP = 1, PULL_DOWN = 2 };

void gpio_mode(GPIO_TypeDef *port, int pin, int mode, int pull, int af, bool open_drain);
static inline void gpio_write(GPIO_TypeDef *port, int pin, bool v)
{
  port->BSRR = v ? (1u << pin) : (1u << (pin + 16));
}
static inline bool gpio_read(GPIO_TypeDef *port, int pin)
{
  return (port->IDR >> pin) & 1u;
}

void board_init(void);
uint32_t millis(void);
void delay_ms(uint32_t ms);
void delay_us(uint32_t us);

#endif

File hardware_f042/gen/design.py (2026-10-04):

"""
Single source of truth for the AT070TN92 HDMI + USB-touch driver board, STM32F042F6P6 variant.

Everything (schematic, PCB netlist, BOM) is generated from the PARTS list below.
Pin numbers refer to the KiCad library symbol / footprint pad numbers.

Board function
  * HDMI in  -> LT8619C (HDMI RX -> 24-bit TTL RGB, DE mode) -> AT070TN92 50-pin FPC
  * Panel bias: TPS61040 boost (AVDD 10.4 V) + charge pumps (VGH +16 V, VGL -6.8 V)
                + LM321 VCOM buffer with trimmer (2.55 .. 4.5 V)
  * Backlight: TPS61165 constant-current boost, 182 mA, PWM dimming from the MCU
  * STM32F042F6P6 (TSSOP-20): configures LT8619C and reads GT915 touch over ONE shared I2C bus
    (LT8619C 0x32, GT915 0x5D) and presents a USB HID multi-touch digitizer to the Raspberry Pi
    (USB-C, also powers the board).  Differences to the STM32F072 board: one I2C bus, panel L/R and
    U/D scan direction set by resistors, no HDMI +5V sense input.
"""

NC = None  # explicit no-connect


class Part:
    def __init__(self, ref, lib, sym, value, fp, pins, sheet, mpn="", lcsc="", dnp=False, desc=""):
        self.ref, self.lib, self.sym, self.value, self.fp = ref, lib, sym, value, fp
        self.pins = {str(k): v for k, v in pins.items()}
        self.sheet, self.mpn, self.lcsc, self.dnp, self.desc = sheet, mpn, lcsc, dnp, desc


PARTS = []


def P(*a, **k):
    p = Part(*a, **k)
    assert p.ref not in [q.ref for q in PARTS], p.ref
    PARTS.append(p)
    return p


# ---------------------------------------------------------------- footprints
F_R0402 = "Resistor_SMD:R_0402_1005Metric"
F_R0603 = "Resistor_SMD:R_0603_1608Metric"
F_R0805 = "Resistor_SMD:R_0805_2012Metric"
F_C0402 = "Capacitor_SMD:C_0402_1005Metric"
F_C0603 = "Capacitor_SMD:C_0603_1608Metric"
F_C0805 = "Capacitor_SMD:C_0805_2012Metric"
F_C1206 = "Capacitor_SMD:C_1206_3216Metric"
F_FB0603 = "Inductor_SMD:L_0603_1608Metric"
F_SOT23 = "Package_TO_SOT_SMD:SOT-23"
F_SOT235 = "Package_TO_SOT_SMD:SOT-23-5"
F_SOT236 = "Package_TO_SOT_SMD:SOT-23-6"
F_SOT223 = "Package_TO_SOT_SMD:SOT-223-3_TabPin2"
F_SOD123 = "Diode_SMD:D_SOD-123"
F_SOD323 = "Diode_SMD:D_SOD-323"
F_LED0603 = "LED_SMD:LED_0603_1608Metric"
F_TP = "TestPoint:TestPoint_Pad_D1.0mm"


def R(ref, val, a, b, sheet, fp=F_R0603, mpn="", lcsc="", dnp=False):
    return P(ref, "Device", "R", val, fp, {1: a, 2: b}, sheet, mpn=mpn, lcsc=lcsc, dnp=dnp)


def C(ref, val, a, b, sheet, fp=F_C0603, mpn="", lcsc="", dnp=False):
    return P(ref, "Device", "C", val, fp, {1: a, 2: b}, sheet, mpn=mpn, lcsc=lcsc, dnp=dnp)


# common LCSC basic parts (JLCPCB "basic" library)
L_100N = "C14663"    # 100nF 0603 X7R 50V
L_1U = "C15849"      # 1uF 0603 X5R 25V
L_10U0603 = "C19702"  # 10uF 0603 X5R 10V
L_22U0805 = "C45783"  # 22uF 0805 X5R 25V
L_10K = "C25804"     # 0603 1%
L_4K7 = "C23162"
L_1K = "C21190"
L_5K1 = "C23186"
L_100K = "C25803"
L_22P = "C1555"

# =====================================================================
# Sheet 1: power input (USB-C) and regulators
# =====================================================================
S = "power"
P("J2", "Connector", "USB_C_Receptacle_USB2.0_16P", "USB-C (power + touch USB)",
  "Connector_USB:USB_C_Receptacle_HRO_TYPE-C-31-M-12",
  {"A1": "GND", "B1": "GND", "A12": "GND", "B12": "GND",
   "A4": "VBUS", "A9": "VBUS", "B4": "VBUS", "B9": "VBUS",
   "A5": "USB_CC1", "B5": "USB_CC2",
   "A6": "USB_DP", "B6": "USB_DP", "A7": "USB_DM", "B7": "USB_DM",
   "A8": NC, "B8": NC, "S1": "GND"}, S, mpn="HRO TYPE-C-31-M-12", lcsc="C165948")
R("R1", "5.1k", "USB_CC1", "GND", S, lcsc=L_5K1)
R("R2", "5.1k", "USB_CC2", "GND", S, lcsc=L_5K1)
P("F1", "Device", "Polyfuse_Small", "PTC 1.1A hold", "Fuse:Fuse_1206_3216Metric",
  {1: "VBUS", 2: "+5V"}, S, mpn="1206L110/16 (or BSMD1206-110)", lcsc="")
P("U4", "Power_Protection", "USBLC6-2SC6", "USBLC6-2SC6", F_SOT236,
  {1: "USB_DM", 6: "USB_DM", 3: "USB_DP", 4: "USB_DP", 2: "GND", 5: "+5V"}, S,
  mpn="USBLC6-2SC6", lcsc="C7519")
C("C1", "22uF", "+5V", "GND", S, fp=F_C0805, lcsc=L_22U0805)
C("C2", "100nF", "+5V", "GND", S, lcsc=L_100N)

P("U2", "Regulator_Linear", "AMS1117-3.3", "AMS1117-3.3", F_SOT223,
  {1: "GND", 2: "+3V3", 3: "+5V"}, S, mpn="AMS1117-3.3", lcsc="C6186")
C("C3", "22uF", "+3V3", "GND", S, fp=F_C0805, lcsc=L_22U0805)
C("C4", "100nF", "+3V3", "GND", S, lcsc=L_100N)
P("U3", "Regulator_Linear", "AMS1117-1.8", "AMS1117-1.8", F_SOT223,
  {1: "GND", 2: "+1V8", 3: "+5V"}, S, mpn="AMS1117-1.8", lcsc="C6187")
C("C5", "22uF", "+1V8", "GND", S, fp=F_C0805, lcsc=L_22U0805)
C("C6", "10uF", "+5V", "GND", S, fp=F_C0603, lcsc=L_10U0603)

# quiet analog rails for the LT8619C
P("FB1", "Device", "FerriteBead_Small", "600R@100MHz", F_FB0603, {1: "+1V8", 2: "+1V8A"}, S,
  mpn="BLM18PG601SN1D", lcsc="C1015")
C("C7", "10uF", "+1V8A", "GND", S, fp=F_C0603, lcsc=L_10U0603)
P("FB2", "Device", "FerriteBead_Small", "600R@100MHz", F_FB0603, {1: "+3V3", 2: "+3V3A"}, S,
  mpn="BLM18PG601SN1D", lcsc="C1015")
C("C8", "10uF", "+3V3A", "GND", S, fp=F_C0603, lcsc=L_10U0603)

for i, n in enumerate(["+5V", "+3V3", "+1V8", "AVDD", "VGH", "VGL", "VCOM", "GND"]):
    P("TP%d" % (i + 1), "Connector", "TestPoint", n, F_TP, {1: n}, S)

# =====================================================================
# Sheet 2: HDMI input and LT8619C
# =====================================================================
S = "hdmi"
P("J1", "Connector", "HDMI_A", "HDMI-A receptacle", "Connector_HDMI:HDMI_A_Amphenol_10029449-x01xLF_Horizontal",
  {1: "TMDS_D2_P", 2: "GND", 3: "TMDS_D2_N", 4: "TMDS_D1_P", 5: "GND", 6: "TMDS_D1_N",
   7: "TMDS_D0_P", 8: "GND", 9: "TMDS_D0_N", 10: "TMDS_CK_P", 11: "GND", 12: "TMDS_CK_N",
   13: NC, 14: NC, 15: "HDMI_SCL", 16: "HDMI_SDA", 17: "GND", 18: "HDMI_5V",
   19: "HDMI_HPD", "SH": "GND"}, S, mpn="Amphenol 10029449-001RLF (or equivalent SMT HDMI-A)")
R("R3", "1k", "LT_HPD", "HDMI_HPD", S, lcsc=L_1K)
R("R4", "100k", "HDMI_HPD", "GND", S, lcsc=L_100K)
R("R5", "47k", "HDMI_SCL", "HDMI_5V", S, lcsc="C25792")
R("R6", "47k", "HDMI_SDA", "HDMI_5V", S, lcsc="C25792")
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

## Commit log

2026-10-02 Add 2-layer HDMI + USB-touch driver board for AT070TN92 7" LCD
    Hardware (KiCad 7, generated from hardware/gen/design.py):
    - LT8619C HDMI receiver -> 24-bit TTL RGB (DE mode) to the 50-pin panel FPC
    - Panel bias from 5 V: TPS61040 boost (AVDD 10.4 V), charge pumps for
    VGH +16 V / VGL -6.8 V, LM321 VCOM buffer with trimmer
    - TPS61165 constant-current backlight driver (182 mA, PWM dimming)
    - STM32F072 crystal-less USB: LT8619C setup and GT915 touch -> USB HID
    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
    [bom_jlcpcb.csv, lcd_board.kicad_pcb, lcd_board.kicad_sch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]
2026-10-02 Use 0603 passives and remove the alternative touch connector J6
    - All 0402 resistors/capacitors are now 0603 (LCSC numbers updated to the
    matching 0603 basic parts); bulk/high-voltage caps stay 0805/1206
    - J6 (JST-SH touch header) removed
    - LT8619C decoupling pre-routes, crystal and REXT placement adapted to the
    larger footprints; RGB bus escape area under the chip kept free
    - Re-routed (Freerouting 2.0.1), DRC: 0 errors, 0 unconnected
    - Schematic, BOM/CPL, gerbers, images and README regenerated
    Claude-Session: https://claude.ai/code/session_01X8BrieHZtCS6HfoR48ML9y
    [bom_jlcpcb.csv, lcd_board.kicad_pcb, lcd_board_hdmi.kicad_sch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]
2026-10-02 Place silkscreen reference designators without overlaps
    - New hardware/gen/silk.py: every reference label (0.8 mm) is placed next
    to its part, never on pads, component bodies, silkscreen outlines or
    other labels; labels that do not fit nearby are hidden (still on F.Fab)
    - Removed the "pin1" text on J3 that was clipped by the solder mask
    - DRC: 0 silkscreen overlaps; gerbers, images and README updated
    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
    [lcd_board.kicad_pcb]
2026-10-02 Add "novin3dp.ir HDMI7" to the top silkscreen
    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
    [lcd_board.kicad_pcb]
2026-10-03 Add Raspberry Pi DSI version of the AT070TN92 driver board
    New, separate 2-layer board (68x42 mm) in hardware_dsi/ that drives the
    panel straight from the Pi DSI port through a Chipone ICN6211 DSI->RGB888
    bridge. The HDMI board in hardware/ is unchanged.
    - No HDMI receiver, crystal, MCU or USB: GT915 touch sits on the DSI
    connector's I2C bus and is read by the Linux goodix driver.
    - 5 V and four GPIOs (bridge EN, touch INT/RST, backlight) come from
    the Pi 40-pin header via J2.
    - Panel RESET and bias supplies follow the bridge EN line through RC
    delays, so power sequencing needs no firmware.
    - The DSI pairs and the whole RGB bus are hand-routed; Freerouting
    does the rest. DRC: 0 erro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
    [bom_jlcpcb.csv, lcd_dsi.kicad_pcb, lcd_dsi.kicad_sch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]
2026-10-04 Add STM32F042F6P6 version of the HDMI7 board, fix I2C pin setup
    hardware_f042/ is a separate KiCad project: the HDMI board with the
    STM32F072CBT6 (LQFP-48) replaced by an STM32F042F6P6 (TSSOP-20). Same
    80x50 mm outline and parts otherwise; routed again, DRC 0 errors and 0
    unconnected, schematic netlist matches design.py.
    The 20-pin part has one I2C and 15 I/Os, so:
    - LT8619C and GT915 share one I2C bus on PF0/PF1 at 400 kHz (2.2k
    pull-ups); R35/R36 removed.
    - Panel L/R and U/D scan direction are set by straps R19/R20.
    - The HDMI +5V sense divider (R8/R9) is removed.
    - USB on PA11/PA12 (pins 17/18 remapped); console on USART2 (PA2/PA3).
    The firmware builds for either board: make BOARD=f04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
    [bom_jlcpcb.csv, lcd_f042.kicad_pcb, lcd_f042.kicad_sch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]
2026-10-04 F042 board: move the USB-C next to the HDMI receptacle
    The USB-C now sits on the left edge right under the HDMI socket, so
    both Raspberry Pi cables leave the board on the same side.
    - The USB D+/D-/VBUS pre-routes are rotated with the connector.
    - The ESD array U4 moves onto the USB path toward the MCU, since there
    is no room beside the connector.
    - The bias switch (Q1/Q2/R22/R23/C29) and TPS61040 (U7, L1) move to
    make room; the parts that had to move are placed last so the rest
    keeps its position.
    - Routed copper keeps 0.5 mm from the board edge.
    Rerouted: DRC 0 errors, 0 unconnected, netlist matches design.py.
    Claude-Session: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
    [lcd_f042.kicad_pcb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]
2026-10-18 Add dual-MCU HDMI7 board: STM32F072 or CH32X035C8T6 on one footprint
    hardware_dual/ is the original HDMI board with one LQFP-48 footprint
    that takes either an STM32F072CBT6 or a CH32X035C8T6. On LQFP-48 the
    two chips share USB D-/D+ (32/33), SWDIO/SWCLK (34/37), reset (7) and
    VDD/GND (48/47), and every other board signal lands on a usable CH32
    GPIO (backlight PWM on TIM3_CH1, console on USART1).
    Added SW2 + R38 to pull D+ high at power-up, which starts the CH32 USB
    bootloader; it has no effect on the STM32. The README lists the
    STM32 supply pins that are GPIOs on the CH32 and must stay inputs.
    Rerouted: DRC 0 errors, 0 unconnected, netlist matches design.py. The
    CH32 firmware is not writte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
2026-10-18 Dual board: aligned passives; firmware: CH32X035 port
    PCB (hardware_dual):
    - Add a tidy pass after legalize: nearby resistors and capacitors are
    lined up in rows and columns, set to the same orientation and
    snapped to a 0.25 mm grid. A move is kept only if the courtyard
    stays clear (39 parts aligned).
    - Rerouted: DRC 0 errors, 0 unconnected, netlist matches design.py.
    Firmware:
    - Chip-specific code (clock, GPIO, PWM, UART, flash, I2C, USB IRQ)
    now lives behind a small board HAL in src/stm32/ and src/ch32/.
    LT8619C, GT915, USB HID, panel, console and settings logic are
    shared. Both STM32 builds compile without warnings, at the same
    sizes as before.
    - New target make BOARD=ch32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
2026-10-18 Dual board: move the USB-C next to the HDMI receptacle
    Same change as on the F042 board: the USB-C sits on the left edge
    under the HDMI socket, so both Raspberry Pi cables leave on one side.
    The USB pre-routes rotate with the connector, the ESD array moves onto
    the USB path, and the bias switch, TPS61040 and fuse are moved to make
    room. The logo text moves to the space the USB-C freed on the right.
    Routed copper keeps 0.5 mm from the board edge.
    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
2026-10-18 Dual board: all vias 0.6 mm pad / 0.4 mm drill
    Every via (signal, power and GND stitching) is now 0.6 mm outer
    diameter with a 0.4 mm hole. The routing is reused unchanged: the
    outer diameter stays 0.6 mm and the 15 former 0.8 mm power vias
    shrink, so no copper clearance changes. route.py import applies the
    via size from pcb.py; the net classes and the project file use
    0.6/0.4. DRC: 0 errors, 0 unconnected.
    The thermal vias in the LT8619C exposed pad are footprint pads and
    stay 0.3 mm.
    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
2026-10-18 Dual board: vias 0.7 mm pad / 0.4 mm drill
    All 463 vias are now 0.7 mm outer diameter with a 0.4 mm hole (0.15 mm
    annular ring). The board was fully rerouted for the larger pads.
    DRC 0 errors, 0 unconnected, netlist matches design.py.
    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
2026-10-21 Dual board: TPS61169DCKR backlight driver
    - U9 TPS61165 (SOT-23-6) -> TPS61169DCKR (SC70-5) per the TI datasheet:
    1 SW, 2 GND, 3 FB, 4 CTRL, 5 VIN; new project symbol; internal
    compensation, so C44 is removed.
    - R31 1.13 R 1%: 204 mV reference -> 180 mA LED current.
    - 20 kHz PWM on CTRL (datasheet 5..100 kHz), 10 uH inductor (4.7..10 uH),
    2.2 uF output capacitor (1..10 uF) are unchanged; firmware unchanged.
    - Rerouted (0.7/0.4 vias): first pass plus a second pass for the last
    net (lcd_dual_stage2.ses); route.py import now prunes unused stubs.
    Claude-Session: https://clau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
2026-10-21 Dual board: Q1 AO3401A -> AO3415
    Checked against the AOS AO3415 datasheet (Rev 7): -20 V VDS, +/-8 V VGS
    (the gate only sees 0 / -5 V), RDS(on) < 41 mOhm at -4.5 V, same SOT-23
    pinout (1 G, 2 S, 3 D). Footprint and routing unchanged; schematic
    and BOM updated (the AO3401A LCSC number is dropped).
    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
